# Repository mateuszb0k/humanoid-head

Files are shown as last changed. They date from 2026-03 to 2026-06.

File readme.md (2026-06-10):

# Humanoid Head

Humanoid Head is a modular robotics project focused on building an interactive humanoid robot head. The project combines computer vision, speech processing, natural language understanding, local language models, text-to-speech synthesis, servo-driven facial animation, and 3D-printed mechanical design.

The system is designed to recognize people, detect visible emotions, understand spoken questions, generate natural voice responses, and express emotions through physical facial movement.

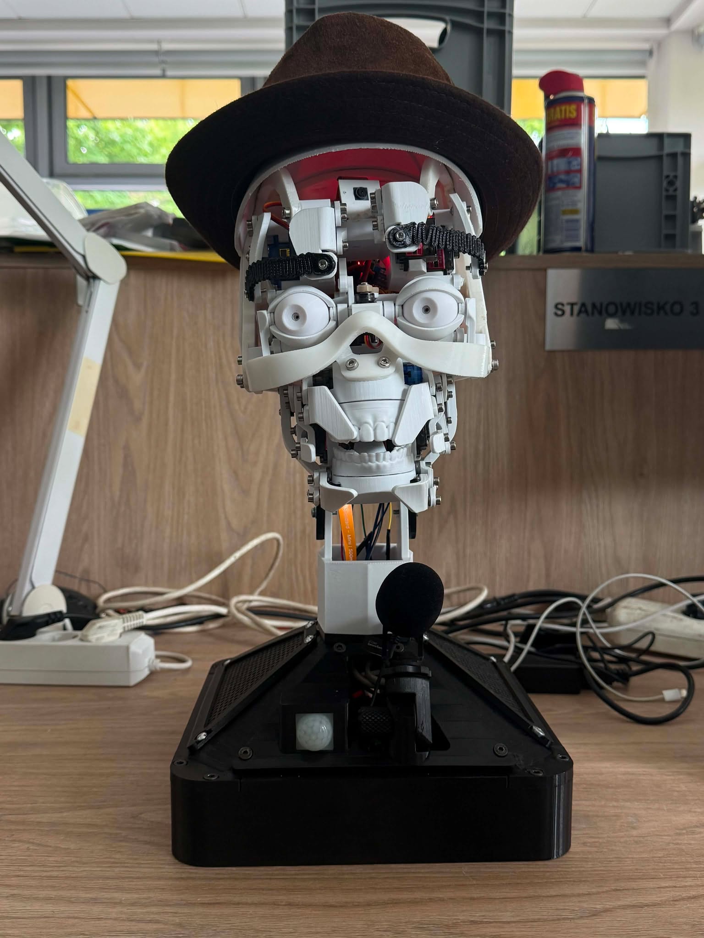
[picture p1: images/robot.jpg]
Uncanny head


## Project Overview

The robot head is built as a distributed system using two main computing devices:

- Raspberry Pi 5, responsible for vision processing, camera input, face recognition, emotion recognition, and facial actuation.
- NVIDIA Jetson Orin Nano, responsible for speech recognition, natural language processing, local language model inference, and speech synthesis.

The project is divided into three main modules:

- `vision-module`
- `speech-module`
- `hardware-module`

Each module was developed separately and later integrated into the final project.

## System Architecture

```text
User
 │
 │  voice, face, emotion
 ▼
Camera and Microphone
 │
 ├── Raspberry Pi 5
 │   ├── Face detection
 │   ├── Face recognition
 │   ├── Emotion recognition
 │   ├── Servo control
 │   └── Facial expression control
 │
 └── NVIDIA Jetson Orin Nano
     ├── Speech-to-text
     ├── Intent detection
     ├── Entity extraction
     ├── Local LLM response generation
     ├── Text-to-speech
     └── Conversation logic
```

The Raspberry Pi and Jetson communicate over the local network. The Raspberry Pi provides the speech pipeline with visual context, such as whether a person is visible, who the person is, and what emotion was detected. The Jetson generates spoken responses and sends mouth movement information back to the Raspberry Pi so that the robot jaw can move in sync with speech.

## How the Project Works

The project works as a real-time interaction loop between the user, the vision system, the speech system, and the physical robot head.

### 1. User Detection

The camera captures a live video stream. The vision module processes frames from the camera and searches for a visible face.

When a face is detected, the system determines:

- whether a person is currently in front of the robot,
- whether the person is already known,
- what emotion is visible on the face.

This information is sent to the speech module so that the robot can respond in a more context-aware way.

### 2. Face Recognition

The vision module can identify known users using stored face data. If the user is recognized, their identity is passed to the speech module.

This allows the robot to personalize its responses, for example by addressing the user by name or remembering context during an active interaction.

If the user is unknown, the system can treat the interaction as a new user session.

### 3. Emotion Recognition

The vision module classifies the user’s facial expression into emotional states such as:

- happy,
- sad,
- angry,
- fear,
- disgust,
- surprise,
- neutral.

The detected emotion is passed to the speech module and can also influence the robot’s physical facial expression.

The physical head supports servo-driven expression changes, allowing the robot to imitate or react to emotional states.

### 4. Speech Recognition

The speech module listens for the user’s spoken question or command.

Speech is converted to text using a speech-to-text pipeline based on Whisper or Faster Whisper. The transcribed text is then passed into the natural language processing pipeline.

The system is designed for spoken interaction, so the conversation flow assumes that the user is standing in front of the robot and speaking naturally.

### 5. Intent Detection

After transcription, the system determines what kind of request the user made.

The speech module can recognize different categories of intent, including:

- general conversation,
- weather questions,
- questions about rooms,
- questions about teachers,
- questions about auditoriums or special locations,
- project-specific or assistant-style questions.

Intent detection allows the system to choose whether it should answer using a local database, a rule-based lookup, or a local language model.

### 6. Entity Extraction

For location-related questions, the system extracts important entities from the user’s sentence.

Examples of extracted entities include:

- room numbers,
- building identifiers,
- teacher names,
- auditorium names,
- special places such as libraries, cloakrooms, or cafeterias.

The project uses GLiNER and supporting utility logic to detect and normalize these entities before searching the local data files.

### 7. Local Knowledge Lookup

For structured questions, the system searches local data files instead of relying only on a language model.

The speech module includes logic for:

- finding room directions,
- finding teacher room assignments,
- searching for special rooms,
- handling auditorium-related questions,
- retrieving weather information.

This gives the robot more reliable answers for known project-specific information.

### 8. Local LLM Response Generation

For general conversation, the system uses a local language model through Ollama and LangChain.

The language model receives context such as:

- the user’s question,
- recent conversation history,
- recognized user identity,
- detected emotion.

This allows the robot to generate more natural and context-aware spoken responses.

The prompt is designed specifically for a physical voice assistant. It avoids text-chat behavior and encourages natural spoken answers suitable for text-to-speech output.

### 9. Text-to-Speech

After generating a response, the speech module converts the text into audio using Piper TTS.

The generated audio is played through the speaker connected to the Jetson.

At the same time, the speech module estimates the audio intensity and sends mouth movement values to the Raspberry Pi. This allows the jaw servo to move in sync with the spoken response.

### 10. Facial Movement and Servo Control

The Raspberry Pi controls the robot’s servos through a servo controller.

The hardware system includes multiple servos responsible for facial movement, including areas such as:

- mouth,
- jaw,
- eyes,
- eyebrows,
- facial expression elements.

The system maps emotional states to predefined servo positions. For example, happy, sad, surprise, and neutral expressions are represented by different servo angle configurations.

Servo limits are defined to protect the mechanical structure and prevent unsafe movement.

## Module Descriptions

## Vision Module

The `vision-module` contains the computer vision and Raspberry Pi runtime code.

Main responsibilities:

- camera input,
- face detection,
- face recognition,
- emotion recognition,
- Raspberry Pi camera diagnostics,
- communication with the speech module,
- servo control integration,
- facial movement logic.

Important areas:

```text
vision-module/src/rpi/
vision-module/src/detection/
vision-module/model_training/
vision-module/preprocessing/
vision-module/documentation/
vision-module/images/
```

The main Raspberry Pi runtime is located in:

```text
vision-module/src/rpi/main_vision_network.py
```

This file combines the vision pipeline with robot control logic. It handles face visibility, identity, emotion, expression mapping, and communication with the rest of the system.

## Speech Module

The `speech-module` contains the Jetson-side speech and NLP pipeline.

Main responsibilities:

- speech-to-text,
- intent detection,
- entity extraction,
- local LLM interaction,
- text-to-speech,
- conversation memory,
- user identity handling,
- weather responses,
- room and teacher lookup,
- auditorium and special room lookup,
- communication with the Raspberry Pi.

Important files and directories:

```text
speech-module/nlp_pipeline.py
speech-module/nlp_pipeline_jetson_test.py
speech-module/utils/
speech-module/PiperTTS/
speech-module/db_specialrooms.json
speech-module/imiona_polskie.txt
```

The Jetson test pipeline is located in:

```text
speech-module/nlp_pipeline_jetson_test.py
```

This file orchestrates the main speech interaction loop. It receives data from the vision system, listens to the user, generates a response, speaks the answer, and sends mouth movement data back to the Raspberry Pi.

## Hardware Module

The `hardware-module` contains the mechanical and electronics-related project files.

Main responsibilities:

- 3D model storage,
- printed head structure documentation,
- servo placement documentation,
- circuit documentation,
- servo testing scripts,
- jaw synchronization experiments,
- face animation prototypes,
- hardware reports.

Important areas:

```text
hardware-module/3Dmodel/
hardware-module/Code/
hardware-module/DescServos/
hardware-module/Raports/
hardware-module/Circuit Diagram.pdf
```

The hardware module documents how the physical robot head is built and how the servos are assigned to facial movements.

## Data Flow

The project uses the following high-level data flow:

```text
Camera frame
   ↓
Face detection
   ↓
Face recognition and emotion recognition
   ↓
Identity and emotion sent to speech module
   ↓
User speaks
   ↓
Speech-to-text
   ↓
Intent detection and entity extraction
   ↓
Database lookup or local LLM response
   ↓
Text-to-speech
   ↓
Audio playback
   ↓
Mouth movement signal sent to Raspberry Pi
   ↓
Servo-controlled facial movement
```

## Communication Between Devices

The Raspberry Pi and Jetson communicate through HTTP endpoints over the local network.

The Raspberry Pi sends visual context to the Jetson, including:

- face visibility,
- recognized identity,
- detected emotion.

The Jetson sends mouth movement information to the Raspberry Pi, including:

- current speech volume level,
- jaw movement intensity,
- stop/reset mouth movement signal.

This split allows the Raspberry Pi to focus on real-time physical control while the Jetson handles heavier AI workloads.

## Conversation Logic

The conversation system is designed around real spoken interaction.

The assistant is prompted to behave as a physical robotic head rather than a text chatbot. It avoids responses that refer to typing, screens, chats, or written interaction.

The response generation logic considers:

- the current user,
- the detected emotion,
- the recent conversation history,
- the user’s latest question,
- whether the request should be answered from structured data or by the LLM.

The system also maintains a short conversation buffer so that responses can remain coherent during a session.

## Knowledge and Utility Features

The speech module includes several utility systems for specific types of questions.

### Room Search

The robot can answer questions about rooms by extracting room identifiers and searching local room data.

### Teacher Search

The robot can search for teacher information and provide room-related responses when the teacher exists in the local database.

### Auditorium and Special Room Search

The robot can respond to questions about auditoriums and selected special locations such as libraries, cloakrooms, or cafeterias.

### Weather

The robot can provide weather-related responses through the weather utility module.

## Facial Expressions

The robot can physically represent selected emotional states using servo positions.

Supported or planned expressions include:

- neutral,
- happy,
- sad,
- surprise,
- angry,
- fear,
- disgust.

Each expression is represented by a set of servo angle targets. These targets move different parts of the robot face to create a visible expression.

The emotion system is connected to both:

- detected user emotion,
- generated conversational state.

## Hardware Design

The physical head is based on a 3D-printed structure with multiple servos installed inside the face.

The hardware documentation includes:

- printable mechanical components,
- base structure,
- servo mapping,
- circuit diagram,
- assembly-related photos,
- test scripts,
- reports.

The servo system is designed to control facial motion while respecting mechanical limits.

## Technology Stack

### Hardware

- Raspberry Pi 5 8 GB
- NVIDIA Jetson Orin Nano Super 8 GB
- Raspberry Pi camera
- microphone
- speaker
- servo controller
- MG90s servos
- MG996r servos
- NVMe SSD
- DC-DC converters
- 3D-printed parts
- mechanical fasteners

### Software

- Python
- TensorFlow
- PyTorch
- OpenCV
- MediaPipe
- BlazingFace
- Whisper
- Faster Whisper
- Piper TTS
- GLiNER
- LangChain
- Ollama
- Flask
- PyAudio
- speech_recognition
- NumPy
- scikit-learn

## Development Branches

The project was developed across multiple branches.

### `master`

The main integration branch. It contains the merged version of the project with all major modules combined.

### `vision-module`

Contains the vision subsystem, including camera processing, recognition models, Raspberry Pi scripts, and visual-to-physical behavior integration.

### `speech-module`

Contains the speech and NLP subsystem, including STT, intent detection, GLiNER extraction, LLM response generation, TTS, and Jetson-side runtime logic.

### `hardware-module`

Contains the mechanical, electrical, and servo-related work, including 3D models, circuit diagrams, servo documentation, and hardware test code.

## Project Milestones

The project was planned around several technical milestones:

1. Building and validating the physical robot head structure.
2. Preparing power, servo, and mechanical control systems.
3. Creating a vision pipeline for recognition and emotion detection.
4. Creating a speech pipeline with STT, LLM, and TTS.
5. Running AI workloads across Raspberry Pi and Jetson hardware.
6. Integrating vision, speech, and facial actuation.
7. Testing real-time interaction with users.
8. Synchronizing jaw movement with generated speech.
9. Validating complete robot behavior in a controlled environment.

## Repository Language Composition

The repository is primarily written in Python, with additional Shell scripts and Jupyter Notebook content used for supporting tasks such as setup, testing, experimentation, or model-related work.

## Intended Use

This project is intended for research, prototyping, and educational development of an interactive humanoid robotic head.

It demonstrates how multiple AI and robotics components can be integrated into one physical system:

- perception,
- speech interaction,
- language understanding,
- local AI inference,
- mechanical expression,
- embedded device coordination.

## Notes

This project depends on correct hardware assembly, calibrated servos, configured camera and audio devices, local network connectivity between devices, and available machine learning model files.

Because the robot controls physical servos, all mechanical limits and power requirements should be checked carefully during development and testing.

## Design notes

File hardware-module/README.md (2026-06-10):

# Repository Structure: Hardware Module

This document provides a detailed overview of the directory structure and the contents of this repository.

## Directory Descriptions

### 3Dmodel
Contains the complete mechanical design and 3D assets for the robot's head assembly.
- **Photos**: A collection of images documenting the physical fabrication process, including both successful components and failed print attempts for reference.
- **Base**: Includes 3D models of electronic components (e.g., NVIDIA Jetson Nano) and the structural design of the robot's base.
- **head stl**: Contains individual .stl files for every component of the robot's head, optimized for 3D printing.
- **printing_progress.md**: A tracking file used to document the status and timeline of the 3D printing process for various parts.

### Code
Stores source code and scripts used during the development phase.
- Includes test scripts and firmware developed for Arduino and Raspberry Pi platforms to validate hardware functionality.

### DescServos
Dedicated to the robot's actuation system.
- Provides visual representations of servo placement within the assembly.
- Contains indexing and detailed descriptions mapping each servo to its specific anatomical movement or functional responsibility.

### Raports
A repository for documentation related to project management.
- Includes meeting minutes and formal progress reports generated by the hardware development team.

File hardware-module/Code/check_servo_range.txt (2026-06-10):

#include <Arduino.h>
#include <Wire.h>
#include <Adafruit_PWMServoDriver.h>

Adafruit_PWMServoDriver driver0 = Adafruit_PWMServoDriver(0x40); 
Adafruit_PWMServoDriver driver1 = Adafruit_PWMServoDriver(0x41);

#define PWM_MIN 150 
#define PWM_MAX 600 

struct ServoConfig {
  uint8_t driverID;
  uint8_t pin;          
  int minAngle;         
  int maxAngle;         
};

ServoConfig servos[21] = {
  {0, 0, 0, 180}, {0, 1, 0, 180}, {0, 2, 0, 180}, {0, 3, 0, 180}, {0, 4, 0, 180},
  {0, 5, 0, 180}, {0, 6, 0, 180}, {0, 7, 0, 180}, {0, 8, 0, 180}, {0, 9, 0, 180},
  {0, 10, 0, 180},
  {1, 0, 0, 180}, {1, 1, 0, 180}, {1, 2, 0, 180}, {1, 3, 0, 180}, {1, 4, 0, 180},
  {1, 5, 0, 180}, {1, 6, 0, 180}, {1, 7, 0, 180}, {1, 8, 0, 180}, {1, 9, 0, 180} 
};

int getPWM(int angle) {
  return map(angle, 0, 180, PWM_MIN, PWM_MAX);
}

void setup() {
  Serial.begin(9600);
  
  driver0.begin();
  driver0.setPWMFreq(50);

  driver1.begin();
  driver1.setPWMFreq(50);
}

void loop() {
  if (Serial.available() > 0) {
    int id = Serial.parseInt();
    int targetAngle = Serial.parseInt();

    while (Serial.available() > 0) Serial.read();

    if (id >= 0 && id < 21) {
      targetAngle = constrain(targetAngle, servos[id].minAngle, servos[id].maxAngle);
      int pulse = getPWM(targetAngle);
      
      if (servos[id].driverID == 0) {
        driver0.setPWM(servos[id].pin, 0, pulse);
      } else {
        driver1.setPWM(servos[id].pin, 0, pulse);
      }
      
      Serial.print("ID: "); Serial.print(id);
      Serial.print(" -> "); Serial.println(targetAngle);
    }
  }
}

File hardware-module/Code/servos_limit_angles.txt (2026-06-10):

servo 0 - tongue doesn't move
servo 1 - jaw max open 80, max closed 125
servo 2 - right corner upper servo, max down 50, max up 65
servo 3 - right upper lip, max down 20, max up 80
servo 4 - right corner lower servo, max down 50, max up 70
servo 5 - right lower lip, max down 25, max up 92
servo 6 - left lower lip, 110 max down, 45 max up
servo 7 - left corner lower servo, initially 60 down, 40 up
servo 8 - left upper lip, max down 85, max up 35
servo 9 - left corner upper servo, 10 max up, initially 40 max down
servo 10 - jaw works mirrored to servo 1
servo 11 - 80 close, 0 open // right eye lower eyelid
servo 12 - 115 degrees max open, 30 min (closed) upper eyelid
servo 13 - eyes up-down, 60 center, 120 max up, 40 max down
servo 14 - eyes right-left, 100 center, 50 max right, 150 max left
servo 15 - 90 close, 20 open // left eye upper eyelid
servo 16 - 90 open, 25 close lower eyelid
servo 17 - right eyebrow outside, 150 max up, 70 max down
servo 18 - right eyebrow center, 160 max down, 70 max up
servo 19 - left eyebrow center, 170 max up, 80 max down
servo 20 - left eyebrow outside, 100 max down, 20 max up

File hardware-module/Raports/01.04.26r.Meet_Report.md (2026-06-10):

# MEETING REPORT: Hardware Team – Robot Head Project
# Date: July 01, 2026
# Attendees: Szymon Mielniczak, Mateusz Kuczerowski, Adam Błażejewski, Patryk Jakiel
# Subject: Servo Configuration, Electrical Refinement & Movement Logic

---

## 1. MEETING OBJECTIVES
The primary goal was to define the software-to-hardware mapping, establish safety protocols for the servomechanisms, and plan the development of emotional expressions.

## 2. SOFTWARE & SERVO CONFIGURATION
* **Servo Addressing:** We initiated the process of mapping physical servos to their digital addresses in the control system.
* **Safety Limits:** The team discussed the necessity of establishing individual hardware limits (min/max PWM angles) for each servo to prevent mechanical binding and over-extension.
* **Movement Code:** Initial development of the servo control algorithms has begun, focusing on smooth transitions and coordinated movements.
* **Expression Logic:** Preliminary discussions took place regarding the implementation of "emotions" – mapping multiple servo movements to specific emotional states.

## 3. ELECTRICAL & MECHANICAL REFINEMENTS
* **Wiring Standards:** A plan was established to finalize the electrical schematic following the completion of servo addressing. 
* **Reliability:** We decided to rework the wire terminations using a crimping tool (crimper) to ensure professional and secure electrical connections.
* **Fastener Security:** To address the recurring issue of loosening screws in the lips and eyebrows, we evaluated two solutions:
    * Application of thread-locking fluid (Loctite/Threadlocker).
    * Integration of nylon-insert lock nuts (Nyloc) where space allows.

## 4. NEXT STEPS
* **Stand Design:** Work has officially started on the design of the robot head stand/base.
* **Execution:** During the next meeting, we will finalize the physical addressing and hard-code the safety limits for all servos.
* **Refining Connections:** Conduct a full recrimping of all connector ends to eliminate potential intermittent signal issues.

---
Prepared by: [Szymon Mielniczak]
Status: Finalized

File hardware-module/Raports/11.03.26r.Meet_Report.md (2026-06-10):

# MEETING REPORT: Hardware Team – Robot Head Project
# Date: March 11, 2026
# Attendees: Szymon Mielniczak, Mateusz Kuczerowski, Adam Błażejewski, Patryk Jakiel
# Subject: CAD Model Analysis & Hardware Specification

---

## 1. MEETING OBJECTIVES
The primary goal was to analyze the main CAD assembly in Fusion 360, finalize the decomposition of components for manufacturing, and establish the requirements for fasteners and custom parts.

## 2. FUSION 360 ANALYSIS & ASSEMBLY STRATEGY
* **Model Decomposition:** The master assembly has been successfully separated into individual components (Internal Frame, Actuation Mechanisms, and External Shell).
* **Assembly Plan:** The team has analyzed the construction in detail and established a clear workflow for the assembly process in the coming weeks. We have a full understanding of the sequence required to integrate the internal skeleton with the outer casing.
* **Design Review:** A structural analysis was conducted to ensure that all 3D-printed parts are optimized for assembly and mechanical durability.

## 3. HARDWARE & FASTENERS SPECIFICATION
The following components have been selected for the build:

* **Screws:** Socket Head Cap Screws (Allen/Hex drive) in sizes **M2.5, M3, and M4**. 
    * We will use various lengths depending on the joint, with a **maximum length of 10mm**.
* **Washers:** Standard flat and spring washers.
* **Nuts:** Standard hex nuts.
* **Threaded Inserts:** **IMPORTANT: We will use bidirectional (two-way) threaded inserts** to ensure maximum pull-out resistance and stability within the 3D-printed parts.
* **Custom Spacers:** The team will design and 3D print custom bushings/spacers to ensure precise alignment of internal mechanisms.

## 4. NEXT STEPS
* **Custom Part Design:** Finalize CAD models for the 3D-printed spacers in Fusion 360.
* **Shopping:** Purchase the rest of the needed equipment, including servos, screws, and other mechanical components.
---
Prepared by: [Szymon Mielniczak]

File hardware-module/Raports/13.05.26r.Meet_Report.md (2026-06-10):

# MEETING REPORT: Hardware Team – Robot Head Project
# Date: May 13, 2026
# Attendees: Szymon Mielniczak, Mateusz Kuczerowski, Adam Błażejewski, Patryk Jakiel
# Subject: Hardware Fixes, I2C Resolution & Assembly Updates

---

## 1. MECHANICAL & HARDWARE UPDATES
* **Servo Replacement:** Faulty servos were successfully replaced.
* **Wiring Resolved:** The power supply cables for the servo controllers were replaced, ensuring proper reach and connectivity.
* **Assembly Integrity:** Threadlocker (klej do gwintów) was applied to all necessary joints to secure the mechanical structure against vibrations.

## 2. SOFTWARE & COMMUNICATION
* **I2C Communication:** The issue preventing communication between the Raspberry Pi 5 and the servo controllers via I2C has been fully resolved. The system now correctly addresses the PWM drivers.
* **Camera & Face Tracking:** The camera was successfully configured and synchronized with eye movements. Face tracking via eyes is now fully operational.

---
Prepared by: [Patryk Jakiel]
Status: Milestone 3 Active

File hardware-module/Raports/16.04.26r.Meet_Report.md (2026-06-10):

# MEETING REPORT: Hardware Team – Robot Head Project
# Date: April 16, 2026
# Attendees: Szymon Mielniczak, Mateusz Kuczerowski, Adam Błażejewski, Patryk Jakiel
# Subject: Mechanical Stabilization, Emotional Logic & Raspberry Pi Migration

---

## 1. MEETING OBJECTIVES
The focus was on improving fastener reliability in moving parts, finalized the software implementation of facial expressions, and initiated the transition to a Raspberry Pi-based control system.

## 2. MECHANICAL ADJUSTMENTS
* **Eyebrows:** Successfully replaced standard nuts with **nylon-insert lock nuts (Nyloc)** to prevent loosening during movement.
* **Lips:** A direct nut replacement was not possible as the existing nuts were heat-set into the 3D-printed parts during assembly.
    * **Proposed Fix:** The team will apply thread-locking fluid to these specific points to secure the fasteners without redesigning the parts.
* **Base/Stand Design:** Continued work on the head stand, specifically focusing on the internal layout and placement of electronics.

## 3. SOFTWARE & SYSTEM INTEGRATION
* **Emotional Expressions:** Completed the development of code functions for all required emotional states. Each expression is now mapped to specific servo configurations.
* **Platform Migration:** Work has begun on converting the existing control logic from Arduino to **Raspberry Pi**. This shift aims to provide more processing power for future high-level tasks.
* **Component Layout:** We started designing the arrangement of the Raspberry Pi, drivers, and power modules within the upcoming base unit.

## 4. NEXT STEPS
* **Threadlocker Application:** Apply the thread-locking adhesive to the lip mechanisms.
* **Code Testing on Pi:** Verify that the servo control functions via Raspberry Pi (GPIO/I2C) maintain the same precision as the previous Arduino setup.
* **Finalizing the Base:** Complete the CAD model of the stand with the confirmed component layout.

---
Prepared by: [Szymon Mielniczak]
Status: Finalized

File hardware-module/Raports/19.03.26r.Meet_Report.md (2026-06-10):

# MEETING REPORT: Hardware Team – Robot Head Project
# Date: March 19, 2026
# Attendees: Szymon Mielniczak, Mateusz Kuczerowski, Adam Błażejewski, Patryk Jakiel
# Subject: Assembly Start, Servo Testing & Driver Integration

---

## 1. MEETING OBJECTIVES
The primary goals were to begin the physical assembly of the robot head, verify the functionality of all servo motors using test scripts, and finalize the setup of the PWM drivers.

## 2. ASSEMBLY PROGRESS
* **Lower Jaw & Lips:** Successfully assembled the lower jaw and bottom lip mechanisms.
* **Eyes:** Assembly of the eye mechanisms has commenced.
* **Technical Challenges:** We identified structural issues with small linkage elements in the eyes and lips. Several 3D-printed parts proved to be too brittle and prone to cracking during assembly.

## 3. ELECTRONICS & FIRMWARE TESTING
* **Servo Verification:** * All **19 MG90S** servos were tested. One unit was found to be defective and was replaced with a spare from private resources.
    * Both **MG996R** servos were confirmed to be fully functional.
* **Driver Integration:** * Both **PCA9685 PWM drivers** were tested and are operational. 
    * The team gained hands-on experience with the drivers' API and successfully established control over the servo channels using custom test code.

## 4. NEXT STEPS
* **Design Iteration:** Redesign the brittle linkage components for the eyes and lips to improve mechanical durability.
* **Manufacturing:** Generate and prepare new print files (G-code/STL) for the reinforced parts.
* **Eyes Completion:** Finalize the assembly of the eye mechanisms once the new parts are printed.
* **Integration:** Begin planning the mounting of the PCA9685 drivers and the power distribution for the MG996R servos.

---
Prepared by: [Szymon Mielniczak]

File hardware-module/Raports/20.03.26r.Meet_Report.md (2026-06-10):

# MEETING REPORT: Hardware Team – Robot Head Project
# Date: March 20, 2026
# Attendees: Szymon Mielniczak, Mateusz Kuczerowski, Adam Błażejewski, Patryk Jakiel
# Subject: Mechanical Assembly Progress & Servo Control Testing

---

## 1. MEETING OBJECTIVES
The primary goals were to replace the previously broken components, complete the assembly of the jaw and lip structures, and conduct initial movement tests for the eye mechanisms.

## 2. ASSEMBLY PROGRESS & TECHNICAL ISSUES
* **Jaw & Lips:** The full structure of the lower jaw and lips has been successfully completed.
* **Eyes:** The eye mechanisms were assembled. However, some structural components failed again during the process.
* **Structural Failures:** We encountered further breakage in the lip linkages and the **nose cover**. 
* **Fastener Stability:** A potential long-term issue was identified: screws may loosen over time due to mechanical vibrations. 
    * **Proposed Solution:** Use thread-locking fluid (threadlocker) in future assembly stages.

## 3. ELECTRONICS & CONTROL TESTING
* **System Setup:** We used a **Laboratory Power Supply**, an **Arduino Uno**, and custom-written test code to drive the servos.
* **Eye Movement:** Successfully controlled and verified the range of motion for the eye servos. The integration between the software and the mechanical linkages was confirmed, despite the fragile parts.

## 4. NEXT STEPS
* **Manufacturing:** Prepare and export new print files (STL/G-code) for the broken components, specifically the eye linkages and the **nose cover**.
* **Reinforcement:** Review the CAD models for the failing parts to identify if further thickening or a change in print orientation is required before the next assembly attempt.
* **Maintenance Planning:** Procure thread-locking adhesive for the final assembly.

---
Prepared by: [Szymon Mielniczak]
Status: Finalized

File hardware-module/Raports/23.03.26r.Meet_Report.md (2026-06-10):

# MEETING REPORT: Hardware Team – Robot Head Project
# Date: March 23, 2026
# Attendees: Szymon Mielniczak, Mateusz Kuczerowski, Adam Błażejewski, Patryk Jakiel
# Subject: Full System Integration & Power Management

---

## 1. MEETING OBJECTIVES
The primary goals were to complete the mechanical assembly of the head (excluding the occiput), perform synchronized servo calibration, and conduct a full-scale movement test using an external power source.

## 2. ASSEMBLY PROGRESS & CHALLENGES
* **Eyebrows & Main Assembly:** The eyebrow structure is finished, and all modules have been integrated into a single unit, except for the **occiput** (back of the head), which requires a reprint due to a previous manufacturing error.
* **Component Replacement:** Most required parts were successfully 3D printed and installed.
* **Structural Failures:** We encountered new breakages in different linkage elements within the eye mechanisms. This remains a critical area for structural optimization.

## 3. ELECTRONICS & POWER CALIBRATION
* **Power Management:** We integrated a voltage regulator (amplifier/step-down) into the circuit and calibrated it to a steady **5V output** to ensure safe operation for the electronics.
* **Servo Synchronization:** Successfully implemented mirrored and synchronized movement for the jaw servos.
* **Full-Scale Testing:** Conducted a comprehensive test of all installed servomechanisms. The system was powered by a laboratory power supply and controlled via **Arduino Uno** using a dedicated full-system test script.

## 4. NEXT STEPS
* **Occiput Reprint:** Correct the CAD/slicing errors for the occiput and start the long-format print.
* **Mechanical Refinement:** Address the recurring failures in the eye linkages; investigate if the synchronized movements are putting unexpected stress on these specific parts.
* **Final Assembly Preparation:** Once the occiput is ready, proceed with the final enclosure of the head.

---
Prepared by: [Szymon Mielniczak]
Status: Finalized

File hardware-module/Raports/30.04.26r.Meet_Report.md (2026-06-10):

# MEETING REPORT: Hardware Team – Robot Head Project
# Date: April 30, 2026
# Attendees: Szymon Mielniczak, Mateusz Kuczerowski, Adam Błażejewski, Patryk Jakiel
# Subject: Mechanical Integration, System Migration & Milestone 2 Planning

---

## 1. MEETING OBJECTIVES
The primary goals were to integrate the major structural modules (Head, Neck, and Stand), continue the software migration to Raspberry Pi, and establish a clear action plan for the project's second milestone.

## 2. MECHANICAL & HARDWARE INTEGRATION
* **Neck Redesign:** The upper neck section was redesigned and updated to improve structural stability and range of motion.
* **Full Assembly:** The head, neck, and stand have been physically joined into a single unit.
* **Wiring Issue:** A technical bottleneck was identified—the power supply cables are too short to reach from the base to the servo drivers located in the head.
    * **Action:** Patryk is assigned to extend the wiring harness.
* **Jaw Stress Test:** We are preparing a test to verify if a single servo has enough torque to reliably operate the jaw mechanism in its final configuration.

## 3. SOFTWARE MIGRATION
* **Arduino to Raspberry Pi:** The conversion of the core control logic to the Raspberry Pi platform is ongoing. The team is focusing on ensuring I2C communication stability with the PWM drivers.

## 4. MILESTONE 2 ACTION PLAN
The team established the following 11-point roadmap for the upcoming phase:
1. **Face Tracking:** Implement real-time facial recognition and tracking.
2. **Lip Sync:** Synchronize jaw movement with speech patterns.
3. **Pi Code Verification:** Final validation of the control scripts on the Raspberry Pi.
4. **Microphone Integration:** Install and configure the audio input module.
5. **Camera Integration:** Mount and calibrate the visual sensor.
6. **PIR Sensor:** Add a Passive Infrared sensor for motion detection.
7. **Speaker Integration:** Install and test audio output.
8. **Wiring Extension:** Patryk to finalize the elongated cable management.
9. **System Synthesis:** Integrate hardware modules with the broader project ecosystem.
10. **Jaw Torque Test:** Practical verification of jaw servo performance.
11. **Mechanical Refinement:** Perform final corrections on 3D-printed mechanical parts.

---
Prepared by: [Szymon Mielniczak]
Status: Finalized / Milestone 2 Active

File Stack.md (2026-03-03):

# Stack technologiczny – Uncanny Head

## Hardware

- Serwomechanizmy MG90s (19 szt.)
- Serwomechanizmy MG996r (2 szt.)
- Raspberry Pi 5 8 GB
- Filament biały
- Mikrofon
- Głośnik
- Kamera
- Czujnik ruchu
- Sterownik do serw
- Karta SD
- Zasilacz do RPI 5
- Taśma do kamery
- Jetson Orin Nano Super 8GB oraz dedykowany zasilacz
- Dysk SSD NVMe
- Przetwornice napięcia (DC-DC)
- Elementy łączeniowe oraz elementy mechaniczne (śrubki, nakrętki)

## Software

- TensorFlow
- OpenCV
- Python
- C/C++
- BlazingFace
- MediaPipe
- Ollama
- LLM (gemma3, ministral3)
- STT (openai whisper)
- TTS (pyttsx3, piper)
- PyTorch
- GLiNER
- Pyaudio
- speech_recognition

## Komunikacja

- LangChain
- Git / GitHub

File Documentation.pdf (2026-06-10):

# Uncanny Head Documentation

## Contents

1 Introduction and Objective of the Report | 1
2 Hardware System | 4
2.6.2 | Vibration Problem: Self-Locking Nuts and Threadlocker . . . . | 6
3 Vision System | 9

4 Speech System | 45

## 1 Introduction and Objective of the Report

The primary objective of the “Uncanny Head” project is to design, construct, and implement an anthropomorphic robotic head capable of two-way, natural communication with humans and the expression of selected emotional states. The assistant was specifically developed with the students of the Gdask University of Technology in mind, aiming to provide precise navigation directions within university buildings, deliver upto-date information about weather conditions, and engage in casual conversations using artificial intelligence.
This documentation provides a comprehensive description of the engineering and software development work divided into three cooperating modules:
- Hardware System: Documents the mechanical structure optimized for FDM/SLA 3D printing, the implementation of the physical actuation system consisting of 21 servomechanisms (19x MG90s and 2x MG996r), and the power architecture designed to strictly separate logic and drive lines to ensure stable operation of the Raspberry Pi 5 and NVIDIA Jetson Orin Nano single-board computers.
- Vision System: Describes the multi-stage dataset preprocessing and informational noise reduction pipeline (encompassing pHash deduplication, demographic filtering, and artifact removal using EasyOCR and CLIP), synthetic dataset generation using the 12-billion-parameter Flux.2 model, and the training of deep convolutional neural networks (CNNs) for classification across seven emotional states.
- Speech System: Outlines the core implementation of the natural language processing (NLP) pipeline operating in a real-time continuous loop, which incorporates voice transcription via Whisper STT, spaCy-powered intent routing, structured JSON databases for deterministic navigation retrieval, and speech synthesis via PiperTTS.

### 1.1 Final Result

The successful integration of these individual modules resulted in a fully functional, real-time robotic prototype capable of dynamic environmental interaction. In the emotion classification domain, the fine-tuned ConvNeXt Tiny architecture achieved the highest performance, peaking at a validation accuracy of 74.56% and surpassing custom-designed CNN topologies such as the top-performing “second_model” (71.04% accuracy).
The finalized vision pipeline utilizing YuNet and SFace was successfully deployed on the target Raspberry Pi 5 platform, where the inclusion of a dedicated active cooling solution resolved severe thermal throttling under full workload, dropping the SoC temperature by 30◦C and ensuring system stability over prolonged interaction periods. Furthermore, the speech subsystem minimized perceived response latency by utilizing multithreading and an asynchronous sentence-level streaming architecture, allowing the robot to begin vocalizing responses generated by the Gemma 3 model almost instantly via the PiperTTS engine.


Figure 1: Uncanny head

## 2 Hardware System

All files related to the hardware team’s work have been placed in a structured repository. Below is a detailed description of the individual directories.

### 2.1 Directory 3Dmodel

This directory contains the complete mechanical design documentation and 3D assets necessary to build the head.

- Photos: A collection of photos documenting the physical production process. It includes both photos of correctly printed and assembled elements, as well as a log of failed print attempts (so-called "failed prints"), which serve as reference and educational material for the future.
- Base: Includes 3D models of the robot’s base elements and dedicated mounts for main electronic components (e.g., NVIDIA Jetson Orin Nano).
- head stl: The most important folder for the printing process, containing exported files in .stl format for every single component of the robot’s head, optimized for FDM/SLA printing.
- printing_progress.md: A tracking file used by the team to mark the printing status of individual batches (e.g., in queue, printing, ready, to be improved).

### 2.2 Directory Code

Although the main high-level logic lies on the Software module side, the Hardware team has prepared a repository for scripts necessary to verify the hardware.

- This contains test scripts written in Python and C++ intended for Arduino and Raspberry Pi platforms.
- The subdirectory hardware/code/ contains the key file servos_limit_angles.txt, containing the maximum and minimum safe deflection angles for the servo horns.

### 2.3 Directory DescServos

Folder dedicated to the physical actuation system.

- Contains visualizations (diagrams/renders) showing the precise location of each of the 21 servomechanisms inside the head.
- Includes indexing files that map each servo identifier to its specific anatomical function (e.g., Servo no. 4 - left eyebrow, Servo no. 12 - eyeball movement in the X axis).

### 2.4 Directory Raports

Project management and communication section.

- Stores concise meeting minutes.
- Contains formal progress reports generated by the hardware team for synchronization with the developers.

### 2.5 Bill of Materials (BOM)

The table below presents a complete list of hardware, electronic parts, and fasteners used in the project.

Category | Component | Quantity
Actuators | MG90s Servomechanisms (metal gears) | 19 pcs
| MG996r Servomechanisms (High-Torque) | 2 pcs
| Servo controller (e.g., PCA9685) | 2 pcs
Logic and AI | Raspberry Pi 5 8GB | 1 pc
| NVIDIA Jetson Orin Nano Super 8GB | 1 pc
| SD Card (for RPi) | 1 pc
| NVMe SSD (for Jetson) | 1 pc
Sensors | Camera with ribbon cable (MIPI CSI) | 1 pc
| Camera ribbon cable (extended) | 1 pc
| Directional microphone / audio matrix | 1 pc
| Speaker | 1 pc
| Motion sensor (PIR / TOF) | 1 pc
Power Supply Dedicated power supply for RPi 5 | 1 pc
| Dedicated power supply for Jetson Orin Nano | 1 pc
| Voltage converters (DC-DC Step-Down) | Multiple
Mechanics | White Filament (PLA/PETG) | N/A
| Allen screws (M2, M3, M4) | Set
| Self-locking nuts with insert | Set
| Threadlocker | 1 pc

Table 1: BoM (Bill of Materials) table for the Uncanny Head module.

### 2.6 Assembly and Mechanical Guidelines

The physical assembly process of the printed head elements required special precision. Below are the best practices that significantly improved the rigidity and reliability of the structure.

### 2.6.1 Use of Allen Screws

Standard Phillips screws were abandoned in favor of socket head cap screws for Allen keys (sizes M2, M3, and M4). Their main advantages are:

- Significantly higher tightening torque without the risk of ’cam-out’ of the socket.
- Easier access in tight spaces inside the robot’s skull ball-end Allen keys allowed for tightening screws at an angle.

### 2.6.2 Vibration Problem: Self-Locking Nuts and Threadlocker

The robot’s head is set in motion by 21 servomechanisms. Their simultaneous operation generates micro-vibrations, which during the prototyping phase led to the rapid unscrewing of the frame. Implemented solutions:

1. Self-locking nuts: Nuts equipped with a polyamide/nylon insert ("like with glue") were used. The thread cuts into the material, creating a tight connection that prevents spontaneous unscrewing.
2. Threadlocker: In places where the thread was screwed directly into brass heatset inserts or where loads were critical (especially around the jaw and neck operated by strong MG996r servos), an anaerobic threadlocker was used. Tip: Use a medium-strength threadlocker (e.g., blue) to allow for potential disassembly for maintenance purposes.

### 2.7 Electronics, Power Supply, and Wiring

### 2.7.1 Power Architecture

The biggest hardware challenge in the project is the stable power supply for a system with as many as 21 motors (19x MG90s, 2x MG996r) and two advanced SBC computers. Servomechanisms at the moment of simultaneous start-up can draw total currents of several amperes. For this reason, the power circuits for logic and drives were strictly separated:

- Logic: Raspberry Pi 5 and Jetson Orin Nano have their own dedicated power supplies connected to separate sockets (or powered by an adequately powerful central power supply with dedicated lines).
- Drives: Voltage converters (DC-DC) were used, which step down the high input voltage of the main power supply to the stable 5V required by the servos.

### 2.7.2 Control and Drive System Wiring Diagram

The complete electrical wiring diagram can be found in the corresponding file in the project’s root directory (path: hardware/Circuit Diagram.pdf).

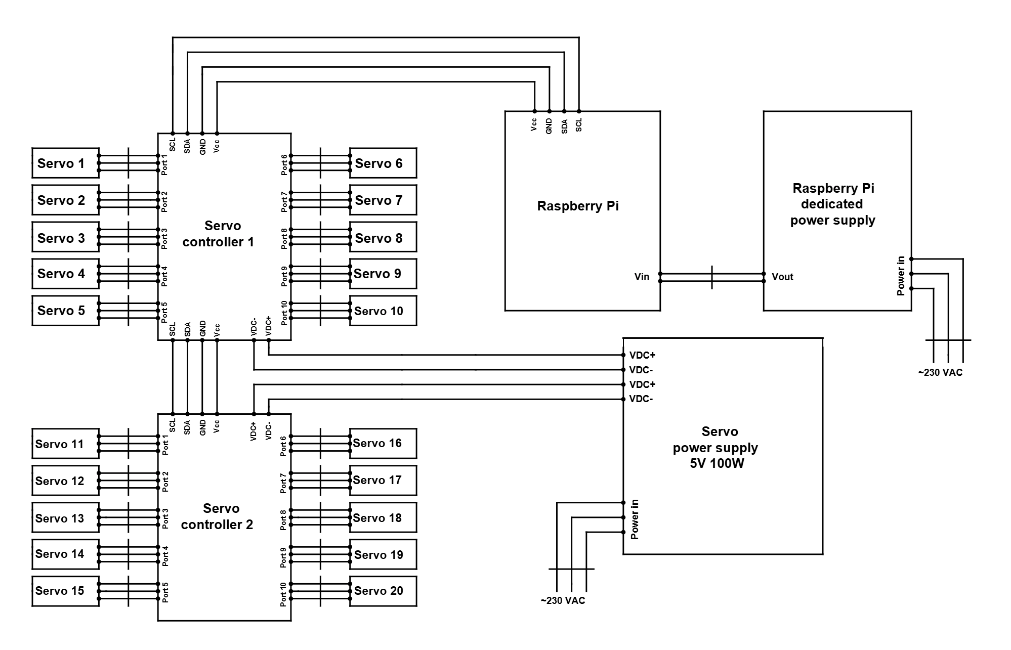
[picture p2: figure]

Figure 2: Electrical wiring diagram

### 2.8 Actuation System and Movement Limits

### 2.8.1 Division of Servomechanism Roles

The project utilizes two types of actuators:

- MG90s (19 pcs): Responsible for facial micro-movements. They handle, among others, eyelids, eyeballs (X and Y axis), lip movements, eyebrows, and cheeks.
- MG996r (2 pcs): Motors with very high torque, used to operate the heavy jaw structure.

Detailed servo numbering can be found in the hardware/descServos directory.

### 2.8.2 Hardware Protection - Angle Limits

The hardware team was entrusted with the crucial task of determining the mechanical operating limits of each servo. Sending a PWM value outside these limits would lead to a collision of printed elements and the instant burning of the motors.
The calibrated values are saved in the hardware/code/servos_limit_angles.txt file.
Assembly Warning: Before attaching the servo horns (levers on the servo spline), you must connect the servos to power, set them to the home position using the test script from the Code folder, and only then mechanically connect them to the linkages in the head.

## 3 Vision System

### 3.1 A word of introduction

The primary goal of the project is to construct a robotic head with anthropomorphic features, capable of two-way communication with the user and the expression of three selected emotional states. The entire system has been divided into cooperating modules. The scope of work for the described team covers the design and implementation of the visual perception module (the robot’s vision system). The main task of this module is to detect the user’s face in a video stream and extract its characteristic points (facial landmarks). The data obtained in this way will be used to build a profile database, enabling the system to identify returning individuals and initiate personalized interaction (e.g., greeting the user by name). Another key element of the vision module is the implementation of a classifier that recognizes the user’s affective states. The algorithm is intended to recognize seven emotion classes: anger, sadness, fear, surprise, disgust, happiness, and a neutral state. In the final phase of model design and optimization, a classification accuracy of approximately 75 percent is assumed. The output data from the vision module (identified identity and recognized emotion) will be passed to the speech synthesis subsystem. This will enable dynamic adjustment of both the content and acoustic parameters of the robot’s speech to the interlocutor’s current emotional state.

### 3.2 Technological Stack

Initial project assumptions included the use of the BlazeFace [1] model for face localization and the MediaPipe [2] framework for facial landmark extraction. These solutions are characterized by very high precision, however preliminary tests on the target hardware platform revealed excessive load on the computational resources, which prevented smooth real-time operation. For this reason, the final software implementation is based on more optimal and lightweight models:

- Face Detection and Alignment: The OpenCV YuNet model is used for fast and efficient face localization in image frames. This model provides the high performance required in real-time operating systems.
- User Identification (Face Recognition): For face recognition and feature extraction, the system utilizes the SFace algorithm, which analyzes cropped face images to reliably verify user identities. The identity verification process generates a feature vector (embedding), and recognition is performed by computing the cosine similarity between the generated vector and reference vectors stored in the system’s database.

### 3.3 Dataset preprocessing

### 3.3.1 Search for datasets

The process of acquiring data sets encountered limitations resulting from licensing restrictions, making it impossible to use them for design purposes.Resource exploration was carried out within key repositories and analytics platforms, such as GitHub, Kaggle and Hugging Face.The analyzed datasets often aggregated popular datasets such as FER-2013, RAF-DB, and AffectNet, supplemented with resources obtained from Google Images and unknown sources. The process of verifying and correctly classifying them required a multi-stage analysis, combining manual methods with algorithmic detection of duplicates. The data set from the Hugging Face platform, generated synthetically using the Gemini 2.0 model, proved to be a particular challenge. This collection was characterized by low annotation quality, and analysis of related JSON files revealed inconsistencies in structure and the inability to correctly categorize photos. Ultimately, the data sets compiled in Figure 3 were selected for the project.

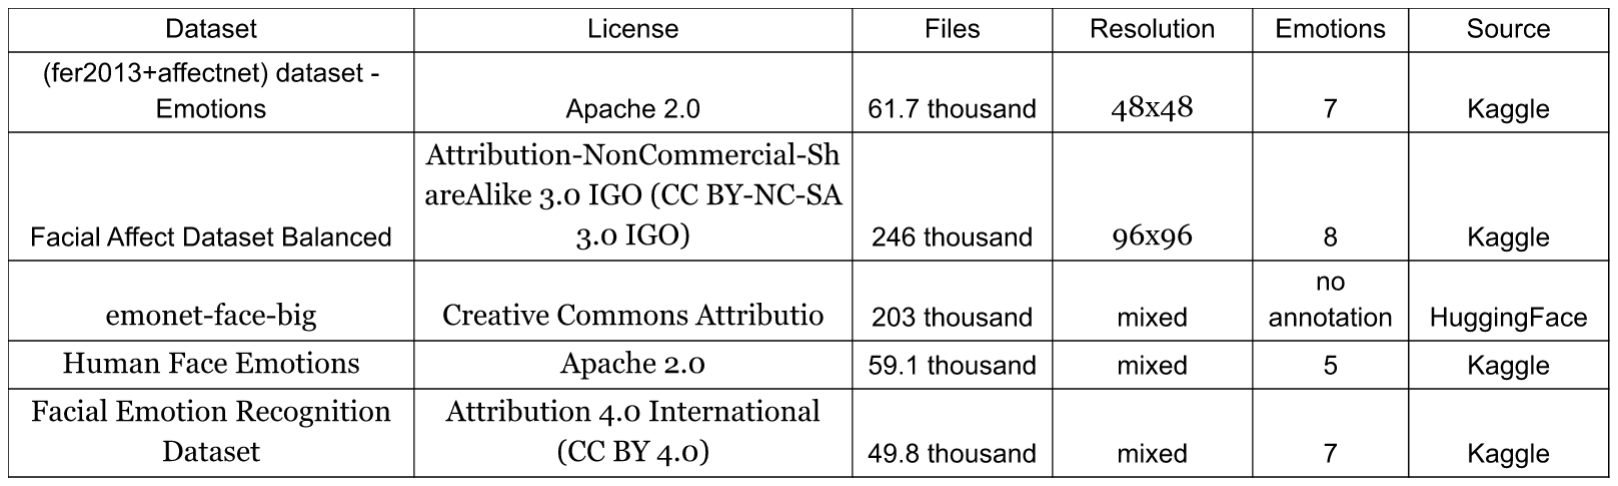
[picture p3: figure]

Figure 3: List of used datasets

### 3.3.2 Deduplication and augmentation filtering

The first and most drastic step in reducing informational noise was deduplication. A custom script utilizing the perceptual hashing (pHash) algorithm was implemented for this purpose. Unlike standard methods that compare files byte by byte, pHash analyzes the visual structure of the photographs. This allowed for the effective detection and removal of duplicates even in cases where the images differed in resolution, format, or had previously undergone minor artificial augmentation.
To optimize computation time, the hash generation process was parallelized using multithreading. The algorithm continuously cached the unique image signatures. Any new photograph whose generated hash was already in the set was immediately classified as a duplicate and rejected. This step was essential to avoid data redundancy and uncontrolled sample growth. The process was highly effective, rejecting 83,380 duplicated photographs. A detailed breakdown of the deduplication results for individual emotion classes is presented in Table 2.
Category Identified (Initial) | Kept | Removed (Duplicates)
Neutral | 24054 | 21888 | 2166
Happy | 48434 | 26309 | 22125
Sad | 32766 | 17540 | 15226
Angry | 28749 | 15326 | 13423
Fear | 28388 | 15368 | 13020
Disgust | 13437 | 9799 | 3638
Surprise | 26732 | 12950 | 13782
Total | 202560 | 119180 | 83380

Table 2: Summary of the deduplication process by emotion category

### 3.3.3 Face detection and demographic filtering

Due to the presence of shots in the raw dataset that did not contain human faces (e.g., inanimate objects, road signs), the dataset was passed through a face detection algorithm. Examples of samples rejected at this stage are shown in Figure 4.

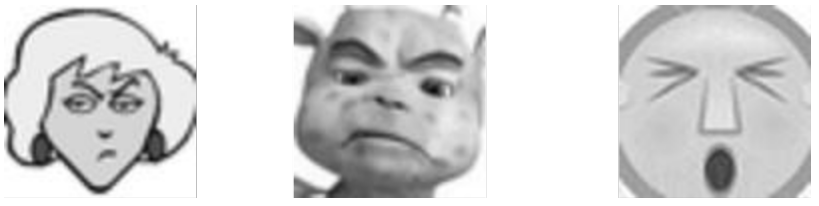
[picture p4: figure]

Figure 4: List of Bad Photos

Subsequently, the dataset of 119,180 photographs was filtered based on demographic criteria. In accordance with the project’s assumptions, images depicting children’s faces were removed. This filtration phase reduced the dataset by 7,143 samples, leaving a base of 112,037 images for further processing.

### 3.3.4 Artifact removal and manual visual verification

In the penultimate phase, a dedicated algorithm was implemented to remove text overlays and watermarks from the images. The EasyOCR library with GPU hardware acceleration was utilized for this task. The tool scanned each image for alphanumeric characters. If a text string consisting of more than two letters was detected, the system automatically classified the sample as contaminated and moved it to a rejection folder. This eliminated informational noise that could disrupt the neural network’s extraction of key features.
The automated process was supplemented by the most time-consuming stage: manual inspection of the data. The combined efforts of the OCR algorithm and manual review allowed for the exclusion of animated graphics, drawings, and shots characterized by partial occlusion of the face, which prevented accurate analysis of facial expressions. This resulted in a total of 7,840 defective samples being removed. Following these steps, the dataset was reduced to 104,197 images.

### 3.3.5 Annotation correction

The verification revealed numerous errors in the original class labels, resulting from the automated aggregation of data from various sources. Incorrectly classified images were re-annotated. Samples with ambiguous expressions that could not be unambiguously assigned to a specific emotion were permanently removed from the dataset. Examples of original misclassification are illustrated in Figure 5 (default labels, from left: Fear, Sadness, Neutral).

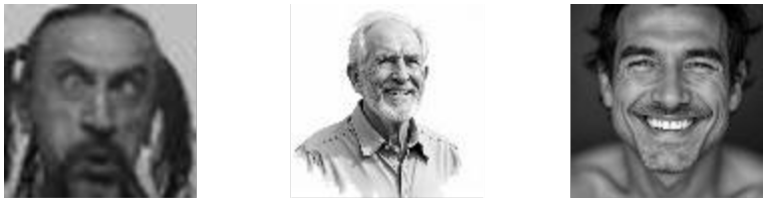
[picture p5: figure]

Figure 5: List of bad annotated photos

After completing all the aforementioned cleaning, filtering, and correction steps, the final dataset ready for model training stabilized at the level of 104,197 selected and normalized images.

### 3.3.6 Exp-W Dataset Integration

To further enrich the training corpus and improve the model’s generalization capabilities, the Exp-W dataset (Cleaned version) [9] was incorporated into the project. The initial set contained 19,290 images. To maintain strict consistency with our quality standards, this supplementary dataset was subjected to the identical preprocessing pipeline:

- Deduplication (pHash & BK-Tree): Utilizing the perceptual hashing algorithm combined with a BK-Tree data structure for efficient similarity searching. This approach allowed for sub-linear time complexity during duplicate detection. 13 duplicate images were identified and removed.
- Artifact Removal (EasyOCR): The EasyOCR library was utilized to scan for text overlays. A safety threshold of 2 characters was established to avoid false positives from compression artifacts. This filter discarded 25 contaminated images.
- Demographic Filtering (ViT-Age): To automate the removal of images depicting children, we implemented a pre-trained Vision Transformer model (nateraw/vit-age-classifier). The pipeline specifically targeted the "0-2" age category (infants/toddlers). This phase reduced the dataset by 2,014 samples.
- Non-photorealistic Image Removal (CLIP): To eliminate caricatures, 3D renders, and cartoons, we employed the CLIP (Contrastive Language-Image Pre-training) model developed by OpenAI (clip-vitbasepatch32). Using zero-shot classification, the system compared each image against two textual prompts: "a photo of a real human face" vs. "a drawing, cartoon, anime, illustration or sketch". Images with a "drawing" probability exceeding a 0.8 threshold (294 samples) were moved to the rejection folder.

Following this comprehensive, multi-model filtration process, 16,944 highly reliable images were successfully extracted and merged into the final database.

### 3.4 Images generated with Flux.2

To expand our dataset with additional images, we used generative artificial intelligence models. Our choice fell on the advanced Flux.2 [dev] [10] model, featuring 12 billion parameters. An attempt to run it in the Kaggle Notebook environment proved suboptimal generating a single image took approximately 5 minutes. For this reason, we conducted the initial model tests through the Hugging Face platform. The resulting images were highly consistent with the scientific definitions of individual facial expressions, as illustrated in Figure 6. We prepared a base of 10,000 text prompts for image generation, focusing exclusively on generating human faces expressing the seven basic emotions. We also ensured that the dataset was appropriately balanced in terms of ethnic diversity. Due to the nature of the project and the intended placement of our robot’s head, we restricted the generated images to children’s faces aged 4 and above. A sample input data structure is as follows: "prompt": "headshot of sad 10 year old European boy, drooping eyelids with loss of eye focus, lips slightly pulled down at corners, grieving expression, overcast outdoor light, highly detailed, photorealistic", "emotion": "sad" Sample images generated using the Flux.2 [dev] model are shown in Figure 7.

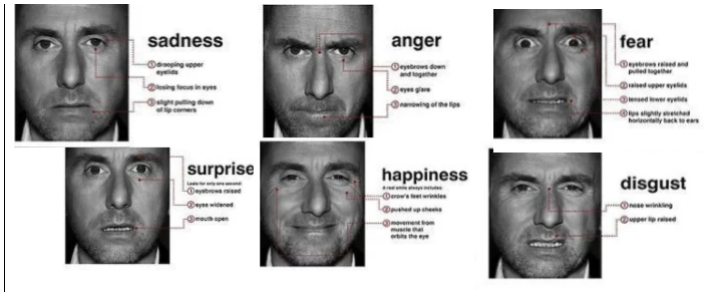
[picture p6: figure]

Figure 6: Definition of facial emotions. Source: Pinterest (https://pl.pinterest.com/pin/836825174527929558/)

Figure 7: Examples of generated emotions with Flux.2 [dev].

### 3.4.1 Generation of a Synthetic Dataset

The process of creating a synthetic dataset was divided into three stages, differing in the configuration parameters of the model (Flux.2 [dev]) and the architecture of the introduced prompts. The main assumption in all three stages was to ensure high diversity and representativeness of the dataset. For this purpose, demographic variables such as gender, age range, and ethnic origin were taken into account.

### 3.4.1.1 Stage I: Generation Based on Scientific Definitions (10,000 images)

In the first phase, the focus was on the rigorous reproduction of scientific definitions of facial expressions for individual emotions.

- Generation parameters: Non-optimal (in terms of quality) parameter values were applied. A low number of iteration steps (15) and a low guidance scale value of 3.

- Results: Due to the adopted parameters, the generation of a single image was highly computationally efficient (average time: approximately 5 seconds). The obtained images (cf. Figure 8) constituted an almost perfect, textbook reflection of the emotion definitions. This resulted in an unrealistic representation of emotions, which in reality is characterized by much greater variance.
- Prompt structure: Prompts were constructed in a strict manner.
Example: "headshot of sad 10 year old European boy, drooping eyelids with loss of eye focus, lips slightly pulled down at corners, grieving expression, overcast outdoor light, highly detailed, photorealistic"

Figure 8: Examples pictures generated in Stage I

### 3.4.1.2 Stage II: Optimization for Realism (20,000 images) In the second

phase, strict adherence to scientific definitions was abandoned. More focus was placed on natural and varied descriptions.

- Generation parameters: The efficient parameters from the first stage were maintained (15 iteration steps, guidance scale of 3; average generation time approx. 5 seconds).
- Results: The introduction of prompt modifications and allowing a face angle deviation of 1520 degrees relative to the camera axis significantly increased the realism of the obtained samples (cf. Figure 9).
- Prompt structure: Prompts described emotions in a more realistic manner, allowing for natural expression.
Example: "medium close-up portrait of a adult (30-45 years old) south asian female, showing neutral emotion with blank gaze, context: listening, harsh overhead light, plain gray background, face clearly visible, realistic facial expression, candid photograph, natural expression"

Figure 9: Examples pictures generated in Stage II

### 3.4.1.3 Stage III: High-Quality Generation (17,600 images) The third phase

was an extension of the assumptions from Stage II, with particular emphasis on maximizing visual quality and the introduction of advanced variability in lighting conditions.

- Generation parameters: The computational load was significantly increased by setting the maximum number of iteration steps to 50 and raising the guidance scale to a level of 6 (on a 10-point scale).
- Results: The effect of changing the parameters was obtaining images of the highest detail, characterized by high realism (cf. Figure 10). However, the increase in precision was associated with a significant drop in efficiency the average generation time increased to approx. 33 seconds per image.
- Prompt structure: Prompts were highly elaborate, incorporating dynamic head positioning and lighting descriptions.
Example: "slight 3/4 angle portrait of a mid 30s indigenous american person, braided hair, with a scar on cheek, displaying fearful frozen deer-in-headlights stare, situation: receiving emergency news, ring light, blurred bokeh city lights background, sun-kissed skin, face fully visible and in sharp focus, authentic human facial expression, high-resolution 8k portrait, ultra-sharp details"

Figure 10: Examples pictures generated in Stage III

### 3.4.2 Flux Models Detailed Training Analysis

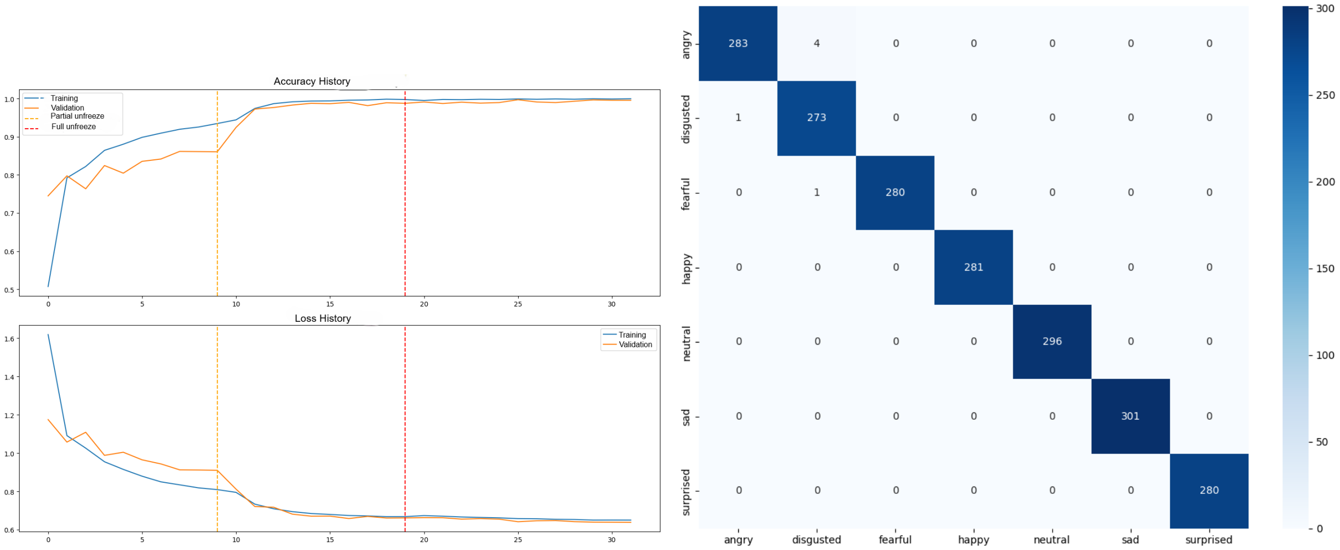
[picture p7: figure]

Figure 11: Metrics for Dataset 1 Evidence of extreme overfitting to specific prompts.

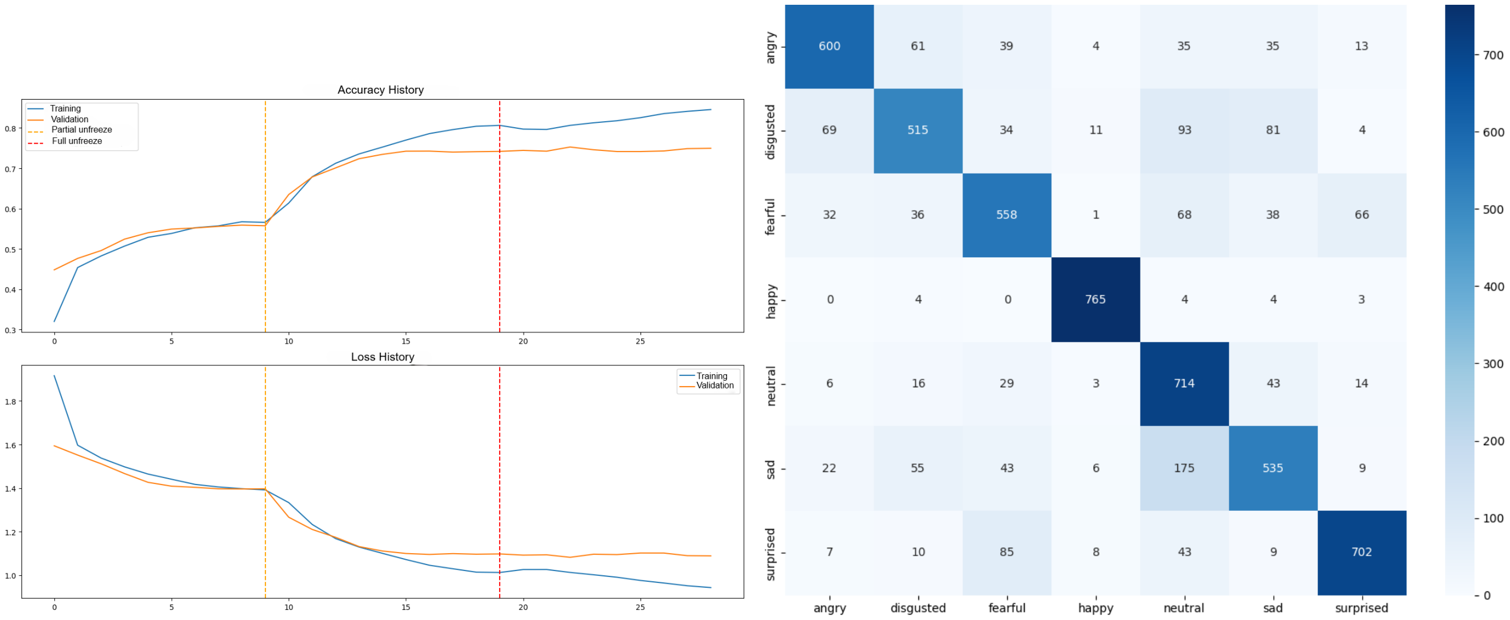
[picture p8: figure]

Figure 12: Metrics for Dataset 2 Balanced training with realistic generalization.

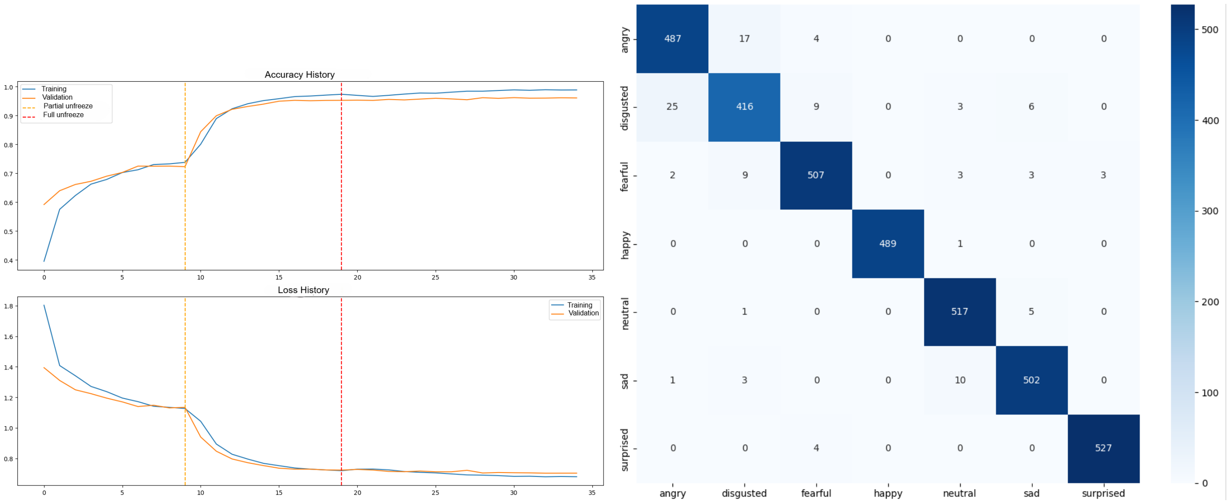
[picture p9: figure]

Figure 13: Metrics for Dataset 3 High validation scores masking poor practical utility.

The evaluation of synthetic data impact was performed using three distinct datasets generated by the FLUX.2 dev model. Each dataset consists of a different number of images generated using unique prompt strategies. Dataset 1 contains 10000 images. Dataset 2 contains 20000 images. Dataset 3 contains 17600 images. The exact prompt formulas and generation details for each set will be described in the following sections. The metrics achieved for each unique dataset are presented in the table below.

Dataset Variant | Accuracy | Precision | Recall | F1 Macro
Flux Dataset 1 | 99.70% | 0.9969 | 0.9969 | 0.9969
Flux Dataset 2 | 76.90% | 0.7764 | 0.7701 | 0.7694
Flux Dataset 3 | 96.93% | 0.9687 | 0.9684 | 0.9685

Table 3: Performance metrics for models trained on three distinct FLUX.1 datasets.

The extreme performance gap between the datasets highlights a critical issue in using synthetic data for emotion recognition. While Dataset 1 and Dataset 3 show nearly perfect accuracy, these results are deceptive and do not translate to practical performance. During live camera testing, models trained on these sets failed to identify expressions on real human faces. This is a clear case of the network overfitting to specific digital artifacts and the consistent idealized nature of the prompts used in those versions. The models effectively memorized the synthetic patterns instead of learning universal human facial features.
In contrast, Dataset 2 was generated using more complex and noisy prompts, including various lighting conditions and subtle expression changes. Although the accuracy is lower at 76.90%, this model proved to be the only one with genuine generalization capabilities. It successfully recognizes emotions in live interactions, confirming that a lower validation score on synthetic data can often indicate a more robust model for practical deployment.

### 3.4.3 Alternative Attempt with Hunyuan Image 3

After successfully generating images with the Flux model we decided to test other available generative architectures. We attempted to use the quantized Hunyuan Image 3 model in the NF4 format. The experiments were conducted on the departmental server which is equipped with two NVIDIA graphics cards each possessing 48 GB of VRAM. Despite having 96 GB of total video memory the generation process encountered critical architectural limitations. The primary issue was the inability of the PyTorch environment to properly distribute the model weights across both GPUs. Using automatic memory balancing resulted in CUDA out of bounds errors during the attention mechanism calculations. Attempting to manually assign the neural network layers to specific cards caused communication failures between the tokenizer and the main model. The system failed to generate even a single image returning only execution errors. Due to these numerous and persistent hardware communication problems we completely abandoned the use of this model.

### 3.5 Final training dataset

After combining the rigorously cleaned baseline dataset (104,197 images) with the processed Exp-W samples (16,944 images), the final unified dataset ready for model training reached a total volume of 121,133 normalized images.

### 3.6 Convolutional neural networks

Convolutional neural networks (CNNs) are the most prominent type of AI algorithm for image processing out there today. Put simply, a CNN takes a visual input (a digital image) and applies a series of filter operations to that input. Through this process, a certain type of information or output is extracted from the input image. This could, for example, be the type of object that is displayed in the input (a.k.a. image classification), but it could also be a partitioning of the input into different regions (a.k.a. image segmentation) or something else entirely. CNNs are very versatile in that respect and can be used to solve all kinds of image processing problems. For those interested in analogies with biology, think of the way that the visual cortex processes information (cf. works of Hubel & Wiesel) CNNs are inspired by and closely related to this architecture.¹

### 3.6.1 Literature Review and Theoretical Foundation

The development of an original neural network architecture was preceded by a thorough review of the relevant literature and scientific publications in the field of human emotion recognition using Convolutional Neural Networks (CNNs). Knowledge regarding

1Mateusz Miosz, Convolutional Neural Networks Demystified: How Immunofluorescence Images Are Processed in Modern Labs. Available at: [Link to the article] (https://www.euroimmun.pl/splotowe-sieci-neuronowe-bez-tajemnic-jak-przetwarza-sie-obrazy-immunofluorscencyjne-w-nowoczesnych-laboratoriach/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)

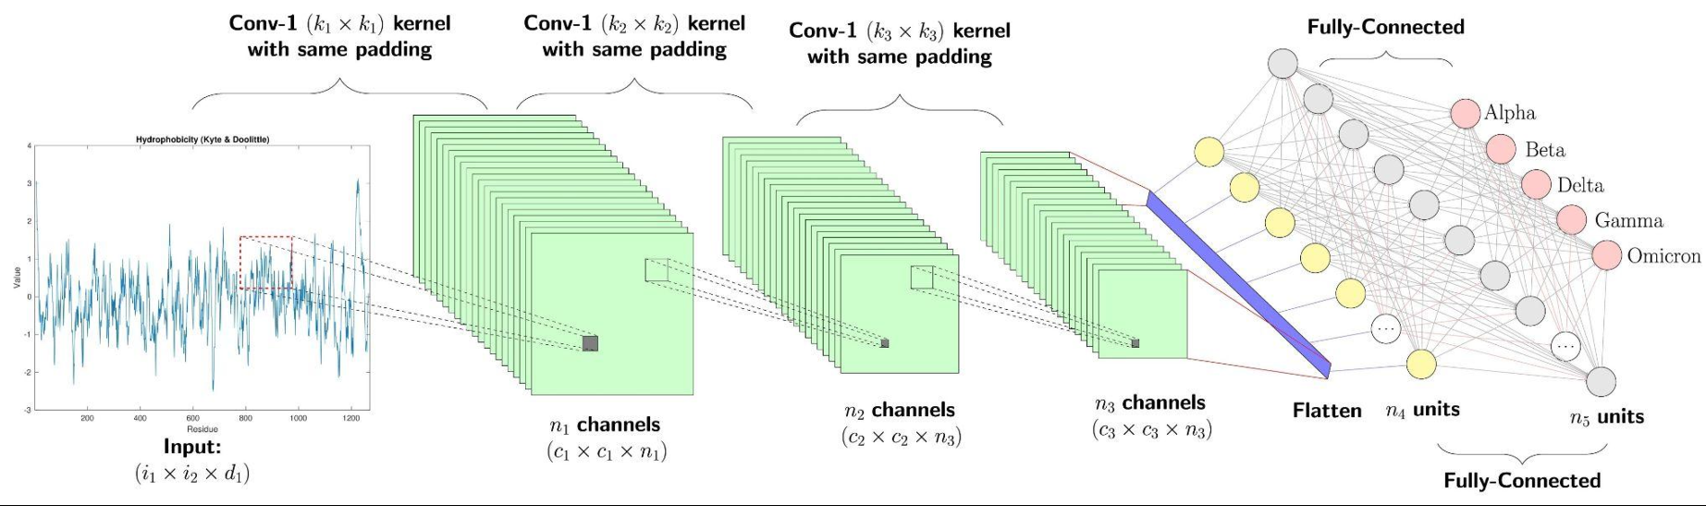
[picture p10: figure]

Figure 14: CNN network example

the operational mechanisms of convolutional networks and the functions of individual model layers was systematized based on the official technical documentation of the TensorFlow [3] library and specialist educational materials (including the GeeksforGeeks portal²
). The following technology stack was employed in the process of designing and implementing the system:
- TensorFlow The selection of this framework was driven by its high performance and streamlined deployment process for trained models on embedded platforms. This aspect was of critical importance due to the intended implementation of the system on a Raspberry Pi microcomputer.
- TensorBoard This tool was implemented for the purpose of monitoring and evaluating model metrics. It enables real-time logging of parameters during the training process and their visualization within a dedicated graphical interface, while offering advanced filtering and data view customization capabilities.
- TensorFlow Keras (tf.keras) This module was used to optimize dataset management. It facilitated the partitioning of the available corpus into training, validation, and test sets, in proportions of 70 percent 20 percent 10 percent respectively. Furthermore, due to significant class imbalance within the dataset (a considerably smaller number of samples for selected emotion categories), the library’s mechanisms were employed to analytically compute and assign weights to individual classes, thereby preventing the model from exhibiting a bias toward dominant classes.
- Scikit-learn (sklearn) This library was utilized primarily for the generation of a confusion matrix. It constitutes a fundamental analytical tool within the project, enabling detailed evaluation of classifier performance and assessment of prediction accuracy across individual emotion categories.

2
shibsankar saw, Emotion Detection Using Convolutional Neural Networks (CNNs). Available at: [Link to the article] (https://www.geeksforgeeks.org/deep-learning/emotion-detection-using-convolutional-neural-networks-cnns/)

### 3.6.2 Problems encountered

### 3.6.2.1 Environmental Challenges and Hardware Resource Optimization

During the implementation phase of the neural network model, several critical issues of an environmental and hardware nature were identified. The main obstacle was the lack of native GPU acceleration support on Windows for the TensorFlow library (version 2.11 and later). This problem was resolved by migrating the runtime environment to the WSL2 subsystem (Windows Subsystem for Linux). A further challenge was the aggressive allocation of all available GPU VRAM by TensorFlow processes, which led to system instability. This issue was mitigated at the algorithm code level by enabling dynamic memory management (memory growth). As a result, only the amount of VRAM strictly necessary for efficient computation at any given moment is allocated to the network training process.

### 3.6.2.2 Overfitting and the Model Checkpointing Mechanism During train-

ing runs on various datasets, it was observed that models tend to overfit very rapidly. The critical point at which the model’s generalization capability began to deteriorate sharply typically occurred between the 8th and 11th epoch. To prevent the loss of the best network weights, a Model Checkpointing mechanism was implemented. The algorithm was configured to permanently save the model state only during those epochs in which the validation loss reaches a value lower than in previous iterations.

### 3.6.2.3 Analysis of the Root Causes of Early Overfitting The rapid degrada-

tion of validation results and the aggressive overfitting observed in the trained models stems from the convergence of several factors, related primarily to the quality and characteristics of the input data:

- Memorization - Rather than extracting universal features, a model with high parameter capacity begins to "memorize" specific images from the training set. This results in high accuracy on training data and a drastic drop in performance on new, previously unseen images.
- Noisy Labels - The datasets used frequently contain low-quality images ("garbage" data) or carry incorrectly assigned labels (e.g., a neutral face labeled as sad). The network’s attempt to fit such anomalies forces it to develop false, overly complex decision rules, which directly accelerates the overfitting process.
- Insufficient Data Diversity - A lack of adequate variance in the training set causes the model to quickly exhaust the pool of available features. In such cases, the application of strong regularization and Data Augmentation techniques becomes essential.

### 3.6.3 First simple model

The designed architecture constitutes a classical deep convolutional neural network (CNN), optimized for the extraction of spatial features from facial images and the classification of emotional states. The model was built in a layered fashion, with a clear division into a feature extraction module and a final element serving as the classifier.

### 3.6.3.1 Code review

def first_model () :
inputs = Input ( Input_shape )

conv1 = layers . Conv2D (32 , (3 , 3) , strides =(1 ,
1) , kernel_regularizer = l2 (0.001) ) ( inputs ) conv1 = layers . Dropout (0.1) ( conv1 )
conv1 = layers . Activation (’relu ’) ( conv1 ) pool1 = layers . MaxPooling2D ((2 , 2) ) ( conv1 )

conv2 = layers . Conv2D (64 , (3 , 3) , strides =(1 ,
1) , kernel_regularizer = l2 (0.001) ) ( pool1 ) conv2 = layers . Dropout (0.1) ( conv2 )
conv2 = layers . Activation (’relu ’) ( conv2 )
pool2 = layers . MaxPooling2D ((2 , 2) ) ( conv2 )

conv3 = layers . Conv2D (128 , (3 , 3) , strides =(1 ,
1) , kernel_regularizer = l2 (0.001) ) ( pool2 ) conv3 = layers . Dropout (0.1) ( conv3 )
conv3 = layers . Activation (’relu ’) ( conv3 )
pool3 = layers . MaxPooling2D ((2 , 2) ) ( conv3 )

conv4 = layers . Conv2D (256 , (3 , 3) , strides =(1 ,
1) , kernel_regularizer = l2 (0.001) ) ( pool3 ) conv4 = layers . Dropout (0.1) ( conv4 )
conv4 = layers . Activation (’relu ’) ( conv4 )
pool4 = layers . MaxPooling2D ((2 , 2) ) ( conv4 )

# Classifier

flatten = layers . Flatten () ( pool4 )
dense = layers . Dense (128 , activation =’relu ’) ( flatten )
drop_1 = layers . Dropout (0.2) ( dense )
outputs = layers . Dense ( num_emotions , activation =’softmax ’) ( drop_1 )

model = Model ( inputs = inputs , outputs = outputs , name =" first_model ")
model . summary ()
return model
- layers.Conv2D(32, (3, 3), strides=(1, 1), kernel_regularizer=l2(0.001)) This is a two-dimensional convolutional layer responsible for extracting features from facial images. It slides 32 different filters of size 3x3 (kernel) across the entire image one pixel at a time (strides=(1,1)), searching for edges, curves, and specific textures. The kernel_regularizer=l2 parameter adds a penalty to the loss function for excessively large weight values, which is a technique used to prevent model overfitting.
- layers.Dropout(0.1)
A regularization layer that randomly "switches off" (zeroes out) a specified fraction of neurons (in this case, 10%) during each training step. This forces the network to develop more generalized patterns and prevents overfitting to specific images in the training set.
- layers.Activation(’relu’)
Defines the ReLU (Rectified Linear Unit) activation function. Its role is to introduce non-linearity into the model by zeroing out all negative values while passing positive values through unchanged. This enables the network to learn complex, non-linear relationships.
- layers.MaxPooling2D((2, 2))
A pooling layer that reduces the spatial resolution of the feature map by half. It selects the highest value from each 2x2 pixel region. This drastically reduces the number of parameters to be computed and makes the model less sensitive to minor shifts of the face within the frame.
- layers.Flatten()
A flattening layer. It takes the three-dimensional feature maps generated by the preceding convolutional layers and reshapes them into a one-dimensional vector. This is a necessary step in order to pass the extracted features to a classical dense network (the classifier).
- layers.Dense(128, activation=’relu’)
A fully connected dense layer (every neuron is connected to every neuron in the preceding layer). It acts as the primary classifier, making decisions based on the flattened feature vector that lead to emotion recognition. It contains 128 neurons and its own ReLU activation function.
- activation=’softmax’
An activation function used in the final (output) layer of the network for multiclass problems. It transforms the network’s raw numerical outputs into a probability distribution as a result, the output values always sum to 1.0 (100%).
- model = Model(inputs=inputs, outputs=outputs, name="first_model") A function from the Keras Functional API that physically creates the model object. It connects the previously defined data entry point (inputs) with the final layer (outputs) into a single graph structure, which can then be compiled, trained (by calling the .fit() method), and used for inference.

### 3.6.3.2 Training metrics The neural network training process was carried out us-

ing a dataset comprising 104,197 grayscale images with a standardized resolution of 96Œ96 pixels. At this stage of experimentation, data augmentation techniques were deliberately omitted in order to establish the model’s baseline generalization capability. As a result, upon completion of the training process, a validation accuracy of approximately 63% was achieved. The computational experiments were conducted in a local environment (a mobile workstation), utilizing the Windows Subsystem for Linux (WSL2) architecture to ensure framework compatibility with hardware acceleration. The hardware platform used for training had the following specification:

- CPU - Intel Core i9 13th Generation (base clock 2.20 GHz)
- RAM - 16 GB DDR5 (5600 MHz, CL46 latency)
- GPU - NVIDIA GeForce RTX 4060 with 8 GB dedicated VRAM

Based on the conducted training, we generated the confusion matrix shown in Figure 15.

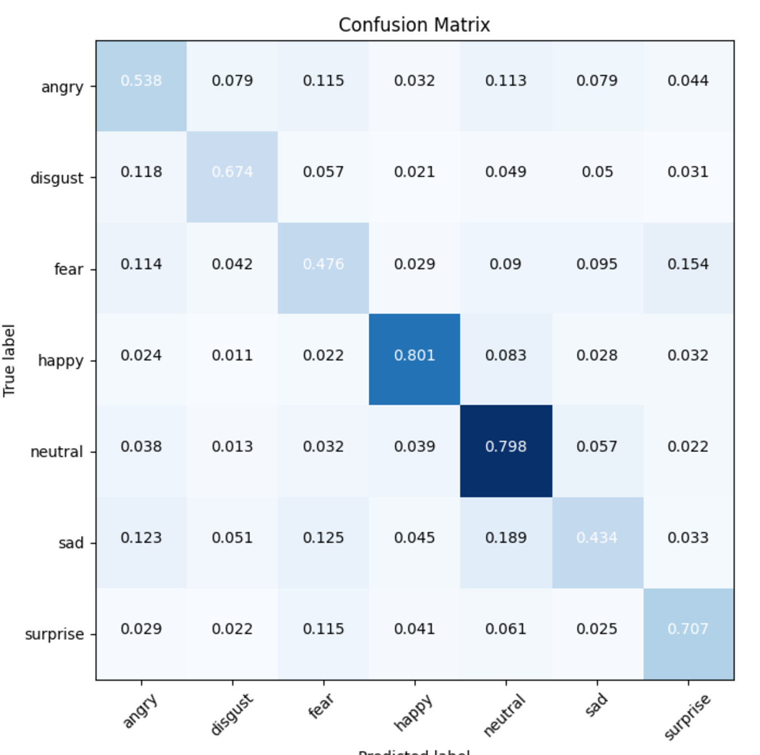
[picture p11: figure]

Figure 15: Confusion matrix

- Accuracy

Accuracy =

T P + T N
T P + T N + F P + F N

=

0.538 + 0.674 + 0.476 + 0.801 + 0.798 + 0.434 + 0.707 7
≈ 0.6326 (63.26%)

- Precision

Precisionhappy =

T P
T P + F P

=

0.801
0.032 + 0.021 + 0.029 + 0.801 + 0.039 + 0.045 + 0.041

=

0.801
1.008

≈ 0.7946 (79.46%)

Analysis of the loss function curves for the training and validation sets (Figure 16) reveals clear symptoms of network overfitting. The rapid degradation of validation results, observable around the 10th epoch, indicates a loss of the model’s generalization capability. Furthermore, as early as the 4th epoch, a significant flattening of the validation loss curve can be observed, while the training loss continues to decrease. This points to a high likelihood of memorization, in which the model, rather than extracting universal facial expression patterns, begins to overfit to the specific characteristics of individual images in the training set. To mitigate this issue and improve the network’s performance, the following optimization steps have been planned for subsequent stages of the work:

- Data Cleaning - A detailed review of the datasets will be conducted with respect to the correctness of annotations. Images of extremely low quality, those not depicting faces, or those carrying incorrect labels (noisy data) will be removed from the training process.
- Data Augmentation - The impact of random geometric and photometric image transformations applied in real time (e.g., rotations, brightness adjustments) on suppressing overfitting and improving the model’s final evaluation metrics will be investigated.

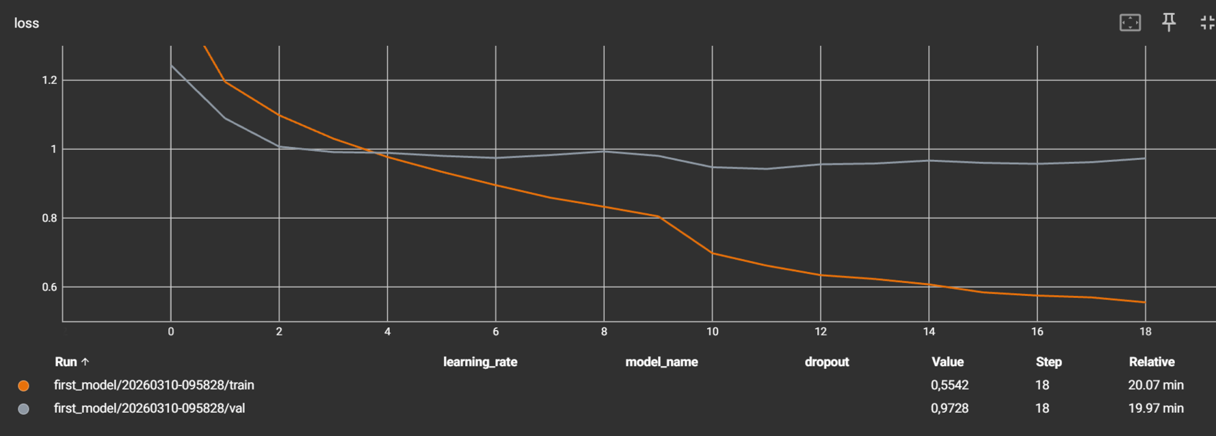
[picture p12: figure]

Figure 16: Graph of validation and training loss

### 3.6.4 Extended base model

Following the baseline observations from the first model, we developed more complex custom architectures: second_model and third_model. These models introduced deeper feature extraction blocks and more aggressive dropout rates to counter the previously observed overfitting.
The second_model emerged as the most successful architecture in our entire study. It achieved an impressive validation accuracy of 71.04%. As shown in its confusion matrix (Figure 17), it performs exceptionally well in recognizing the "happy" emotion (over 2000 correct predictions), though it still faces challenges distinguishing between "sad" and "neutral" states. The third_model also provided solid results (67.81% accuracy), but exhibited slightly more instability during the validation phases.

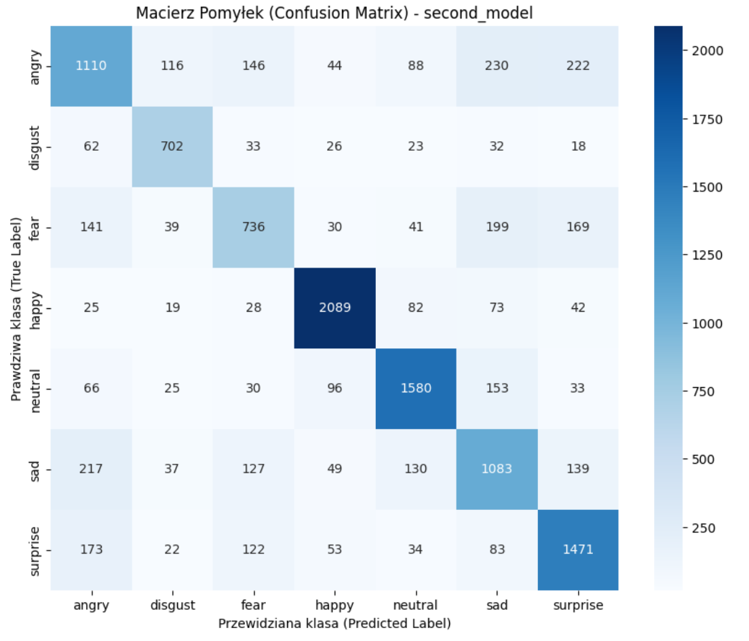
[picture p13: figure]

Figure 17: Confusion Matrix - second_model

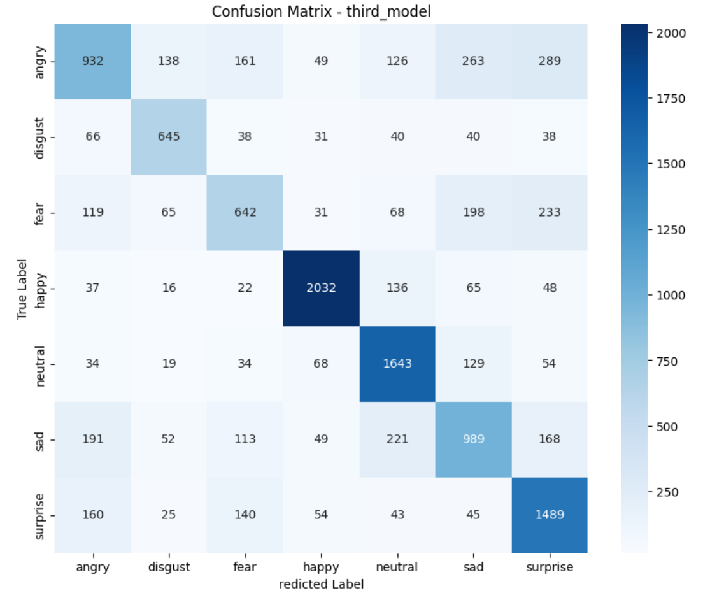
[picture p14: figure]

Figure | 18: | Confusion | Matrix | -
third_model

The training dynamics of the third_model can be observed in Figure 19, where the stabilization of the validation loss curve indicates a significant reduction in the memorization problem that plagued the initial basic model.

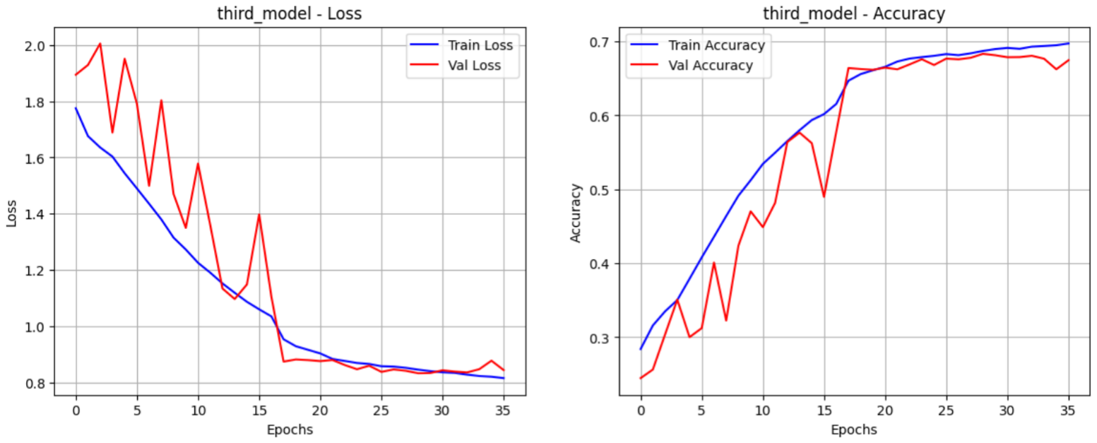
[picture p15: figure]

Figure 19: Graph of validation and training loss/accuracy for third_model

### 3.7 Comparison with reference DCNN models

We decided to compare the results of our best model against ready-made, pre-trained deep convolutional neural network (DCNN) models designed for image classification. For the comparison, we selected the following architectures: InceptionV3[11], Xception[14], ResNet50[12], ResNet101[12], VGG16[13], and VGG19[13].

- The VGG family (VGG16 and VGG19): These networks were designed in 2014 by the Visual Geometry Group at the University of Oxford, in preparation for the prestigious ILSVRC competition. The variants used in the study differ from each other solely in structural depth, consisting of 16 and 19 layers respectively.
- The ResNet family (ResNet50 and ResNet101): Residual networks whose names directly indicate the total number of implemented layers (50 and 101). Their fundamental architectural innovation is the introduction of skip (shortcut) connections. This mechanism effectively prevents the vanishing gradient problem, enables feature transfer from the early stages of the network, and significantly improves the stability and efficiency of the training process.
- The InceptionV3 and Xception architectures: These are advanced models developed by Google engineers, representing a technological evolution of the classic Inception network from 2014. InceptionV3, introduced a year later, is characterized by a very extensive structure comprising 159 layers. Meanwhile, the Xception architecture, presented in 2016, bases its key feature extraction module on 36 layers.

### 3.7.1 Fine-Tuning

For the pre-trained models, we also applied the fine-tuning method. This process involves adapting a ready-made machine learning model to a specific task or new data that differs from the dataset used during the network’s original training. Instead of training the model entirely from scratch, the ’knowledge’ it has already acquired regarding the detection of universal visual features such as edges, gradients, or basic geometric shapes is leveraged. The fine-tuning strategy we implemented was based on the following assumptions:

- Partial unfreezing of deep layers - Rather than updating weights across the entire network, we unlocked only the last 20% of the base model’s layers for training, leaving the initial 80% permanently frozen. This is because the early layers of a convolutional network are responsible for extracting universal image features, which we do not want to modify. The final layers, on the other hand, learn high-level features specific to a given problem which is precisely why we fine-tuned them to recognize the nuances of facial expressions.
- Learning rate reduction - Prior to commencing the actual fine-tuning, the model was recompiled with a learning rate ten times smaller than the default. Using the initial default value of this hyperparameter could result in overly aggressive weight updates and irreversibly destroy useful representations learned on the ImageNet dataset. A reduced learning rate allows for safe and subtle weight adjustments.
- Preserving training continuity - By setting the initial_epoch=history.epoch[-1] parameter, we ensured that the model resumes training from exactly the epoch at which the initial (warm-up) phase ended. This guarantees logical and numerical continuity throughout the entire learning process.

### 3.7.2 Problems with datasets

A significant issue during evaluation turned out to be the format of the input data. The DCNN models listed in section 3.7 are by design adapted to process three-channel color images (RGB) at a resolution of 224x224 pixels. Our existing training dataset, however, consisted of grayscale images at a resolution of 96x96 pixels. This difference significantly affected the initial results. After launching the preliminary training on the InceptionV3 model, accuracy stalled at around 40% after just a few epochs, as illustrated in the chart below. This chart presents both the pre-training phase and the metrics obtained during the fine-tuning stage. As can be observed, fine-tuning ultimately made it possible to surpass the 60% accuracy threshold. However, bearing in mind the architectural requirements of the pre-built networks, we made the decision to convert the entire dataset from grayscale to the RGB color space, combined with an artificial colorization process (details are described in section 3.7.3).

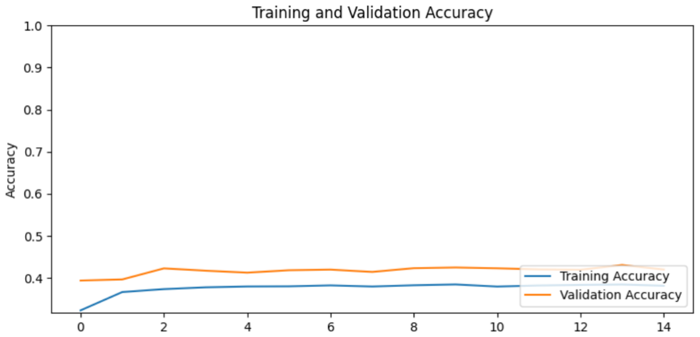
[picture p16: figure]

Figure 20: Graph of validation and training loss

### 3.7.3 Data colorization

Due to the lack of color counterparts for the grayscale images in our original dataset, we implemented a colorization algorithm based on deep learning. We used a solution published on the GeeksforGeeks [16] portal ("Black and white image colorization with OpenCV and Deep Learning"), which is directly based on the groundbreaking 2016 research by Richard Zhang, Phillip Isola, and Alexei A. Efros from the University of California, Berkeley [15]. The foundation of this approach is a change in the way colors are represented instead of the standard RGB model, the algorithm operates in the CIE Lab color space.

- Conversion to Lab Color Space - In the first stage, the image is converted from RGB to Lab color space. The essential difference is that the Lab model completely separates brightness information from color information, whereas in the RGB model these are closely intertwined. The individual channels of the Lab color space are defined as follows:

– L: Image brightness, taking values in the range [0, 100]. In practice, this channel corresponds to a perfect grayscale photograph.

– a: Color axis ranging from green to red.

– b: Color axis ranging from blue to yellow.

Thanks to this separation of information, the task of the neural network is greatly simplified it only needs to estimate the values for the a and b channels, based on the input L channel.

- Structure and Operation of the Convolutional Neural Network (DCNN) - The model used is a deep convolutional network implemented in the Caffe architecture. The inference process proceeds through the following steps:

– The network takes the extracted L channel as input, which is first rescaled to a resolution of 224 × 224 pixels.

– The image is then processed through a series of convolutional layers. Unlike classical classification networks, this architecture contains no fully connected (Dense) or flattening (Flatten) layers, which allows the spatial structure of the processed image to be preserved.

– Rather than treating the prediction of the a and b values as a classical regression problem (predicting continuous numerical values), the algorithm’s authors reframed this as a classification problem. The network computes the probability of each pixel belonging to one of 313 predefined color variants, which are stored in the configuration file pts_in_hull.npy.

- Fusion and Image Reconstruction - The final stage of the process is post-processing, encompassing data fusion and reconstruction of the final image. After the network generates predictions for the a and b channels, these are rescaled back to the original resolution of the input image. A fusion is then performed the original, full-resolution L channel (derived from the source grayscale image) is combined with the AI-generated chrominance channels. By preserving the original L channel, the resulting photograph retains perfect sharpness and all the details of the original. The final step is the mathematical conversion of the reconstructed image from the CIE Lab color space back to the standard RGB color space.

Figure 21 illustrates the results of the colorization algorithm. The achieved effects are satisfactory and will enable comprehensive testing of the pre-trained models discussed in section 3.7.

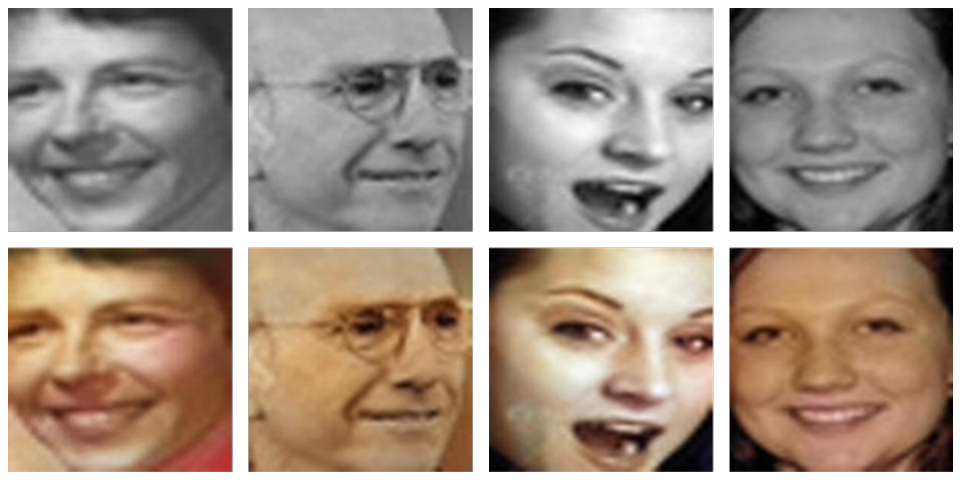
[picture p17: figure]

Figure 21: Photos before and after colorization

### 3.7.4 Comparative Analysis and Final Benchmarking

After standardizing the dataset and successfully colorizing the input images, we conducted a comprehensive evaluation of both our custom models and the pre-trained DCNN architectures. The implementation of Fine-Tuning on the pre-trained networks yielded highly visible improvements.
As illustrated in Figure 22 and 23, the vertical green line marks the 14th epoch, where the deeper layers of the pre-trained models were unfreezed. Immediately following this point, we observed a sharp decline in validation loss and a significant surge in accuracy. This visually confirms that the transferred representations from ImageNet successfully adapted to the facial expression domain.

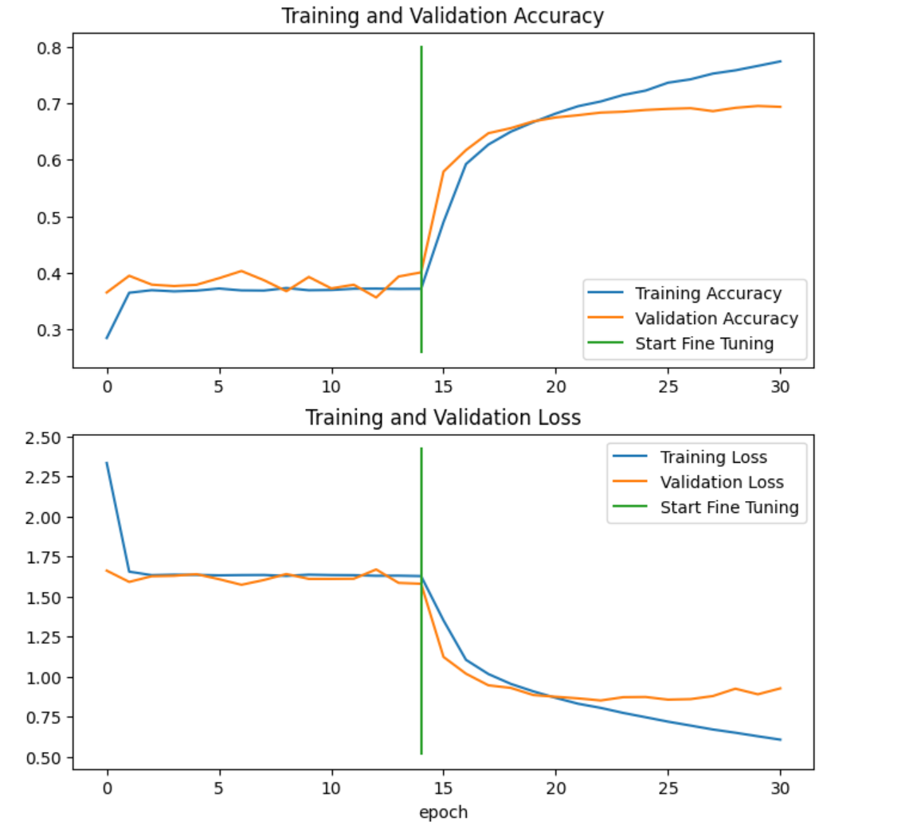
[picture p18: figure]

Figure 22: | Fine-Tuning progress for
VGG19 | Figure 23: | Fine-Tuning progress for
| ResNet50

### 3.7.5 ConvNeXt Tiny Architecture Evaluation

To further push the boundaries of our facial expression recognition system, we evaluated the ConvNeXt Tiny architecture. Unlike the fine-tuning strategy employed for the VGG and ResNet models, where only the top 20% of layers were unfrozen, the ConvNeXt Tiny training utilized a more aggressive, two-phase approach.
The model was built with a frozen ImageNet-pretrained base, followed by a custom classification head consisting of a Global Average Pooling 2D layer, Batch Normalization, Dropout (set to 0.4 for strong regularization), and two Dense layers (256 neurons with ReLU and 7 neurons with Softmax).
- Phase 1 (Warm-up): The custom head was trained exclusively for 5 epochs with a standard learning rate (1 × 10⁻³
) to initialize the classification weights.
- Phase 2 (Fine-Tuning): The entire ConvNeXt base model was unfrozen. A substantially reduced learning rate of 1 × 10⁻⁵ was applied to carefully adjust the deep convolutional weights without destroying the valuable representations learned on the ImageNet dataset.

During our experimental runs, we encountered significant environmental instability. The first trial was scheduled for 20 epochs. After approximately 12 hours of training, the kernel crashed at epoch 15 due to memory exhaustion. Despite the abrupt termination, the model recorded an impressive peak validation accuracy of 74.56% and an estimated macro-precision of approximately 73.55%.

To ensure stability and secure a fully completed training cycle, a second run was executed with a reduced target of 10 epochs. This run successfully finished, achieving a validation accuracy of 73.60% and a macro-precision of 72.64%.
Both ConvNeXt Tiny trials successfully surpassed our previous top-performing custom second_model, which had previously achieved the highest classification accuracy at 71.04%.
The comparative analysis of all tested architectures, now including the ConvNeXt Tiny iterations, is compiled in Table 4.
Model | Accuracy | Macro-Precision
ConvNeXt Tiny (15 epochs - crashed) ConvNeXt Tiny (10 epochs - completed) second_model VGG19 VGG16 ResNet50 third_model ResNet101 InceptionV3 first_model | 74.56% 73.60% 71.04% 70.07% 68.24% 68.00% 67.81% 67.71% 62.15% 56.17% | ∼73.55% 72.64% 70.19% 69.47% 66.57% 67.40% 66.42% 66.87% 60.84% 54.03%

Table 4: Final comparison of model performance metrics

he confusion matrix for the completed ConvNeXt Tiny training session (10 epochs) is presented in Figure 24.

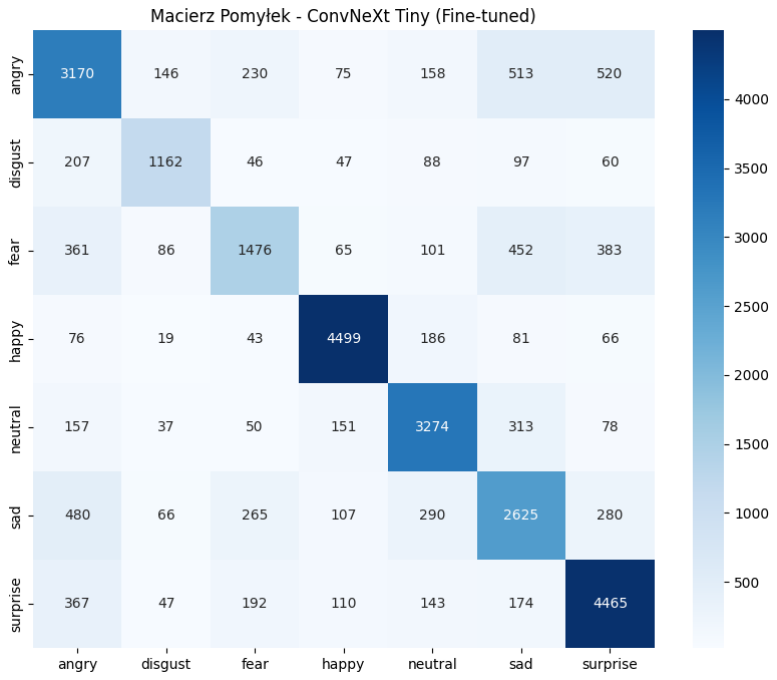
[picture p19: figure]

Figure 24: Confusion Matrix - ConvNeXt Tiny (Fine-tuned, 10 epochs)

The matrix reveals that the model significantly improved recognition across difficult categories, particularly in distinguishing between "sad" and "neutral" states, which was a known bottleneck in previous architectures like the second_model. This success is attributed to the combination of the modern ConvNeXt architecture and the two-stage fine-tuning process, where the entire base was eventually unfrozen to adapt to facial features.
The high macro-precision of 72.64% confirms that the model is not just biased toward the most frequent classes but maintains a high level of reliability across all seven emotional states. This makes it the most suitable candidate for deployment on the target hardware platform (Raspberry Pi), despite its higher computational requirements compared to the initial basic models.

### 3.8 Real-Time Face Detection and Recognition System

To ensure the robotic head can interact dynamically with its environment, a real-time vision processing subsystem was implemented. During the development phase, two distinct architectural approaches were tested to evaluate performance, accuracy, and resource utilization: a CPU-based system utilizing HOG (Histogram of Oriented Gradients) and a GPU-accelerated system leveraging the InsightFace framework.

### 3.8.1 CPU-Based Approach (HOG)

The initial prototype was designed to run entirely on the CPU using the face_recognition library, which relies on dlib’s state-of-the-art C++ toolkit.

- Detection Algorithm: Histogram of Oriented Gradients (HOG) combined with a linear classifier.
- Implementation Details: To maintain a functional framerate, the input video stream was downscaled by a factor of 4 (scale factor = 0.25).
- Pros & Cons: While highly accessible and requiring no specialized hardware or CUDA configuration, the CPU-bound approach struggles with high-resolution frames and multiple faces, leading to significant thermal throttling and lower FPS.

### 3.8.2 GPU-Accelerated Approach (InsightFace)

To overcome the computational bottlenecks, the system was migrated to a GPU-accelerated architecture using the InsightFace library with the ONNX Runtime (CUDA Execution Provider).

- Detection Algorithm: Deep neural networks optimized for spatial detection and feature extraction.
- Implementation Details: This script processes a designated "active zone" in the center of the frame to minimize unnecessary computation. It integrates directly with the trained Keras emotion classification model, analyzing frames at regular intervals (EMOTION_SKIP_FRAMES = 3) to balance accuracy and performance. Face data and emotional states are serialized to a JSON file for the conversation subsystem.
- Pros & Cons: This approach offloads heavy matrix multiplications to the GPU, allowing for processing of higher resolution frames (up to 720p) with minimal CPU overhead.

### 3.8.3 Hardware Performance Comparison

Benchmarking was conducted to quantify the performance delta between the two implementations across various hardware configurations. The tests compare legacy CPU-bound methods (HOG) with modern GPU acceleration (InsightFace).

- Setup A (Main Workstation):

– CPU: Intel Core i5-10400F (2.90 GHz)

– GPU: NVIDIA GeForce GTX 1060 (6GB GDDR5)

- Setup B (Mobile Workstation):

– CPU: 12th Gen Intel Core i5-12450H (2.00 GHz)

– GPU: NVIDIA GeForce RTX 3050Ti (4GB GDDR6)

- Setup C (High-End Mobile Workstation):

– CPU: Intel Core i9-13900HX (2.20 GHz)

– GPU: NVIDIA GeForce RTX 4060 (8GB GDDR6)

- Setup D (Target Platform - Raspberry Pi 5):

– CPU: Broadcom BCM2712 (ARM v8) @ 2.4GHz

– RAM: 8GB LPDDR4X

### 3.8.3.1 CPU-Based Performance (HOG) The following table summarizes the

performance of the HOG-based detection algorithm. FPS values increase significantly when no face is present due to the bypass of embedding and emotion classification models.

Hardware Setup | Face Detected | No Face Detected
Setup A (GTX 1060 / i5-10400F) Setup B (RTX 3050Ti / i5-12450H) Setup C (RTX 4060 / i9-13900HX) Setup D (Raspberry Pi 5) | 2-3 FPS 3-4 FPS 4 FPS N/A | 40-50 FPS 50-60 FPS 90 FPS N/A

Table 5: Performance results for CPU-based HOG detection.

### 3.8.3.2 GPU-Accelerated Performance (InsightFace) The GPU-based approach

offloads heavy matrix multiplications, enabling higher efficiency.

Hardware Setup | Face Detected | No Face Detected
Setup A (GTX 1060 / i5-10400F) Setup B (RTX 3050Ti / i5-12450H) Setup C (RTX 4060 / i9-13900HX) Setup D (Raspberry Pi 5) | 22-26 FPS 20-25 FPS 30-35 FPS N/A | 35-45 FPS 35-45 FPS 65-70 FPS N/A

Table 6: Performance results for GPU-accelerated InsightFace detection.

### 3.8.3.3 Raspberry Pi 5 Performance Profiling (Target Platform) To thor-

oughly evaluate the system’s behavior on the target hardware (Setup D), a series of stress tests were conducted using the btop resource monitor. The profiling focused on CPU utilization, memory footprint, and thermal performance during two distinct states: idling (no face in the frame) and active processing (face detected, invoking face recognition and emotion classification models).

### 3.8.3.4 HOG-Based Implementation The CPU-bound approach utilizing His-

togram of Oriented Gradients (HOG) demonstrated highly variable resource consumption depending on the system state.

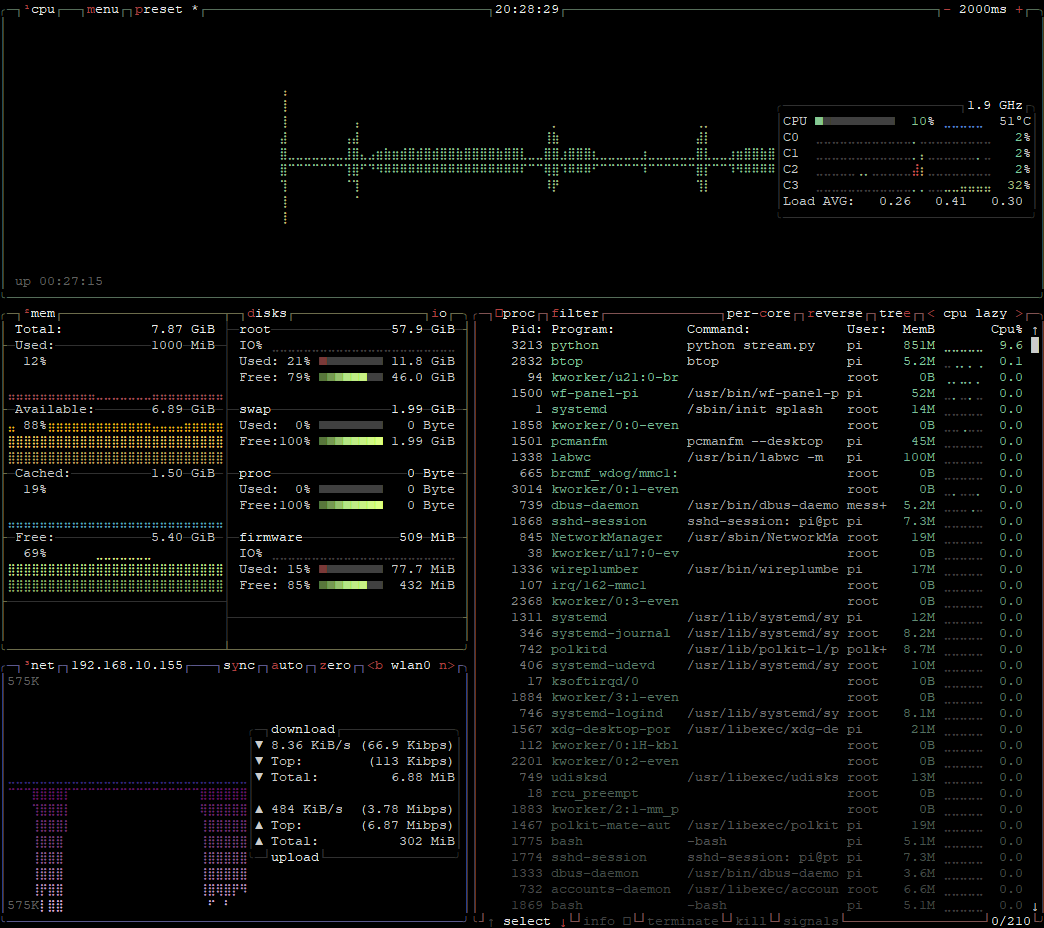
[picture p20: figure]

Figure 25: HOG - Idle state (No face) Figure 26: HOG - Active state (Face de- tected)

As observed in Figures 25 and 26, when no face is present, the system remains exceptionally cool (51◦C) with minimal CPU utilization (approximately 10%). However, upon face detection, total CPU load increases to roughly 40%, and the temperature stabilizes at 65◦C. This moderate total load suggests that the dlib backend is constrained by single-thread performance bottlenecks and cannot fully saturate all four cores of the Raspberry Pi 5. Memory usage remains stable at approximately 1.1 GB.

3.8.3.5 YuNet-Based Implementation The OpenCV-accelerated YuNet model, while offering superior detection accuracy and framerate scalability, exhibits a significantly more aggressive hardware footprint on the ARM architecture.

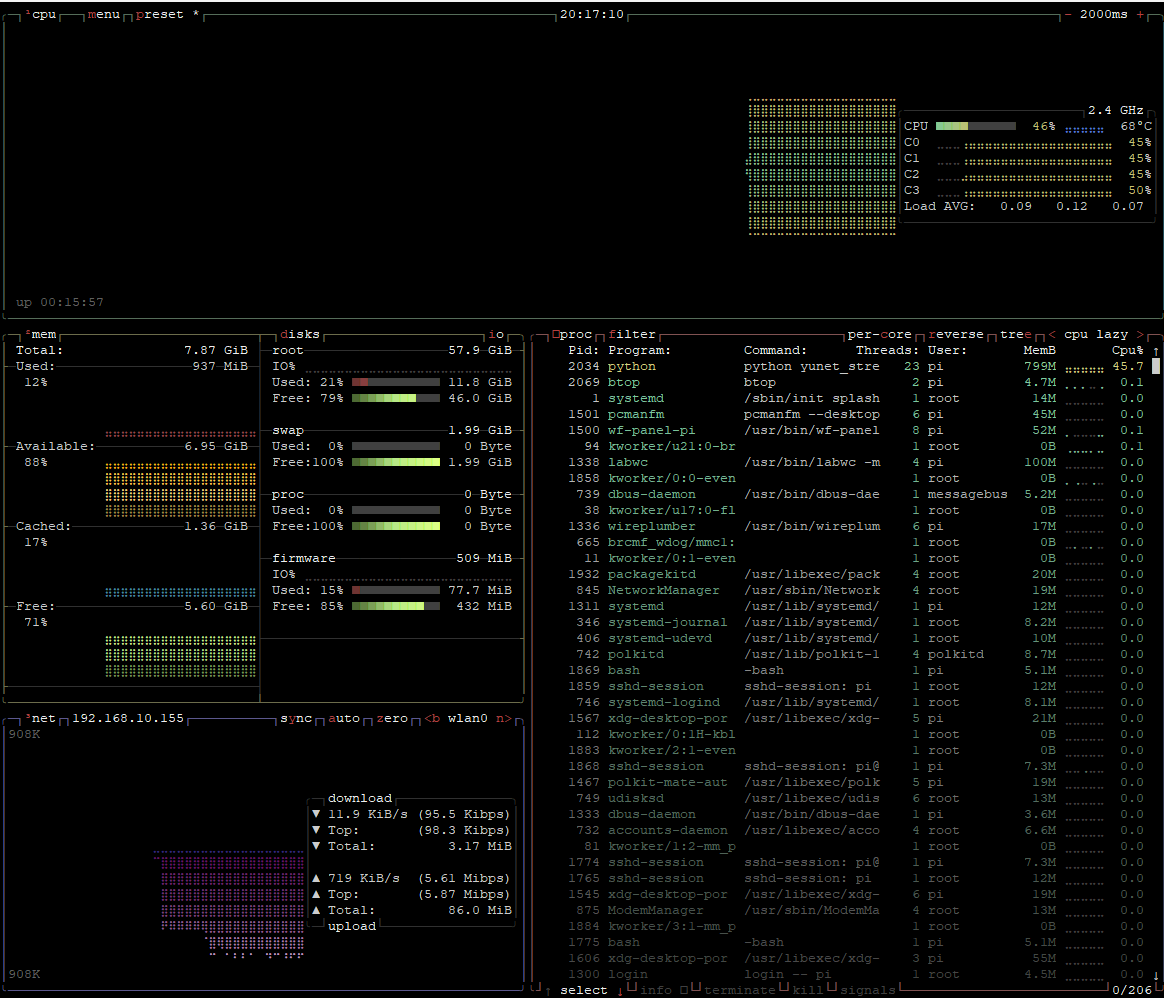
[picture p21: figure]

Figure 27: YuNet - Idle state (No face) Figure 28: YuNet - Active state (Face de- tected)

Figures 27 and 28 illustrate a high baseline operational cost. Even without a face in the frame, continuous neural network inference consumes roughly 46% of total CPU capacity, elevating the temperature to 68◦C. During active face tracking and emotion recognition, the highly parallelized nature of the OpenCV DNN module heavily tasks the processor, driving total CPU utilization to nearly 79%.
Consequently, the SoC temperature reaches 85◦C. This is a critical threshold for the Broadcom BCM2712 chip, at which aggressive thermal throttling occurs, severely degrading performance. These results unequivocally demonstrate that deploying the robust YuNet pipeline on the Raspberry Pi 5 strictly mandates a dedicated active cooling solution (e.g., the official Raspberry Pi Active Cooler) to maintain system stability and real-time processing capabilities over prolonged interaction periods.

### 3.8.3.6 Performance with Active Cooler (Radiator) To verify the hypothesis

regarding the necessity of active cooling, the stress tests were repeated with an official Raspberry Pi Active Cooler attached to the SoC. The results confirmed that the cooling solution effectively eliminates the thermal throttling problem for both implementations.

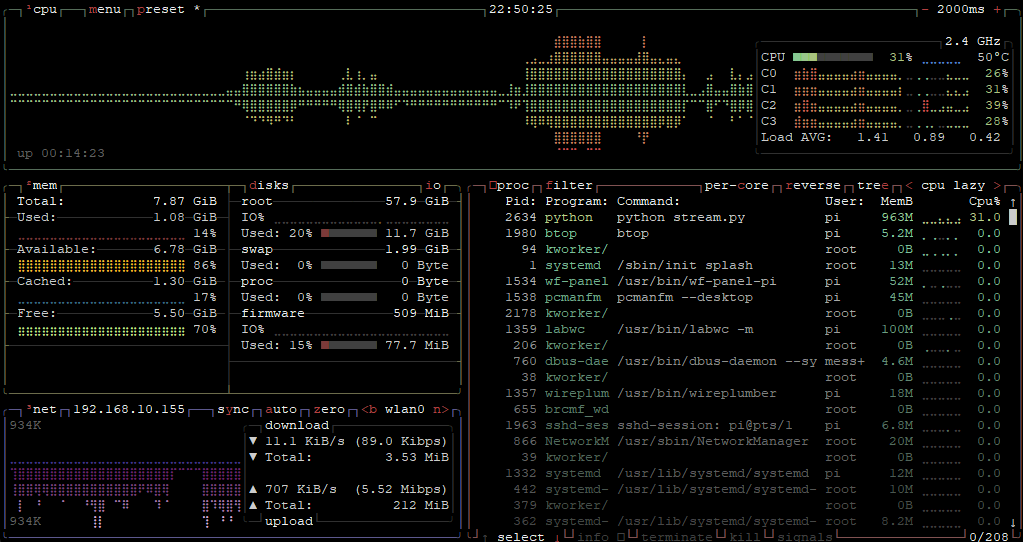
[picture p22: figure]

Figure 29: HOG - Active state (Face detected) with Active Cooler

### 3.8.3.7 HOG-Based Implementation with Active Cooler As shown in Fig-

ure 29, with the active cooler attached, the HOG-based pipeline running in full facedetection mode (process python stream.py visible at the top of the process list) operates with a total CPU load of approximately 31% and a SoC temperature of only 50◦C. This represents a substantial thermal improvement compared to the uncooled scenario (65◦C under the same workload), confirming that the cooler effectively dissipates the heat generated by the dlib-based pipeline. Memory consumption remains stable at approximately 1.08 GB.

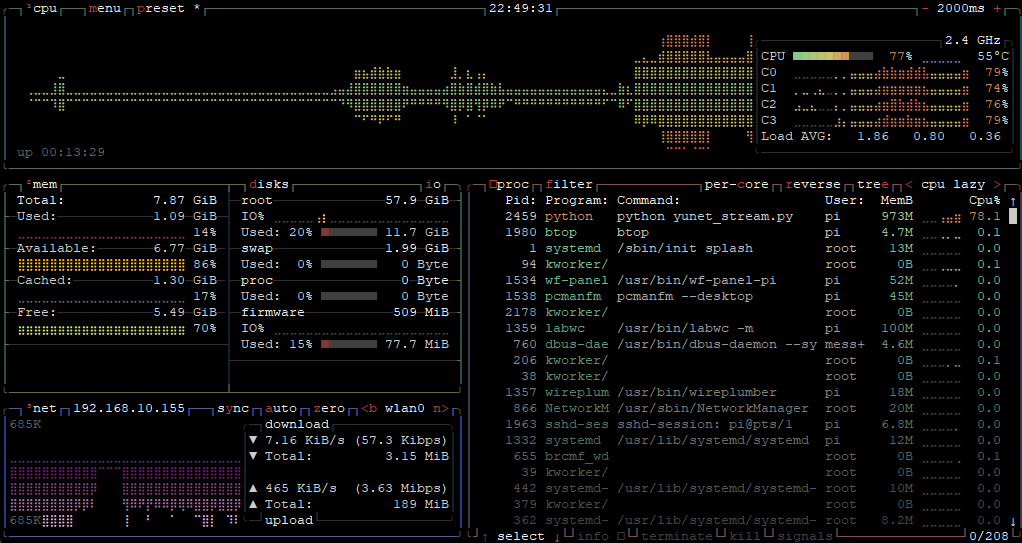
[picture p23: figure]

Figure 30: YuNet - Active state (Face detected) with Active Cooler

### 3.8.3.8 YuNet-Based Implementation with Active Cooler Figure 30 illus-

trates the thermal impact of the active cooler on the more demanding YuNet pipeline. With python yunet_stream.py consuming approximately 78% of a single core and the overall CPU utilization reaching 77%, the SoC temperature is held at 55◦C a dramatic reduction from the critical 85◦C recorded without cooling. This result demonstrates that the active cooler is fully capable of sustaining the YuNet workload within safe thermal boundaries indefinitely, without triggering throttling. Memory usage remains stable at approximately 1.09 GB.

### 3.8.3.9 Summary The introduction of the active cooler reduces peak SoC tem-

peratures by 15◦C for the HOG pipeline and by 30◦C for the YuNet pipeline. These findings confirm that the Raspberry Pi Active Cooler is a mandatory hardware component for any deployment of the vision module in a sustained, real-time interaction scenario particularly when using the OpenCV DNN-accelerated YuNet backend.

### 3.8.4 Finalized Vision Pipeline: YuNet and SFace Integration

To achieve the optimal balance between high framerates on the Raspberry Pi 5 and reliable recognition, the final production pipeline was built around OpenCV’s YuNet for face detection and SFace for facial recognition. This approach bypasses the heavy overhead of previous methods while maintaining robust accuracy.
Detection and Recognition Flow
The system continuously captures frames using Picamera2. YuNet efficiently isolates the largest face in the frame, which is then cropped and aligned. The SFace model extracts a 128-dimensional feature vector (embedding) from this crop. Recognition is performed by calculating the cosine similarity against known vectors stored in the local database, with a strict matching threshold set to 0.28.
Pipeline Stabilization and Logic
To ensure smooth operation and steady tracking, the pipeline integrates a rolling buffer (majority voting) for identity confirmation and triggers the heavy emotion classification model strictly on an event-driven basis (only when a new identity is confirmed or a session starts).

### 3.9 Inter-Module Communication

The vision system operates as an independent network component communicating with the natural language processing module using a client-server architecture based on the Flask framework. The Raspberry Pi runs a local web server that serves a dual role. On one hand, it continuously broadcasts a video stream and sends telemetry packets containing frame coordinates, user ID, and the recognized emotional state directly to the external master module. Data transmission is handled via network requests, ensuring full compatibility across different programming environments.
On the other hand, the server listens for incoming requests. When the master system recognizes a new name during voice interaction or issues a command to change facial expressions, it sends a corresponding return packet. The server on the microcomputer receives this information via endpoints for new users and for lip control, immediately passing it to the internal program layers responsible for database updates and robot behavior modification.

### 3.10 Technical Challenges and Optimization

Building a real-time vision system on embedded hardware introduced several constraints that required specific architectural solutions.
The Raspberry Pi 5 provides significant computational power, but high-intensity neural network inference leads to rapid heat accumulation. During initial tests, the SoC temperature reached a critical threshold of 85 degrees Celsius, causing thermal throttling. The implementation of an active cooling solution was necessary to maintain a stable clock speed and prevent system degradation during prolonged operation. Initially, running the complex emotion classification model on every single frame proved to be a major bottleneck, resulting in poor performance of only 4-5 FPS. To address this, we transitioned to an event-driven architecture where the emotion network is triggered only upon a confirmed identity change or at the start of a new session. This optimization allowed the system to maintain a much smoother and more responsive performance of 14-15 FPS. To further improve reliability, we implemented a majority voting filter using a rolling buffer of seven frames to eliminate identity flickering caused by lighting shifts.
A major challenge was the gap between synthetic training data and real-world performance. While Flux.1 generated visually perfect images, models trained exclusively on these samples failed to generalize to actual camera feeds. We resolved this by modifying the generation prompts to include realistic noise and varied lighting, which provided the necessary variance for practical deployment.

### 3.11 Data Privacy and Security

The vision module was designed with strict privacy protection principles in mind. The system architecture completely excludes storing raw image files or video recordings on the device’s drive. Every detected face is immediately transformed into a digital feature vector, which is a 128-dimensional set of numbers describing facial geometry, from which it is impossible to reconstruct the original human image. This data is stored in a local SQLite database.
To optimize disk space and maintain data security, an automated profile lifecycle was introduced. Upon each startup, the system checks timestamps and irrevocably deletes entries older than seven days. Additionally, the database has a strict capacity limit set to 200 profiles. If this value is exceeded, the defense mechanism automatically purges the oldest records, making room for new users and preventing memory overflow.

### 3.12 Hardware Control and Concurrency

The program running on the microcomputer integrates image analysis with direct control over the mechanical movements of the head. A key element of the software is a dictionary containing predefined movement sequences associated with specific emotional states. Each emotion recognized by the neural network is automatically translated into an appropriate set of positions for the individual servo motors responsible for the artificial face’s expressions. Additionally, the system implements smooth eye tracking, where the coordinates of the detected face center are mathematically scaled to corresponding angular values, allowing the robot to maintain eye contact with the human.
To ensure full operational fluidity and avoid freezing the camera image during movements, the software utilizes a multithreaded architecture using the threading library. Frame processing, eye movement control, mouth animation during speech, and listening for terminal commands run in separate, independent background threads. Communication between the visual analysis layer and the movement algorithm takes place via a safe event queue, meaning that detecting a new emotion or a change in speech status immediately and without delay triggers the corresponding mechanical response.

### 3.13 Conception and tests new model

This part of the project focused on designing and evaluating a new approach for a Facial Emotion Recognition (FER) system. Rather than relying on a standard single network analyzing the entire frame, the new approach assumes the deployment of a multi-stage processing pipeline based on cascaded CNN networks.

### 3.13.1 Solution Architecture

The solution architecture consists of two main modules:

- Feature Extraction Module: The first stage is a CNN model serving as a precise Region of Interest (ROI) detector. Its task is to extract the key facial components of the user, specifically: eyebrows, eyes, and mouth.
- Final Classification Module: The segmented components are then passed to the target neural network. Its task is to analyze the spatial relationships and shape of only those isolated facial features in order to make a final prediction across one of 7 classes (6 basic emotions + neutral state).

### 3.13.2 Benefits of This Approach

- Increased accuracy: Initial research indicates that the cascaded approach enables higher detection precision. The main classifier focuses exclusively on "clean" facial expression signals, rather than wasting computational resources on analyzing irrelevant details in the image.

- Greater robustness to noise: The system becomes significantly less susceptible to variable environmental conditions (such as lighting, background, or the user’s hairstyle), since the decision-making process relies strictly on isolated facial components.

### 3.13.3 Training Data Strategy (Dataset)

To provide the model with optimal conditions for generalization and to avoid overfitting, a comprehensive dataset has been designed:

- Volume: The dataset will consist of 49,000 images in total, ensuring perfect class balance (exactly 7,000 samples per each of the 7 emotions analyzed).
- Demographic diversity: The dataset has been planned with careful attention to the absence of bias, and will therefore be diverse in terms of ethnicity and age.
- Synthetic augmentation (Generative Augmentation): Due to the difficulty in acquiring such a large number of balanced, real-world, high-quality images, at least half of the dataset will be generated synthetically using the advanced diffusion model flux2.dev. This will allow for controlled creation of edge cases and precise management of the demographics of the generated faces.

### 3.14 Conclusion

The development of the vision module for the robotic head successfully met its primary objectives. Through rigorous data preprocessing, including pHash deduplication, OCR artifact removal, demographic filtering, and data augmentation via Generative AI (Flux.1), we constructed a highly robust training corpus of over 120,000 images.
The comparative study between custom-designed Convolutional Neural Networks and industry-standard transfer learning models (VGG, ResNet, Inception, ConvNeXt) yielded highly satisfactory results. While our custom second_model achieved a highly commendable accuracy of 71.04%, closely approaching our initial 75% target, the integration of the ConvNeXt Tiny architecture pushed our results even further, peaking at 74.56%.
The application of Fine-Tuning and innovative data colorization techniques proved highly effective. While heavy architectures like ResNet101 and InceptionV3 did not justify their computational overhead in this specific use case, modern architectures like ConvNeXt Tiny demonstrate immense potential. The best-performing models will serve as a reliable engine to feed affective data to the robot’s speech synthesis subsystem, paving the way for empathetic, human-robot interaction.

## 4 Speech System

### 4.1 Project Overview and Purpose

The main goal of the speech module, developed as part of the "humanoid-head" project, is to enable the robot to conduct natural and meaningful conversations with humans. Our team’s task is to ensure that the machine not only reacts to rigid commands but can also respond fluently and logically to questions, mimicking a real conversation. The assistant was designed with the students of the Gdask University of Technology in mind. Its practical applications within this interaction include:

- Providing precise navigation directions, making it easier to reach specific rooms in university buildings (such as EA or NE).
- Providing up-to-date information about weather conditions.
- Engaging in casual conversations on general topics, using artificial intelligence to generate natural-sounding responses.

### 4.2 System Architecture

The system is designed as a continuous loop that runs until it is stopped manually. It uses a pipeline structure with three main steps:

- Speech-to-Text (STT): The system uses a microphone to listen to the user. It records the sound and uses the Whisper AI model (the "small" version) to change the user’s voice into text.
- Intent Detection and Processing (LLM): After getting the text, the system checks what the user wants using the IntentDetector.

– If the user asks about the weather ("POGODA") or university classes ("PG"), the system uses specific logic to find this data.
– For all other questions, it sends the text to a Large Language Model. The project uses the Ollama framework with the "gemma3:4b" model, connected through the LangChain library. The model gets a special prompt with a database of rooms and weather data to know how to answer correctly.
- Text-to-Speech (TTS): When the text answer is ready, the system uses the pyttsx3 library to read it out loud.

### 4.3 Environment and Dependencies

### 4.3.1 Required Libraries

The project relies on a variety of Python libraries for audio processing, web scraping, system integration, and data manipulation. The key dependencies are described below:

- BeautifulSoup4 (beautifulsoup4): Used for parsing HTML documents. It is utilized to scrape information and extract staff details from the university’s websites.
- LangChain (langchain-core, langchain-ollama): Manages the integration with local Large Language Models via Ollama and formats chat prompt templates.
- PyAudio (pyaudio): Provides Python bindings for PortAudio, essential for capturing live audio streams from the microphone.
- Python Weather (python-weather): An asynchronous library used to fetch current weather data and conditions.
- pyttsx3 (pyttsx3): An offline Text-to-Speech (TTS) conversion library that allows the assistant to vocalize its responses to the user.
- RapidFuzz (rapidfuzz): A fast string matching library used for fuzzy search. It helps in matching spoken teacher names against the database, accommodating slight mispronunciations or transcription errors.
- Requests (requests): An HTTP library utilized to send requests to external university web pages for data scraping purposes.
- SpeechRecognition (speechrecognition): A wrapper library that facilitates capturing microphone input, detecting speech, and automatically adjusting for ambient noise levels.

### 4.3.2 AI Models

The system implements the following artificial intelligence models and their associated frameworks to process user input, recognize entities, and generate appropriate responses:

- Whisper ("small"): A Speech-to-Text (STT) model developed by OpenAI (managed via the openai-whisper library), used to transcribe the audio captured from the user’s microphone into text.
- Gemma 3 (gemma3:4b): A Large Language Model (LLM) served via Ollama. It is responsible for generating conversational responses for general queries when no specific predefined intent is detected.
- GLiNER (urchade/gliner_multi-v2.1): A Named Entity Recognition (NER) model (implemented via the gliner library) utilized to extract specific information from the transcribed text. It identifies entities such as room codes and person names (using room code and person labels) to assist in university navigation queries.

- spaCy (pl_core_news_sm): A pre-trained Polish language model operating within the spacy NLP library. It performs word lemmatization and tokenization to quickly and accurately match user queries against predefined intent keywords.

### 4.4 Core Modules Implementation

### 4.4.1 NLP Pipeline

The Natural Language Processing (NLP) pipeline acts as the central coordinator of the humanoid head’s interaction system. Implemented primarily within the NlpModel class, it manages the continuous loop of listening, understanding, and responding to the user. The pipeline is composed of three main stages:

1. Speech-to-Text (STT): The pipeline continuously captures ambient audio via the microphone using the SpeechRecognition library, automatically adjusting for background noise. Once speech is detected, the audio is processed by the Whisper STT model to generate an accurate text transcription.
2. Intent Routing & Processing: The transcribed text is immediately forwarded to the Intent Detection module. This module classifies the user’s query into specific operational branches:
- If a Weather Intent is detected, the system bypasses the LLM and directly queries the weather integration module to retrieve the current conditions.
- If a PG (Politechnika Gdaska) Intent is detected, the text is preprocessed and analyzed by the GLiNER model to extract entities such as room codes or personnel names, which are then passed to the university database modules.
- If No Specific Intent (General) is detected, the transcribed text is fed into the locally hosted Large Language Model (Gemma 3) via LangChain to generate a natural, conversational response.
3. Text-to-Speech (TTS): Regardless of which branch processes the query, the resulting answer is sent to the TTS module (pyttsx3) to be synthesized into audible speech, completing the interaction cycle.

To better illustrate the data flow within the NlpModel, Figure 31 presents the architectural diagram of the pipeline.

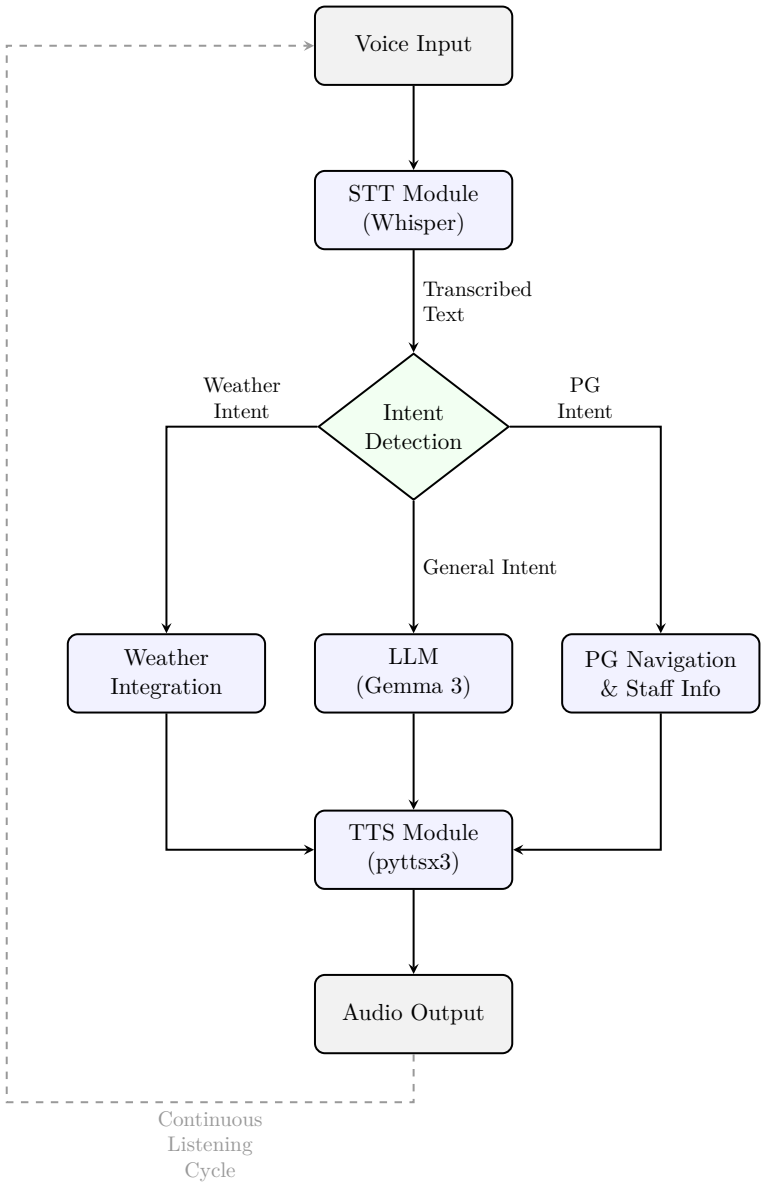
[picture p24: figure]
Voice Input; STT Module (Whisper); Intent Detection; LLM (Gemma 3); Weather Integration; PG Navigation & Staff Info; TTS Module (pyttsx3); Audio Output; Transcribed Text; General Intent; Weather Intent; PG Intent; Continuous Listening Cycle

Figure 31: NLP Pipeline Data Flow.
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

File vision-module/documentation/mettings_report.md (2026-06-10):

# Mettings Report
W celu finalnego połączenia wszystkich modułów w jeden gotowy i poprawnie działający system, spotkaliśmy się w sali koła naukowego CHIP. W spotkaniu uczestniczyła co najmniej jedna osoba z każdego zespołu projektowego (**vision, hardware, speech**).

# Metting at 13.05.2026 from 14:30 to 21:00
**Uczestnicy:** Wszyscy członkowie zespołu (obecność rotacyjna w trakcje trwania spotkania).
## Zrealizowane zadania
Podczas spotkania udało się zrealizować:
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

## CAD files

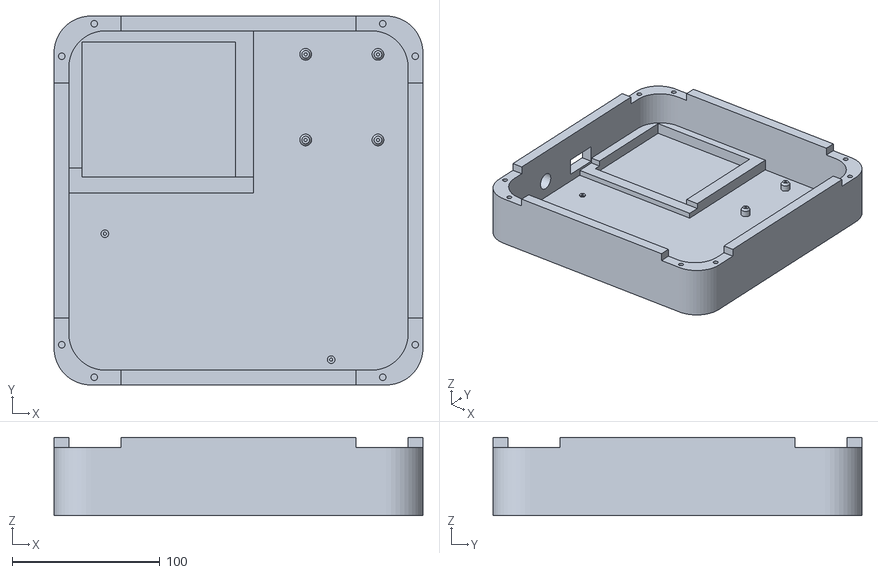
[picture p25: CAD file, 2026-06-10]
hardware-module/3Dmodel/base/base-main.stl
250.0 x 250.0 x 53.0

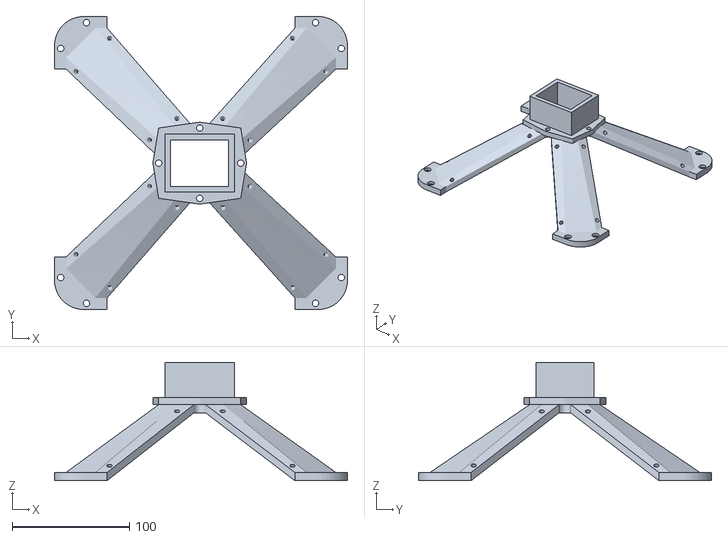
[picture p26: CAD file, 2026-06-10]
hardware-module/3Dmodel/base/base-frame.stl
250.0 x 250.0 x 100.8

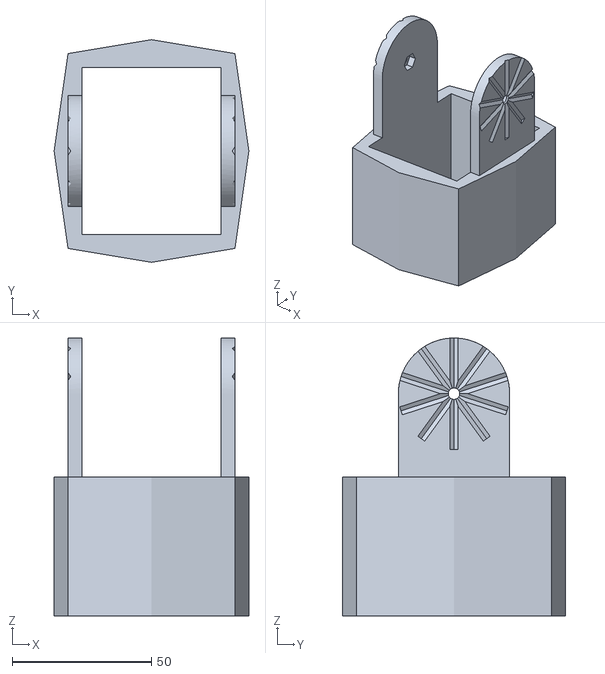
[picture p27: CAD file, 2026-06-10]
hardware-module/3Dmodel/head stl/neck-bottom_V3.stl
70.0 x 80.0 x 99.9

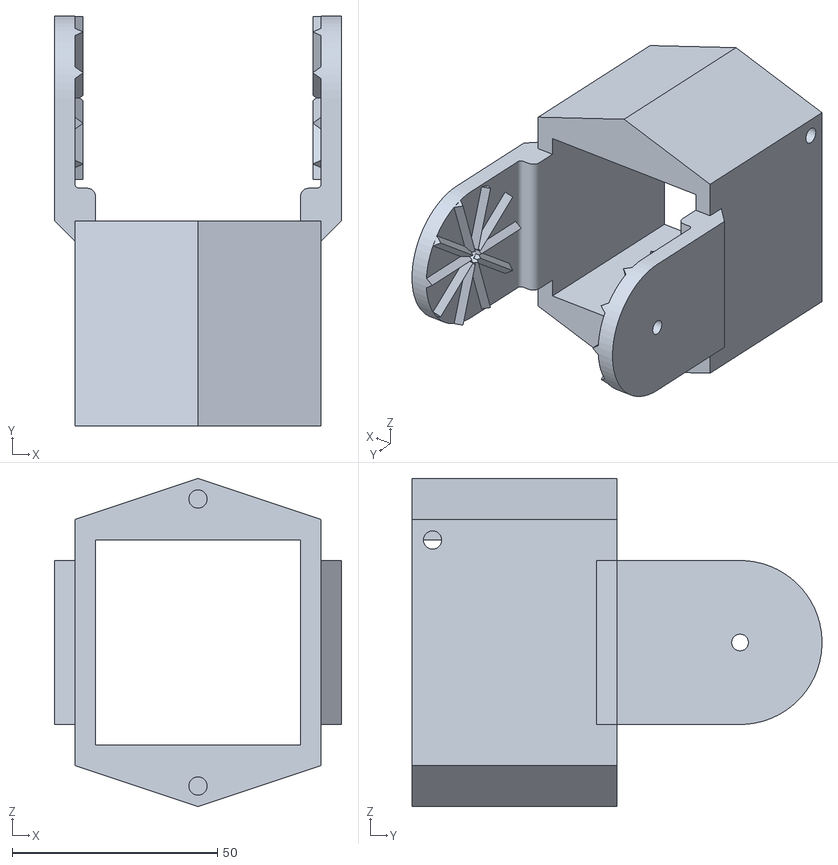
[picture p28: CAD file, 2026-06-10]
hardware-module/3Dmodel/head stl/neck-upper_V4.stl
70.0 x 100.0 x 80.0

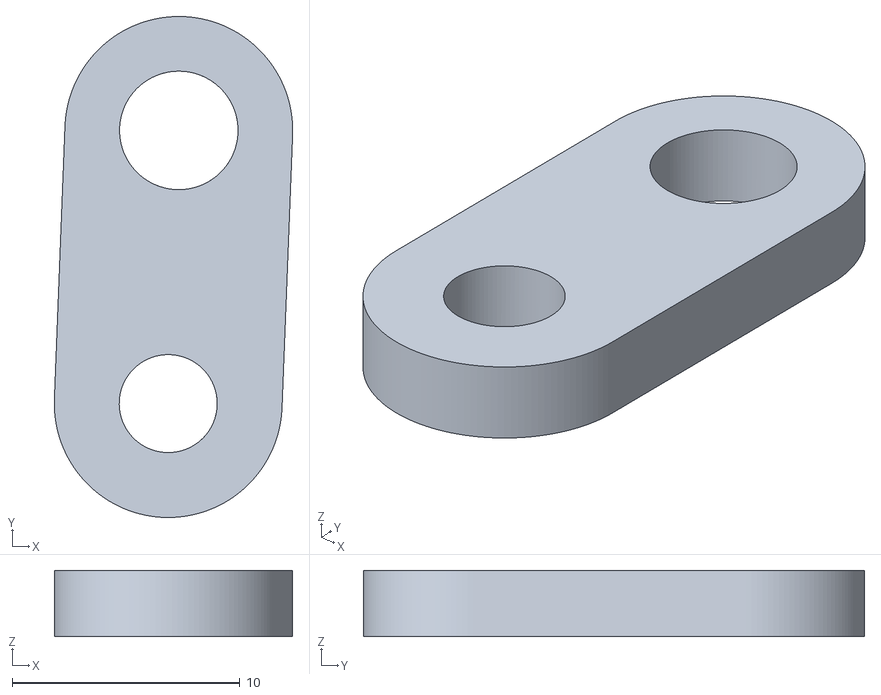
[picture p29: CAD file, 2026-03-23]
hardware-module/3Dmodel/head stl/pad4.stl
10.5 x 22.0 x 2.90

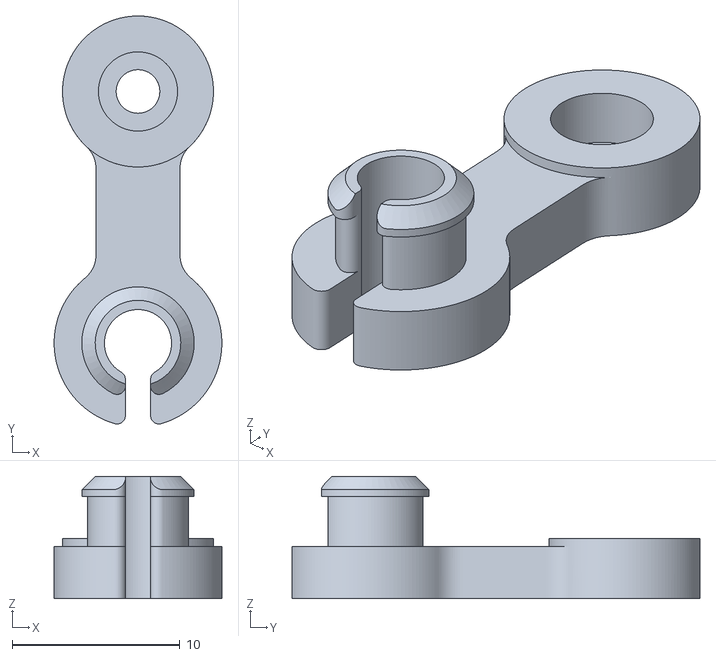
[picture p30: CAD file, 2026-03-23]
hardware-module/3Dmodel/head stl/centralServoHorn.stl
10.00 x 24.3 x 7.30

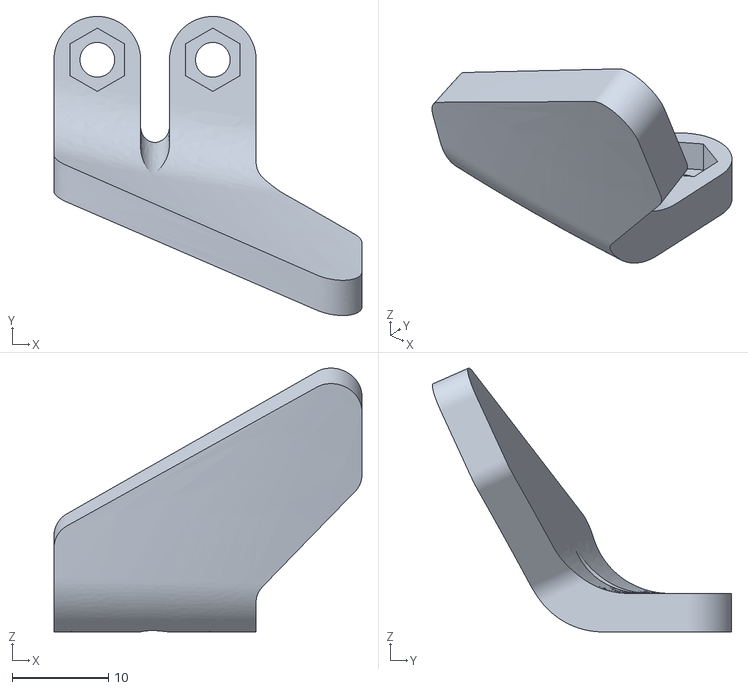
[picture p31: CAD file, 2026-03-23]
hardware-module/3Dmodel/head stl/upperRightLip.stl
32.0 x 31.1 x 27.4

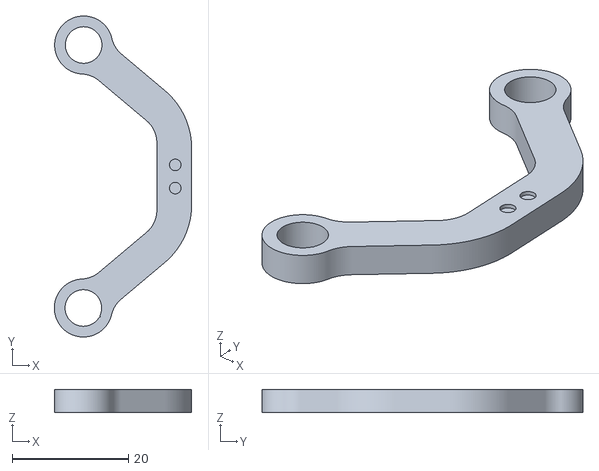
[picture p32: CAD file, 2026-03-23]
hardware-module/3Dmodel/head stl/verticalLever.stl
23.7 x 55.3 x 4.00

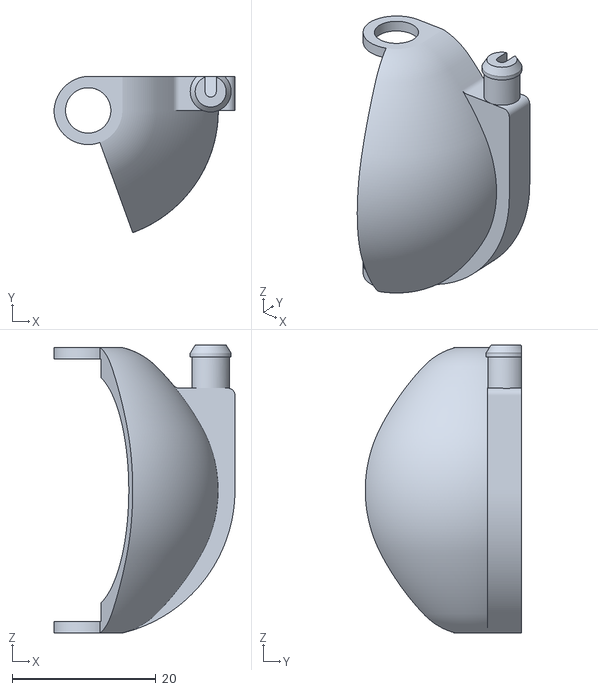
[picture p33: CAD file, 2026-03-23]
hardware-module/3Dmodel/head stl/lid4.stl
25.2 x 21.8 x 40.1

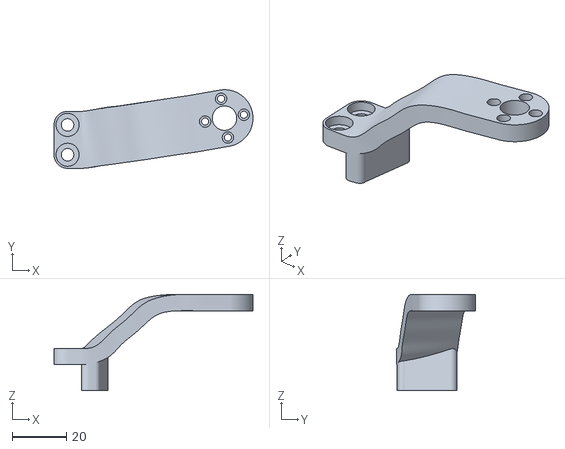
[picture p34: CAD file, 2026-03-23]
hardware-module/3Dmodel/head stl/jawLinkRight.stl
73.3 x 29.0 x 35.5

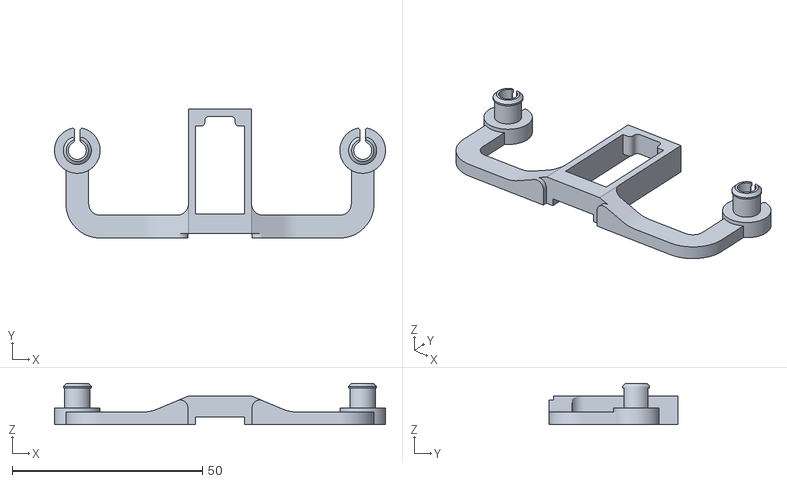
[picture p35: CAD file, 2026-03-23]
hardware-module/3Dmodel/head stl/eyeConnector.stl
87.0 x 33.9 x 10.9

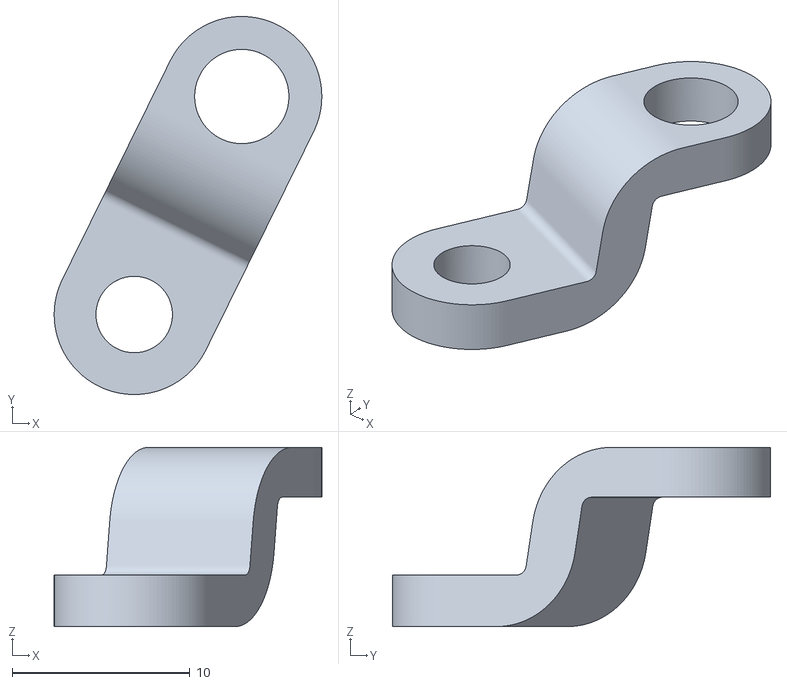
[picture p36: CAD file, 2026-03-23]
hardware-module/3Dmodel/head stl/link2a.stl
15.0 x 21.3 x 10.1

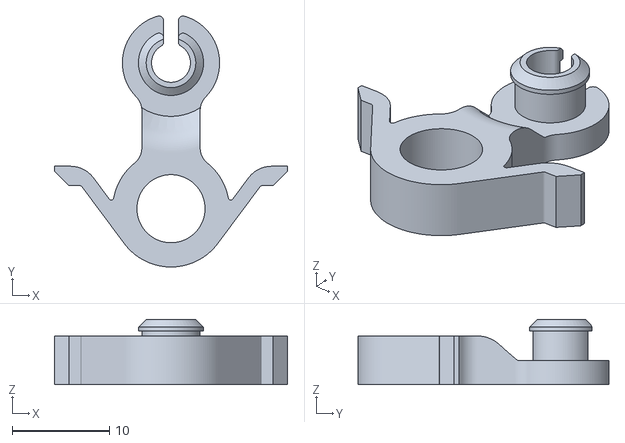
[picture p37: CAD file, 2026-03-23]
hardware-module/3Dmodel/head stl/eyeAdaptor3.stl
24.0 x 25.8 x 6.70

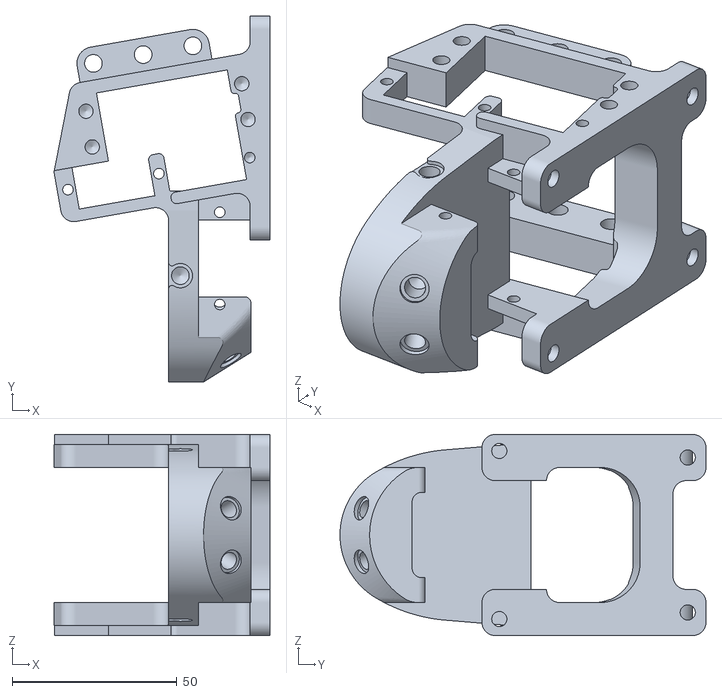
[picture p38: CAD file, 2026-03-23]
hardware-module/3Dmodel/head stl/topBase.stl
65.5 x 111.0 x 61.0

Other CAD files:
hardware-module/3Dmodel/head stl/lid3.stl
hardware-module/3Dmodel/head stl/link3a.stl
hardware-module/3Dmodel/head stl/rampMount1.stl
hardware-module/3Dmodel/head stl/forehead1right.stl
hardware-module/3Dmodel/base/components/POS-150-C power supply.f3d
hardware-module/3Dmodel/head stl/base.stl
hardware-module/3Dmodel/head stl/baseClamp1.stl
hardware-module/3Dmodel/head stl/baseClamp2.stl
hardware-module/3Dmodel/head stl/baseClamp3.stl
hardware-module/3Dmodel/head stl/baseConnector1.stl
hardware-module/3Dmodel/head stl/baseConnector2.stl
hardware-module/3Dmodel/head stl/baseConnector3.stl
hardware-module/3Dmodel/head stl/baseConnector4.stl
hardware-module/3Dmodel/head stl/bottomLidLever1.stl
hardware-module/3Dmodel/head stl/bottomLidLever2.stl
hardware-module/3Dmodel/head stl/braw1.stl
hardware-module/3Dmodel/head stl/braw2.stl
hardware-module/3Dmodel/head stl/cheekBone.stl
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

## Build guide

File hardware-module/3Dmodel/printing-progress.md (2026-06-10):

# 3D Head Model - Printing Progress Report
## Print Checklist
- [X] base.stl
- [X] baseClamp1.stl
- [X] baseClamp2.stl
- [X] baseClamp3.stl
- [X] baseConnector1.stl
- [X] baseConnector2.stl
- [X] baseConnector3.stl
- [X] baseConnector4.stl
- [X] bottomLidLever1.stl
- [X] bottomLidLever2.stl
- [X] braw1.stl
- [X] braw2.stl
- [X] centralServoHorn.stl
- [X] cheekBone.stl
- [X] cheekConnector1a.stl
- [X] cheekConnector1b.stl
- [X] eyeAdaptor1.stl
- [X] eyeAdaptor2.stl
- [X] eyeAdaptor3.stl
- [X] eyeAdaptor4.stl
- [X] eyeConnector.stl
- [X] eyeCorePivotHolder.stl
- [X] eyes.stl
- [X] fanBracket.stl
- [X] forehead1left.stl
- [X] forehead1right.stl
- [X] forehead2left.stl
- [X] forehead2right.stl
- [X] frontPlate.stl
- [X] jawBase.stl
- [X] jawConnector.stl
- [X] jawLinkLeft.stl
- [X] jawLinkRight.stl
- [X] lid1.stl
- [X] lid2.stl
- [X] lid3.stl
- [X] lid4.stl
- [X] link1a.stl
- [X] link1b.stl
- [X] link2a.stl
- [X] link2b.stl
- [X] link3a.stl
- [X] link3b.stl
- [X] link3c.stl
- [X] link3d.stl
- [X] lowerLipLeft.stl
- [X] lowerLipRight.stl
- [X] mount1Left.stl
- [X] mount1Right.stl
- [X] pad1.stl
- [X] pad2.stl
- [X] pad3.stl
- [X] pad4.stl
- [X] rampMount1.stl
- [X] rampMount2.stl
- [X] rearPlate.stl
- [X] skullFrame.stl
- [X] smallMount1.stl
- [X] smallMount2.stl
- [X] smallMount3.stl
- [X] smallMount4.stl
- [X] sMountLeft.stl
- [X] sMountRight.stl
- [X] structure.stl
- [X] tongueConnector1.stl
- [X] tongueConnector2.stl
- [X] topBase.stl
- [X] topLidHorn1.stl
- [X] topLidHorn2.stl
- [X] topLidHorn3.stl
- [X] topLidHorn4.stl
- [X] topLidLever1.stl
- [X] topLidLever2.stl
- [X] trippleLink.stl
- [X] upperLeftLip.stl
- [X] upperRightLip.stl
- [X] verticalHorn.stl
- [X] verticalLever.stl
- [X] teethDown.stl
- [X] teethUp.stl
- [X] tongue.stl

---

- [X] base-main.stl
- [X] neck-bottom_V3.stl
- [X] neck-upper_V4.stl
- [X] microphone-wall.stl
- [X] microphone-sensor-wall.stl
- [X] normall-wall.stl
- [X] normall-wall.stl
- [X] normall-wall.stl
- [ ] short-wall.stl
## To reprint in PETG: 
- [X] cam_holder_V2.stl
- [X] CentralServoHorn
- [x] 38.stl
- [x] 3.stl
- [x] cam_holder_v3.stl

## Problems
* Encountered a failure printing "skullFrame" 3D part twice. The G-code has been modified to resolve the issue.
* Encountered a failure printing "sMountRight" 3D part. The part will be reprinted in a later batch with modified supports.
* Encountered a failure printing "readPlate" 3D part due to support failure. G-Code modified with new tree supports.
* Encountered a third failure while printing the "skullFrame" 3D part. The G-code has been updated with a different support type.
* Encountered a failure printing multiple parts: "lid1", "lid1", "lid1", "lid1", "trippleLink" and "eyeCorePivotHolder". Parts will be reprinted in a later batch with different supports.
* Encountered a fourth failure while printing the "skullFrame" 3D part. Problem unknown. Re-printing part again. Decided to upload photos of failures.
* Encountered a failure printing "eyes" 3D part due to printer misscalibration. Brim settings changed to resolve the issue.
* 5th failure printing "skullFrame" 3D part. This time tried different fillament and different printer. Seam settings updated to random.
* Parts broke during assembly - topLidHorn(1-4) and rampMount1. RampMount reprinted without changes. TopLidHorns will be reprinted with new g-code with different angles.
* 6th failure printing "skullFrame" 3D part. Broken sections weres printed seperetly and attached to the model with soldering iron and hot air
* Parts broke during assembly - centralServoHorn, EyeAdaptor3 and cheekBone. Parts will be reprinted with new g-code with different angles.
* Parts broke during assembly - topLidHorn, link2a. Parts will be reprinted with new g-code with different angles.
* Encountered second failure printing "rearPlate" - part will be reprinted in different printer(bambulab).
* Encountered a move parsing failure printing "base-frame" 3D part -  printer will be recalibrated and the G-code will be modified to resolve the issue
* cam-holder needs to be thicker and printed in different orientation - screw broke it
* encountered problem printing short-wall. gcode will be modified accordingly
* camholder hole to low. updated 3D model to version 3. updated g-code

---
*Last Update: 05-06-2026

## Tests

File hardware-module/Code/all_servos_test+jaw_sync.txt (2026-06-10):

#include <Arduino.h>
#include <Wire.h>
#include <Adafruit_PWMServoDriver.h>

Adafruit_PWMServoDriver driverSO = Adafruit_PWMServoDriver(0x40); 
Adafruit_PWMServoDriver driverR  = Adafruit_PWMServoDriver(0x41); // soldered LSB jumper on pwm driver

#define SERVOMID 300   //check position for each servo
const int tilt = 15;

struct SerwoIndywidualne {
  uint8_t pin;           
  unsigned long interwal; 
  unsigned long lastMovement; 
  bool stan;             
  uint8_t idSterownika; 
};

// 19 servos - withouth jaw ones
SerwoIndywidualne myServos[] = {
  {10, 1200, 0, false, 0},
   {9, 1200, 0, false, 0},
    {8, 1500, 0, false, 0},
  {7, 2000, 0, false, 0},
   {6, 500, 0, false, 0},
    {5, 800, 0, false, 0},
  {4, 1200, 0, false, 0},
   {3, 1500, 0, false, 0},
    {2, 2000, 0, false, 0},
  {9, 1200, 0, false, 1},
   {8, 1500, 0, false, 1},
    {7, 2000, 0, false, 1},
  {6, 500, 0, false, 1},
   {5, 800, 0, false, 1},
    {4, 1200, 0, false, 1},
  {3, 1500, 0, false, 1},
   {2, 2000, 0, false, 1},
    {1, 3000, 0, false, 1},
  {0, 3000, 0, false, 1}
};

const int iloscSerw = 19;

unsigned long jawTime = 0;
unsigned long interwalSzczeki = 3000;
bool jawState = false;
const uint8_t jawServoPin1 = 0; // driver SO
const uint8_t jawServoPin2 = 1; // driver SO

void setup() {
  Serial.begin(9600);
  driverSO.begin();
  driverSO.setOscillatorFrequency(27000000);
  driverSO.setPWMFreq(50);

  driverR.begin();
  driverR.setOscillatorFrequency(27000000);
  driverR.setPWMFreq(50);

  delay(10);
}

void loop() {
  unsigned long currentTimeMillis = millis();

  if (currentTimeMillis - jawTime >= interwalSzczeki) {
    jawTime = currentTimeMillis;
    
    if (jawState == false) {
   
      driverSO.setPWM(jawServoPin1, 0, SERVOMID + tilt);
      driverSO.setPWM(jawServoPin2, 0, SERVOMID - tilt);
      jawState = true;
    } else {
     
      driverSO.setPWM(jawServoPin1, 0, SERVOMID - tilt);
      driverSO.setPWM(jawServoPin2, 0, SERVOMID + tilt);
      jawState = false;
    }
    Serial.println("Jaw movement - mirroring");
  }

  for (int i = 0; i < iloscSerw; i++) {
    if (currentTimeMillis - myServos[i].lastMovement >= myServos[i].interwal) {
      myServos[i].lastMovement = currentTimeMillis;

      int position = myServos[i].stan ? (SERVOMID - tilt) : (SERVOMID + tilt);
      myServos[i].stan = !myServos[i].stan;

      if (myServos[i].idSterownika == 0) {
        driverSO.setPWM(myServos[i].pin, 0, position);
      } else {
        driverR.setPWM(myServos[i].pin, 0, position);
      }
    }
  }
}

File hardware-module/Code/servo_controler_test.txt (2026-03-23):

#include <Arduino.h>
#include <Wire.h>
#include <Adafruit_PWMServoDriver.h>

Adafruit_PWMServoDriver pwm = Adafruit_PWMServoDriver();
#define SERVOMIN  100   //  0° 
#define SERVOMAX  480   // 180°

uint8_t servoNumber = 5;

unsigned long currentTime = 0;
unsigned long previousTime = 0;
unsigned long interval = 0;
int stage = 0;

void setAngle(uint8_t channelNumber, uint8_t angle) {
  angle = constrain(angle, 0, 180); 
  uint16_t pulse = map(angle, 0, 180, SERVOMIN, SERVOMAX);
  pwm.setPWM(channelNumber, 0, pulse);
}

void setup() {
  Serial.begin(9600);
  Serial.println("Starting PCA9685 test...");

  pwm.begin();
  pwm.setOscillatorFrequency(27000000);
  pwm.setPWMFreq(50);
  
  // This small setup delay (10ms) is recommended by the library creators
  // to allow the PCA9685 to boot up correctly.
  delay(10); 
}

void loop() {
  
  currentTime = millis();

  if (currentTime - previousTime >= interval) {
    
    previousTime = currentTime; 

    switch (stage) {
      case 0:
        Serial.println("Position: 0 degrees");
        setAngle(servoNumber, 0);
        interval = 1500; 
        stage = 1;       
        break;

      case 1:
        Serial.println("Position: 180 degrees");
        setAngle(servoNumber, 180);
        interval = 1500; 
        stage = 2;       
        break;

      case 2:
        Serial.println("Position: 90 degrees (center). Now 5 seconds pause...");
        setAngle(servoNumber, 90);
        interval = 5000; 
        stage = 0;        
        break;
    }
  }
}

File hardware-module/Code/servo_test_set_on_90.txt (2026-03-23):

#include <Arduino.h>  
#include <Servo.h>

Servo mojeSerwo;  
const int pinSerwa = 9; 

void setup() {
  Serial.begin(9600);
  Serial.println("Rozpoczynam skokowy test serwa...");
  mojeSerwo.attach(pinSerwa); 
}

void loop() {
  Serial.println("Ruch: 90");
  mojeSerwo.write(90);        
  delay(1500);

  Serial.println("Ruch: 0");
  mojeSerwo.write(0); 
  delay(1500);

  Serial.println("Ruch: 180");
  mojeSerwo.write(180);   
  delay(1500);

  Serial.println("Ruch: 90 (Środek). Teraz 5 sekund pauzy...");
  mojeSerwo.write(90);  
  delay(5000); // Oczekiwanie 5 sekund przed powtórzeniem pętli
}

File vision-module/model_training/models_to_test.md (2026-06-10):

\# Models to Test (Image Generation)

A curated list of next-generation image generation models to evaluate and compare within the project:

\## 1. Hunyuan Image 3.0

\*   \*\*Provider:\*\* Tencent

\*   \*\*Type:\*\* Open-source (Autoregressive MoE, 80B parameters)

\*   \*\*Key Features:\*\* Excellent comprehension of highly complex, long-form prompts. Strong balance between photorealism and semantic accuracy.

\*   \*\*Testing Method:\*\* Local deployment (Hugging Face / `diffusers`) or dedicated API.

\## 2. Flux 2 Max

\*   \*\*Provider:\*\* Black Forest Labs

\*   \*\*Type:\*\* Commercial API / Closed-source

\*   \*\*Key Features:\*\* Flagship quality, superior character consistency, ultra-photorealism, and exceptional text rendering capabilities.

\*   \*\*Testing Method:\*\* External APIs (e.g., Fal.ai, Replicate).

\## 3. Qwen-Image-2.0-Pro

\*   \*\*Provider:\*\* Alibaba Cloud

\*   \*\*Type:\*\* Commercial API

\*   \*\*Key Features:\*\* Unified generation and editing capabilities operating in native 2K resolution. Outstanding performance with text rendering, infographics, and poster design.

\*   \*\*Testing Method:\*\* Multi-provider APIs (e.g., Together AI).

\## 4. Reve V1.5

\*   \*\*Provider:\*\* Reve Image

\*   \*\*Type:\*\* Commercial API / Closed-source

\*   \*\*Key Features:\*\* Generates images directly in native 4K pixel space without relying on latent autoencoder compression. Exceptional lighting, intricate textures, and highly rated in current benchmarks.

\*   \*\*Testing Method:\*\* Dedicated Reve platform API.

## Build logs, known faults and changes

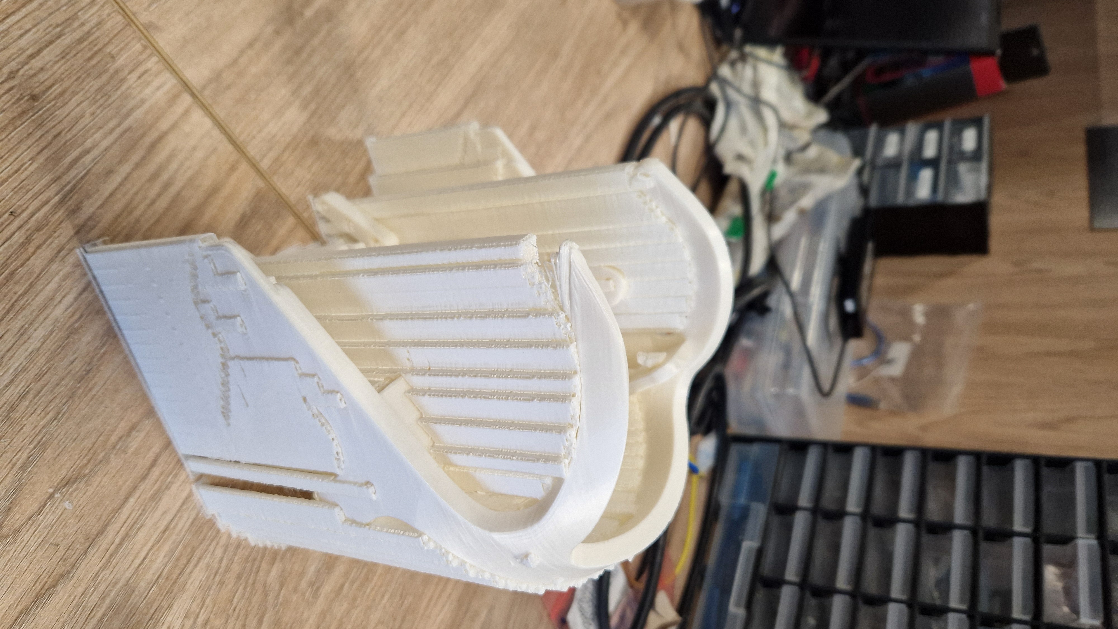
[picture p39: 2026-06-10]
hardware-module/3Dmodel/Photos/failure1_2.jpg

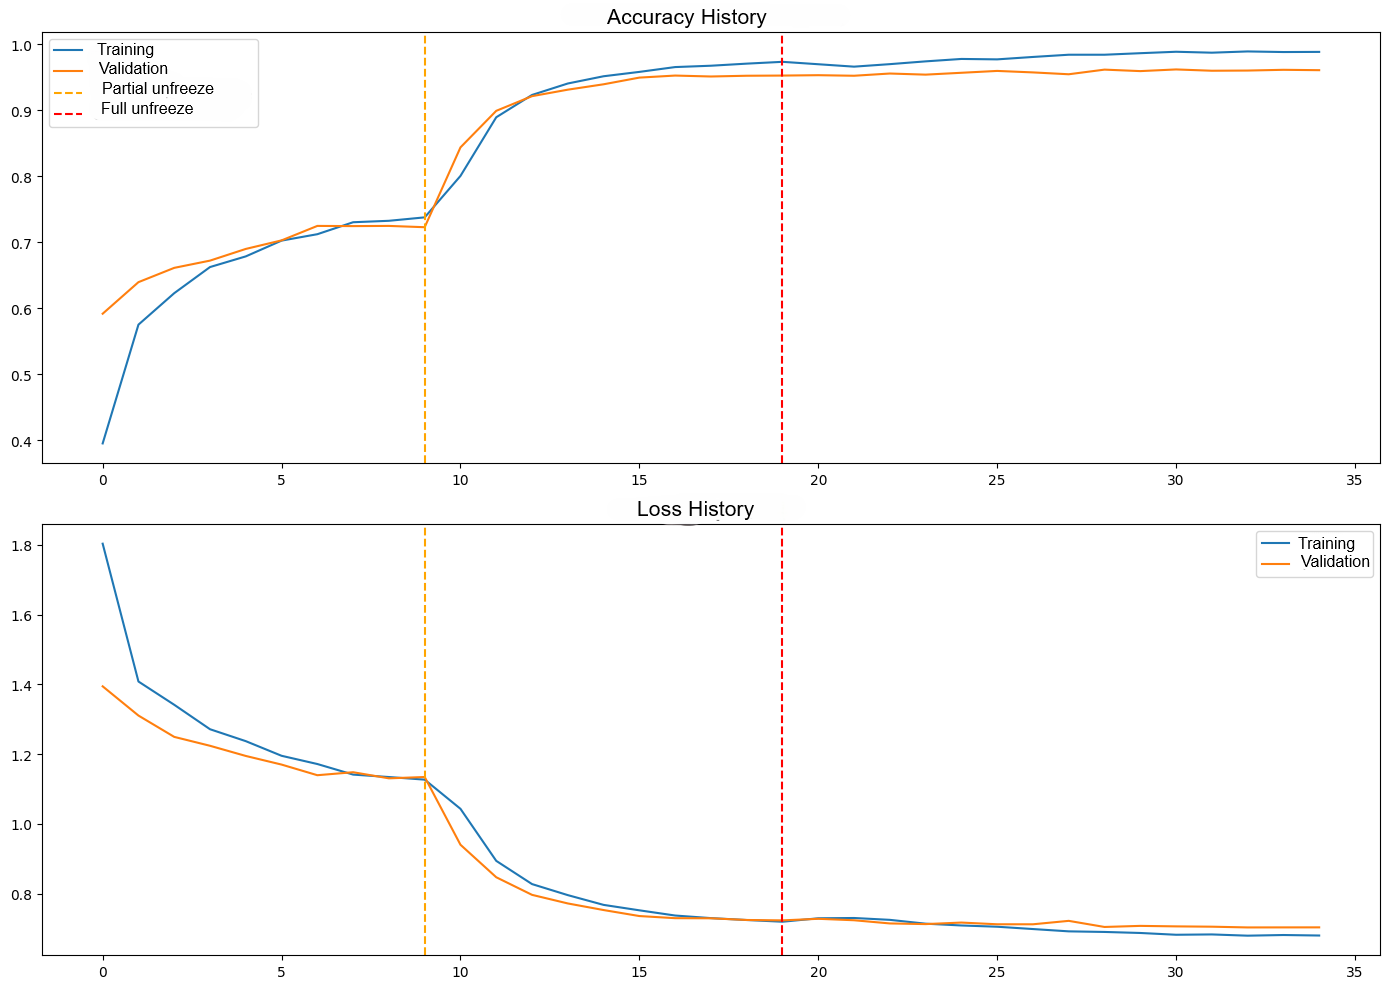
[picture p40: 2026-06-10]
vision-module/images/flux3_history.png

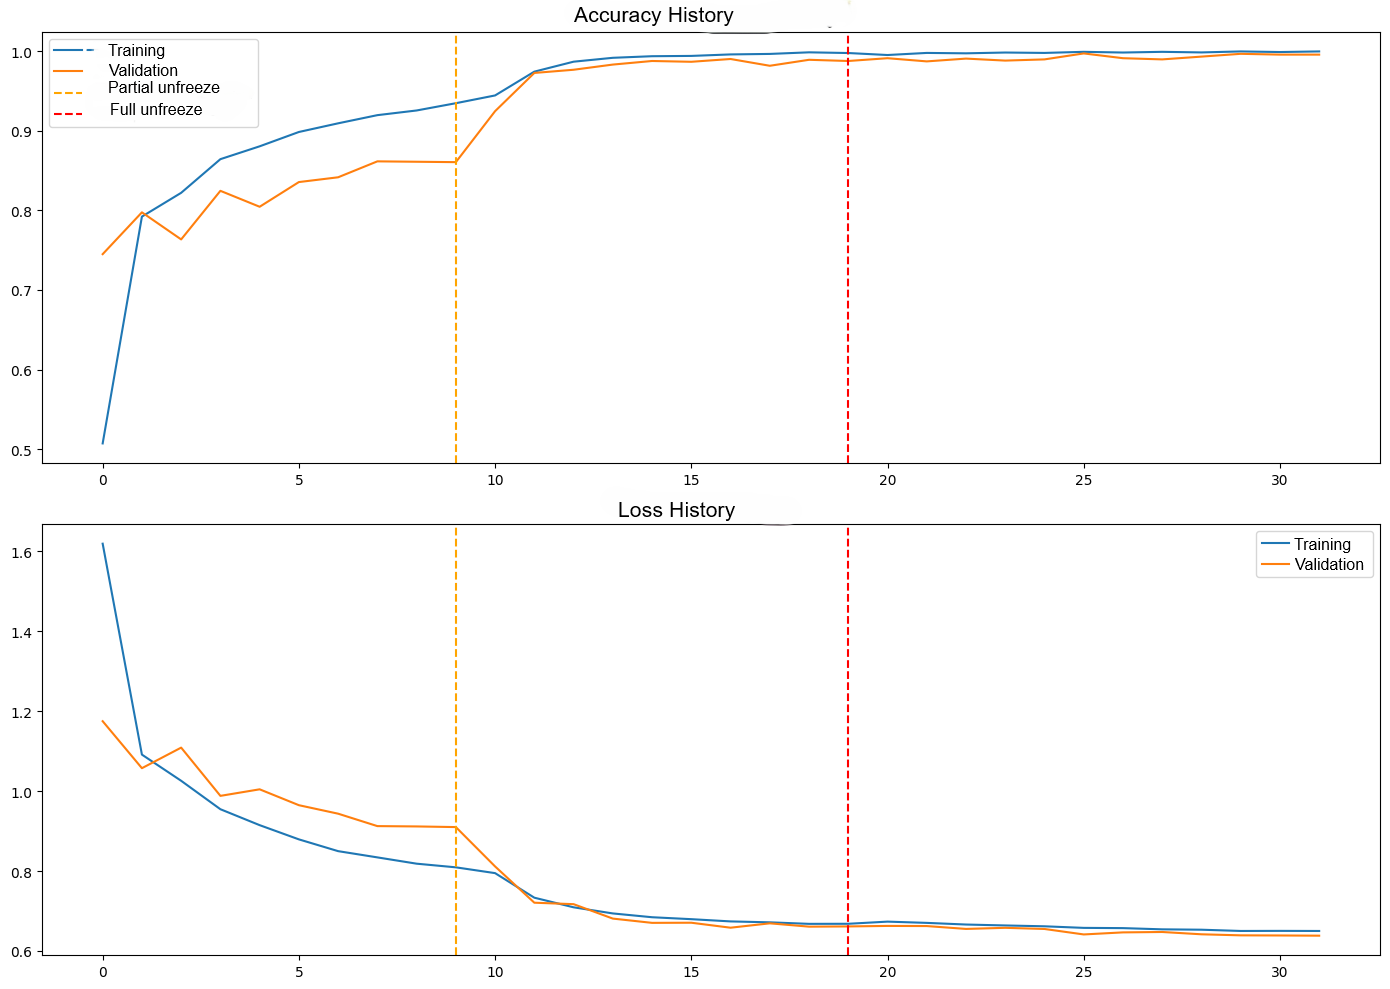
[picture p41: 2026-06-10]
vision-module/images/flux1_history.png

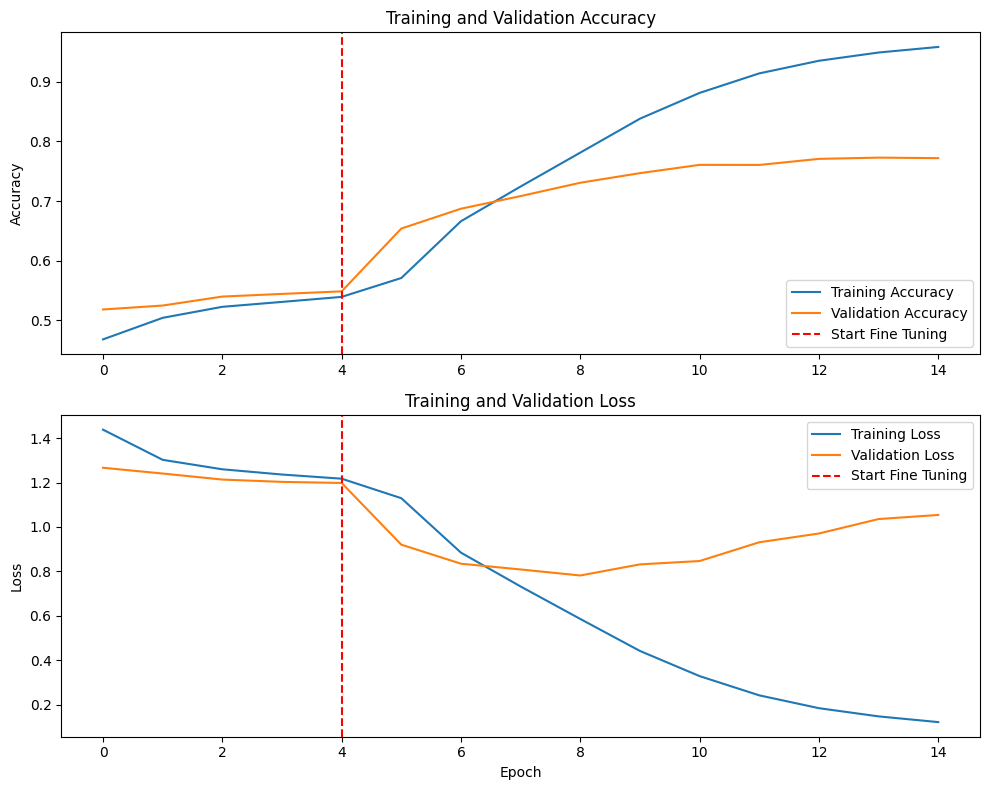
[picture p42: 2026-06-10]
vision-module/images/resnet101_run2_history.png

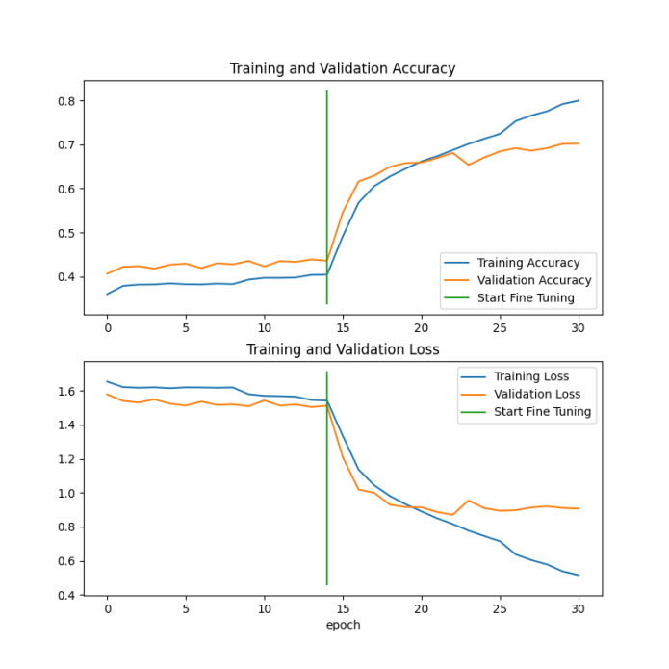
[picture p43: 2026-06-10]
vision-module/images/xception_history.png

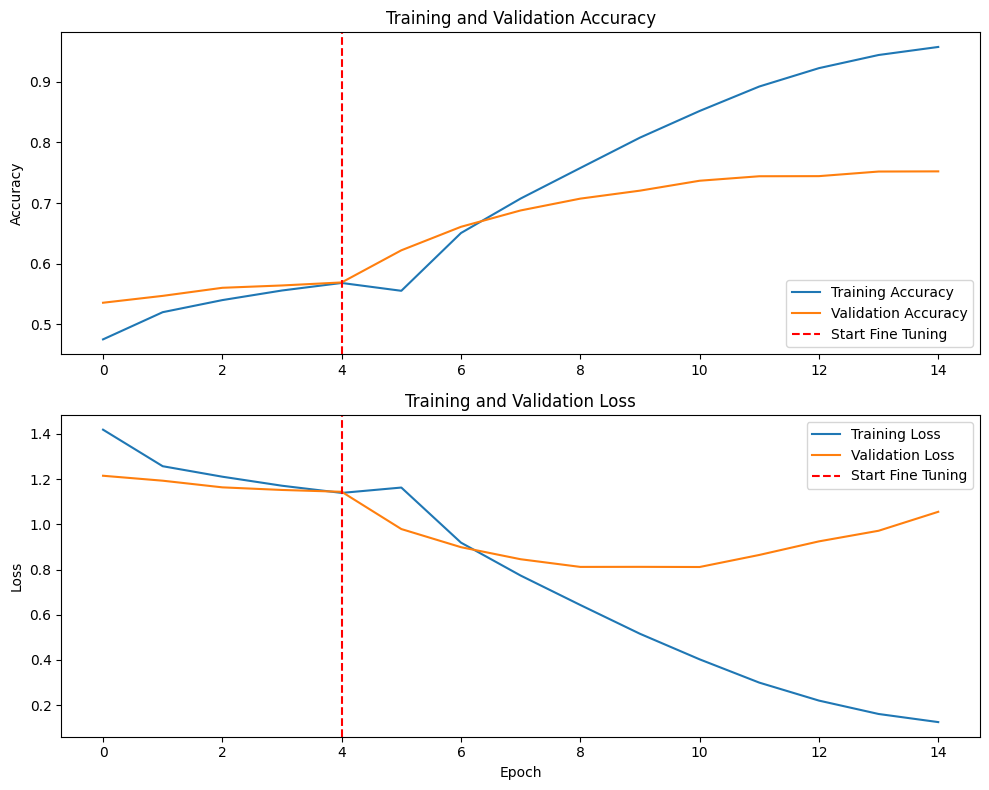
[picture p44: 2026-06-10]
vision-module/images/resnet50_run2_history.png

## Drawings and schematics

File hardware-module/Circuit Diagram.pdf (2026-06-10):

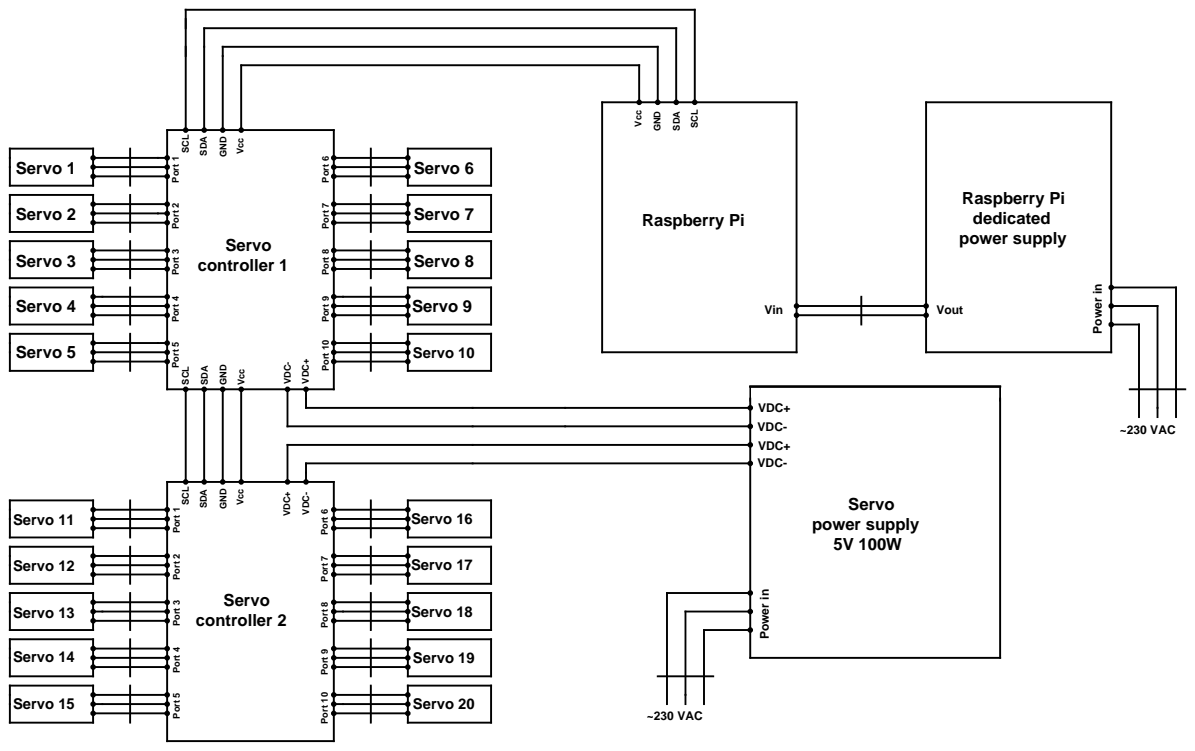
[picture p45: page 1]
Power in; Servo 1; Servo 2; Servo 3; Servo 4; Servo 5; Servo 6; Servo 7; Servo 8; Servo 9; Servo 10; Servo 11; Servo 12; Servo 13; Servo 14; Servo 15; Servo 16; Servo 17; Servo 18; Servo 19; Servo 20; Servo controller 1; Servo controller 2; Raspberry Pi; Raspberry Pi dedicated power supply; Servo power supply 5V 100W; Vcc; GND; SDA; SCL; ~230 VAC; Vout; VDC+ VDC-; VDC-; VDC+; Port 5; Port 4; Port 3; Port 2; Port 1; Port 10; Port 9; Port 8; Port 7; Port 6; Vin

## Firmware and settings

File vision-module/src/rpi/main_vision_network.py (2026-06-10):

import os

os.environ['TF_CPP_MIN_LOG_LEVEL'] = '3'  # suppress TF logs before importing keras
import cv2
import numpy as np
import sqlite3
import pickle
import random
import time
import threading
import sys
import requests
from collections import deque, Counter
from flask import Flask, Response, render_template_string, request, jsonify
from picamera2 import Picamera2
from keras.models import load_model
from adafruit_pca9685 import PCA9685
from adafruit_motor import servo
from face_tracker import move
from adafruit_extended_bus import ExtendedI2C as I2C

DB_FILE = 'faces.db'
DETECTOR_MODEL = 'face_detection_yunet_2023mar.onnx'
RECOGNIZER_MODEL = 'face_recognition_sface_2021dec.onnx'
EMOTION_MODEL = 'model.keras'
MATCH_THRESHOLD = 0.28
EMOTIONS = ['angry', 'disgust', 'fear', 'happy', 'neutral', 'sad', 'surprise']
EMOTION_SKIP_FRAMES = 2
CAM_WIDTH = 1024
CAM_HEIGHT = 864

# Dictionary of emotions for the robot to mimic
face_emo = {
    "happy": [
        [(11, 50), (12, 95), (15, 10), (16, 25)],
        [(10, 45)],
        [(19, 150), (18, 70)],
        [(20, 60), (17, 130)],
        [(3, 75), (8, 35), (5, 50), (6, 60)],
        [(2, 100), (4, 30), (7, 110), (9, 10)]],
    "sad": [
        [(11, 25), (12, 60), (15, 50), (16, 70)],
        [(10, 45)],
        [(19, 160), (18, 20)],
        [(20, 30), (17, 70)],
        [(3, 20), (8, 85), (5, 13), (6, 100)],
        [(2, 40), (4, 50), (7, 30), (9, 60)]
    ],
    "surprise": [
        [(11, 0), (12, 110), (15, 0), (16, 90)],
        [(10, 65)],
        [(19, 150), (18, 10)],
        [(20, 50), (17, 60)],
        [(3, 20), (8, 85), (5, 90), (6, 50)],
        [(2, 65), (4, 60), (7, 50), (9, 40)]
    ],
    "neutral": [

        [(11, 25), (12, 70), (15, 40), (16, 70)],
        [(10, 45)],
        [(19, 110), (18, 60)],
        [(20, 50), (17, 110)],
        [(3, 30), (8, 67), (5, 90), (6, 60)],
        [(2, 65), (4, 60), (7, 50), (9, 40)]
    ]
}

# Enforcing limits on individual servos
servos_config = {
    1: {'driver': 0, 'pin': 1, 'min': 100, 'max': 135, 'wlaczone': True},
    2: {'driver': 0, 'pin': 2, 'min': 50, 'max': 65, 'wlaczone': True},
    3: {'driver': 0, 'pin': 3, 'min': 20, 'max': 80, 'wlaczone': True},
    4: {'driver': 0, 'pin': 4, 'min': 50, 'max': 70, 'wlaczone': True},
    5: {'driver': 0, 'pin': 5, 'min': 30, 'max': 70, 'wlaczone': True},
    6: {'driver': 0, 'pin': 6, 'min': 45, 'max': 110, 'wlaczone': True},
    7: {'driver': 0, 'pin': 7, 'min': 40, 'max': 60, 'wlaczone': True},
    8: {'driver': 0, 'pin': 8, 'min': 35, 'max': 85, 'wlaczone': True},
    9: {'driver': 0, 'pin': 9, 'min': 10, 'max': 40, 'wlaczone': True},
    10: {'driver': 0, 'pin': 10, 'min': 50, 'max': 70, 'wlaczone': True},
    11: {'driver': 1, 'pin': 0, 'min': 0, 'max': 60, 'wlaczone': True},  # dolna prawa powieka
    12: {'driver': 1, 'pin': 1, 'min': 30, 'max': 100, 'wlaczone': True},  # gorna prawa powieka
    13: {'driver': 1, 'pin': 2, 'min': 40, 'max': 120, 'wlaczone': True, 'center': 60},
    14: {'driver': 1, 'pin': 3, 'min': 50, 'max': 110, 'wlaczone': True, 'center': 100},  # eyes left-right
    15: {'driver': 1, 'pin': 4, 'min': 10, 'max': 80, 'wlaczone': True},  # lewa gorna powieka
    16: {'driver': 1, 'pin': 5, 'min': 25, 'max': 70, 'wlaczone': True},  # lewa dolna powieka
    17: {'driver': 1, 'pin': 6, 'min': 40, 'max': 100, 'wlaczone': False},  # prawa brew zewnetrzna
    18: {'driver': 1, 'pin': 7, 'min': 0, 'max': 80, 'wlaczone': False},  # prawa brew wewnetrzna
    19: {'driver': 1, 'pin': 8, 'min': 80, 'max': 170, 'wlaczone': True},  # lewa brew wew
    20: {'driver': 1, 'pin': 9, 'min': 20, 'max': 80, 'wlaczone': True}  # lewa brew zew
}

try:
    i2c = I2C(4)
    driverSO = PCA9685(i2c, address=0x40)
    driverR = PCA9685(i2c, address=0x41)
    driverSO.frequency = 50
    driverR.frequency = 50

except Exception as e:
    print(f"I2C initialization error (are you testing without hardware?): {e}")
    driverR = None
    driverSO = None

servo_objects = {}
if driverSO and driverR:
    for servo_id, cfg in servos_config.items():
        drv = driverSO if cfg['driver'] == 0 else driverR
        servo_objects[servo_id] = servo.Servo(drv.channels[cfg['pin']], min_pulse=730, max_pulse=2930)

app = Flask(__name__)


def map_servo_value(value, in_min, in_max, out_min, out_max):
    """ Maps value from an input range to an output range.
        Commonly used for translating camera pixel coordinates to servo angles"""
    return (value - in_min) * (out_max - out_min) / (in_max - in_min) + out_min


_servo_lock = threading.Lock()


def set_servo_angle(servo_id, angle):
    """Function help with checking if the servos
        are enabled and if it is
        the angel will be set on target servo
        and applies mirroring
        logic for paired servos to ensure symmetric movements """
    try:
        cfg = servos_config.get(servo_id)
        if not cfg or not cfg['wlaczone']:
            return
        if servo_id not in servo_objects:
            return

        limit_min = min(cfg['min'], cfg['max'])
        limit_max = max(cfg['min'], cfg['max'])
        safe_angle = max(limit_min, min(angle, limit_max))

        with _servo_lock:
            servo_objects[servo_id].angle = safe_angle

            if servo_id in (1, 10):
                other_id = 10 if servo_id == 1 else 1
                cfg1 = servos_config[servo_id]
                cfg2 = servos_config[other_id]
                ratio = (safe_angle - cfg1['min']) / (cfg1['max'] - cfg1['min'])
                mirror_angle = max(cfg2['min'],
                                   min(round(cfg2['max'] - ratio * (cfg2['max'] - cfg2['min'])), cfg2['max']))
                if other_id in servo_objects:
                    servo_objects[other_id].angle = mirror_angle
    except Exception as e:
        print(f"[set_servo_angle] servo={servo_id} angle={angle} error={e}", flush=True)


# Function for tracking the user with eyes
""" The camWidth is mapping for servo angels and it 
helps to track the user face with robot eyes """


def track_face(x, y):
    """The robot's eye servos to track the user's face based on
    the given (x,y) pixel cordinates of the deteced face's bounding box center"""
    target_x = map_servo_value(x, 100, CAM_WIDTH, servos_config[14]['max'], servos_config[14]['min'])
    set_servo_angle(14, target_x)
    target_y = map_servo_value(y, 100, CAM_HEIGHT, servos_config[13]['max'], servos_config[13]['min'])
    set_servo_angle(13, target_y - 55)


class FaceSystem:
    """ Main class for managing face detection, recognition, emotion classification,
        and controlling the robot's responses like (eyes, mouth, and facial expressions"""

    def __init__(self):
        """
        Initializes the FaceSystem, including CNN models for face
        detection and recognition, emotion analysis, database connections,
        camera configuration, background threads, and internal states.
        """
        self.detector = cv2.FaceDetectorYN.create(DETECTOR_MODEL, "", (CAM_WIDTH, CAM_HEIGHT), 0.6, 0.3, 5000)
        self.recognizer = cv2.FaceRecognizerSF.create(RECOGNIZER_MODEL, "")
        self.emotion_net = load_model(EMOTION_MODEL)
        self.db = sqlite3.connect(DB_FILE, check_same_thread=False)
        self.init_db()
        self.db_names, self.db_vecs = self.load_users()
        self.picam2 = Picamera2()
        config = self.picam2.create_preview_configuration(main={"format": "RGB888", "size": (CAM_WIDTH, CAM_HEIGHT)})
        self.picam2.configure(config)
        self.picam2.start()

        self.last_feat = None
        self.is_saving = False
        self.hist = {}
        self.last_emo = {}
        self.f_count = 0
        self.locked_identity = "Unknown"
        self.locked_emotion = "Neutral"
        self.is_session_active = False
        self.face_lost_time = None
        self.id_buffer = deque(maxlen=7)
        self.face_visible = False
        self.double_blink = False
        self.bbox_cent = None
        self.mouth_angle = 0

        self.last_blink_time = 0
        self.blink_interval = 5.0
        self.is_blinking = False
        self.blink_start_time = 0
        self.just_did_double = False
        self.just_did_double = False
        self.last_mouth_signal = 0.0

        # maxlen=1 ensures that if the robot is busy animating, we discard older emotions
        # It will always react to the most recent one, preventing reaction lag or desync
        self.emotion_queue = deque(maxlen=1)

        self.is_animating = False

        # Threads for individual robot functionalities
        threading.Thread(target=self.move_eyes, daemon=True).start()
        threading.Thread(target=self.move_mouth, daemon=True).start()
        threading.Thread(target=self.emotion_worker, daemon=True).start()

    def init_db(self):
        """
        Initilizes the SQLite database.Creates the 'users' table for storing
        saved faces and their encodings if it doesn't already exist.
        """
        cur = self.db.cursor()
        cur.execute("""
                    CREATE TABLE IF NOT EXISTS users
                    (
                        id
                        INTEGER
                        PRIMARY
                        KEY
                        AUTOINCREMENT,
                        name
                        TEXT,
                        encoding
                        BLOB,
                        created_at
                        TIMESTAMP
                        DEFAULT
                        CURRENT_TIMESTAMP
                    )
                    """)
        self.db.commit()

    def cleanup_db(self):
        """ Cleans up the user database by deleting entries older than 7 days or
        trimming the oldest entries if the tottal record count exceeds 200"""
        cur = self.db.cursor()
        cur.execute("DELETE FROM users WHERE created_at <= datetime('now', '-7 days')")
        cur.execute("SELECT COUNT(*) FROM users")
        count = cur.fetchone()[0]
        if count > 200:
            limit = count - 200
            cur.execute(f"DELETE FROM users WHERE id IN (SELECT id FROM users ORDER BY created_at ASC LIMIT {limit})")
        self.db.commit()

    def load_users(self):
        """
        Retrieves all saved user names and their face encodings
        from the SQLite database into memory.
        """
        cur = self.db.cursor()
        cur.execute("SELECT name, encoding FROM users")
        rows = cur.fetchall()
        if not rows:
            return [], []
        names = [r[0] for r in rows]
        vecs = [pickle.loads(r[1]) for r in rows]
        return names, vecs

    # Robot eye blinking
    def eye_blink(self):
        """
        This function describe robot's blinking mechanism. Implements variable timing intervals
        and occasional double blinks to make the eye movements appear more natural.
        """
        current_time = time.time()
        if not self.is_blinking and (current_time - self.last_blink_time) > self.blink_interval:
            self.is_blinking = True
            self.blink_start_time = current_time
            set_servo_angle(12, 35)
            set_servo_angle(11, 75)
            set_servo_angle(15, 85)
            set_servo_angle(16, 30)
        if self.is_blinking and (current_time - self.blink_start_time) > 0.150:
            set_servo_angle(12, 110)
            set_servo_angle(11, 0)
            set_servo_angle(15, 25)
            set_servo_angle(16, 85)
            self.is_blinking = False
            self.last_blink_time = current_time

            if not self.just_did_double and random.random() < 0.50:
                self.blink_interval = 0.150
                self.just_did_double = True
            else:
                self.blink_interval = random.uniform(1.5, 5.0)
                self.just_did_double = False

    # Helper function for user eye tracking
    def move_eyes(self):
        """
        Background thread routine governing global eye movements.
        Tracks the user's face if visible, otherwise executes sequence
        side-eye, looking around, and coming back to base position.
        """
        last_time = time.time()
        state = 0
        position = [80, 55, 80, 105]
        side_eye_left = {14: 110, 16: 35, 15: 40, 20: 80, 19: 80, 18: 70, 17: 130, 12: 110, 11: 0}
        side_eye_right = {14: 50, 12: 75, 11: 35, 17: 85, 18: 110, 20: 30, 19: 150, 15: 25, 16: 85}
        base_pos = {14: 80, 16: 85, 15: 10, 20: 50, 19: 160, 18: 70, 12: 110, 11: 0}

        sleep = [1.5, 0.5, 0.5, 1.5, 1.0, 2.0, 0.5, 2.0, 1.0]

        while True:
            is_side_eye = state in [5, 7]
            if not is_side_eye:
                self.eye_blink()

            if self.face_visible:
                bbox = self.bbox_cent
                if bbox is not None:
                    track_face(bbox[0], bbox[1])
            else:
                current_time = time.time()
                set_servo_angle(13, 60)

                current_delay = 0 if state == -1 else sleep[state]

                if current_time - last_time > current_delay:
                    state = (state + 1) % len(sleep)

                    if state < 4:
                        set_servo_angle(14, position[state])

                    elif state == 4:
                        for servo_id, angle in base_pos.items():
                            set_servo_angle(servo_id, angle)

                    elif state == 5:
                        for servo_id, angle in side_eye_left.items():
                            set_servo_angle(servo_id, angle)

                    elif state == 6:
                        for servo_id, angle in base_pos.items():
                            set_servo_angle(servo_id, angle)

                    elif state == 7:
                        for servo_id, angle in side_eye_right.items():
                            set_servo_angle(servo_id, angle)

                    elif state == 8:
                        for servo_id, angle in base_pos.items():
                            set_servo_angle(servo_id, angle)

                    last_time = current_time

            time.sleep(0.07)

    # Mouth movement during speech

    def move_mouth(self):
        """
        The mouth servo angle is seted
        based on the latest speech audio signal.
        """
        last_angle = -1
        l10, u10 = 45.0, 80.0
        while True:
            angle = float(self.mouth_angle)
            angle = l10 + (u10 - l10) * angle

            if angle != last_angle:
                set_servo_angle(10, angle)
                last_angle = angle
            time.sleep(0.05)

    def emotion_worker(self):
        """
        The emotion queue and triggers
        corresponding facial animations.
        Pauses animation execution if the robot is currently speaking.
        """
        while True:
            try:
                if time.time() - self.last_mouth_signal < 0.5:
                    time.sleep(0.05)
                    continue

                if self.emotion_queue:
                    emotion = self.emotion_queue.popleft()

                    if emotion not in (None, "None"):
                        self.is_animating = True
                        self.animate_emotion(emotion)
                        self.is_animating = False

                time.sleep(0.05)
            except Exception as e:
                print(f"[emotion_worker] error: {e}", flush=True)
                self.is_animating = False
                time.sleep(0.1)

    def map_emotion(self, raw_emotion):
        """
        Maps detected emotions to a simpler emotions.
        The robot can imitate only 4 emotions that's why
        they are maped.
        """
        if raw_emotion == 'fear':
            return 'surprise'
        if raw_emotion in ('angry', 'disgust'):
            return 'sad'
        return raw_emotion

    def animate_emotion(self, raw_emotion):
        """
        Executes a sequence of synchronized servo movements to physically mimic
        the specified emotion on the robot's face.
        """
        emotion = self.map_emotion(raw_emotion)
        steps = face_emo.get(emotion)
        if not steps:
            return
        for step in steps:
            for servo_id, angle in step:
                set_servo_angle(servo_id, angle)
        time.sleep(0.04)

    def run_console_listener(self):
        """
        Listens for commands from the system console-. Typing 's'
        triggers the face-saving workflow to record a new user's identity.
        """
        print("Save face: Type 's' + Enter here")
        while True:
            cmd = sys.stdin.readline().strip().lower()
            if cmd == 's':
                if self.last_feat is not None:
                    self.cleanup_db()
                    self.is_saving = True
                    print("\nFace detected. Enter person's name:")
                    name = sys.stdin.readline().strip()
                    if name:
                        cur = self.db.cursor()
                        cur.execute("INSERT INTO users (name, encoding) VALUES (?, ?)",
                                    (name, pickle.dumps(self.last_feat)))
                        self.db.commit()
                        self.db_names, self.db_vecs = self.load_users()
                        print(f"Saved: {name}\n")
                    self.is_saving = False
                else:
                    print("No face detected in frame\n")

    def generate_frames(self):
        """
        The main vision loop. Captures camera frames, runs face detection,
        alignment, recognition, and emotion prediction. Broadcasts state to external
        APIs and yields a JPEG-encoded frame stream for web rendering.
        """
        last_tick = time.time()
        while True:
            frame = self.picam2.capture_array()
            frame = cv2.flip(frame, -1)
            now = time.time()
            fps = 1 / (now - last_tick) if (now - last_tick) > 0 else 0
            last_tick = now

            h, w = frame.shape[:2]
            self.detector.setInputSize((w, h))
            _, faces = self.detector.detect(frame)

            payload = {
                "face_visible": False,
                "identity": "Unknown",
                "emotion": "Neutral",
                "bbox_center": [0, 0]
            }

            if faces is not None:
                main_face = max(faces, key=lambda f: f[2] * f[3])
                coords = main_face[:4].astype(int)
                bbox_center = [int(coords[0] + coords[2] / 2), int(coords[1] + coords[3] / 2)]
                self.bbox_cent = bbox_center
                self.face_visible = True

                aligned = self.recognizer.alignCrop(frame, main_face)
                feat = self.recognizer.feature(aligned)

                raw_identity = "Unknown"
                best_score = -1.0
                best_name = None

                if len(self.db_vecs) > 0:
                    for idx, db_vec in enumerate(self.db_vecs):
                        score = self.recognizer.match(feat, db_vec, cv2.FaceRecognizerSF_FR_COSINE)
                        if score > best_score:
                            best_score = score
                            best_name = self.db_names[idx]

                if best_score >= MATCH_THRESHOLD and best_name is not None:
                    raw_identity = best_name

                print(f"[VISION] best_match={best_name} score={best_score:.3f} -> {raw_identity}")

                # We use a 7-frame buffer and pick the most common identity
                # This prevents UI flickering and jumping if the camera loses focus or misclassifies a face for a split second
                self.id_buffer.append(raw_identity)
                counts = Counter(self.id_buffer)
                current_identity = counts.most_common(1)[0][0]

                # We run the emotion prediction model only every 15 frames
                if not self.is_session_active or current_identity != self.locked_identity or (self.f_count % 15 == 0):
                    self.last_feat = feat

                    crop = frame[max(0, coords[1]):coords[1] + coords[3],
                    max(0, coords[0]):coords[0] + coords[2]]
                    curr_emo = "neutral"
                    if crop.size > 0:
                        res = cv2.resize(cv2.cvtColor(crop, cv2.COLOR_BGR2RGB), (224, 224))
                        tensor = np.expand_dims(res.astype('float32') / 255.0, 0)
                        preds = self.emotion_net({'input_layer_1': tensor}, training=False).numpy()
                        curr_emo = EMOTIONS[np.argmax(preds)]

                    self.locked_identity = current_identity
                    self.locked_emotion = curr_emo
                    self.is_session_active = True

                    if curr_emo not in (None, "None"):
                        self.emotion_queue.append(curr_emo)

                self.face_lost_time = None
                payload["face_visible"] = True
                payload["identity"] = self.locked_identity
                payload["emotion"] = self.locked_emotion
                payload["bbox_center"] = bbox_center

                color = (0, 165, 255) if self.locked_identity == "Unknown" else (0, 255, 0)
                cv2.rectangle(frame, (coords[0], coords[1]),
                              (coords[0] + coords[2], coords[1] + coords[3]), color, 2)
                label = f"{self.locked_identity} - {self.locked_emotion}"
                cv2.putText(frame, label, (coords[0], coords[1] - 10),
                            cv2.FONT_HERSHEY_SIMPLEX, 0.6, (255, 255, 255), 2)
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

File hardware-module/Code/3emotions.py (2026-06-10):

import time
import random
import board
import busio
from adafruit_pca9685 import PCA9685
from adafruit_motor import servo

# Inicjalizacja magistrali I2C i sterowników
i2c = busio.I2C(board.SCL, board.SDA)
driverSO = PCA9685(i2c, address=0x40)
driverR = PCA9685(i2c, address=0x41)

driverSO.frequency = 50
driverR.frequency = 50

# Zmienne dla mrugania
last_blink_time = 0
blink_interval = 2.0
is_blinking = False
blink_start_time = 0

# Konfiguracja serw (id: {sterownik, pin, min, max, wlaczone})
# sterownik: 0 = driverSO, 1 = driverR
servos_config = {
    0:  {'driver': 0, 'pin': 0,  'min': 0,  'max': 180, 'wlaczone': False}, # jezyk
    1:  {'driver': 0, 'pin': 1,  'min': 80, 'max': 125, 'wlaczone': False},  # szczeka max otwarta 80, zamknieta 125
    2:  {'driver': 0, 'pin': 2,  'min': 50, 'max': 65,  'wlaczone': True},  # prawy korner gorne
    3:  {'driver': 0, 'pin': 3,  'min': 20, 'max': 80,  'wlaczone': True},  # prawa warga gorna
    4:  {'driver': 0, 'pin': 4,  'min': 50, 'max': 70,  'wlaczone': True},  # prawy korner dolne
    5:  {'driver': 0, 'pin': 5,  'min': 25, 'max': 92,  'wlaczone': True},  # prawa warga dolna
    6:  {'driver': 0, 'pin': 6,  'min': 45, 'max': 110, 'wlaczone': True},  # lewa warga dolna
    7:  {'driver': 0, 'pin': 7,  'min': 40, 'max': 60,  'wlaczone': True},  # lewy korner dolne
    8:  {'driver': 0, 'pin': 8,  'min': 35, 'max': 85,  'wlaczone': True},  # lewa gorna warga
    9:  {'driver': 0, 'pin': 9,  'min': 10, 'max': 40,  'wlaczone': True},  # lewy korner gorne
    10: {'driver': 0, 'pin': 10, 'min': 45, 'max': 80,  'wlaczone': True},  # szczeka niezjarana
    
    11: {'driver': 1, 'pin': 0,  'min': 0,  'max': 80,  'wlaczone': True},  # prawe oko dolna powieka
    12: {'driver': 1, 'pin': 1,  'min': 30, 'max': 115, 'wlaczone': True},  # gorna powieka
    13: {'driver': 1, 'pin': 2,  'min': 40, 'max': 120, 'wlaczone': True},  # oczy gora-dol
    14: {'driver': 1, 'pin': 3,  'min': 50, 'max': 150, 'wlaczone': True},  # oczy prawo-lewo
    15: {'driver': 1, 'pin': 4,  'min': 20, 'max': 90,  'wlaczone': True},  # lewe oko gorna powieka
    16: {'driver': 1, 'pin': 5,  'min': 25, 'max': 90,  'wlaczone': True},  # lewe oko dolna powieka
    17: {'driver': 1, 'pin': 6,  'min': 70, 'max': 150, 'wlaczone': True},  # prawa brew zewnatrz
    18: {'driver': 1, 'pin': 7,  'min': 70, 'max': 160, 'wlaczone': True},  # prawa brew srodek
    19: {'driver': 1, 'pin': 8,  'min': 80, 'max': 170, 'wlaczone': True},  # lewa brew srodek
    20: {'driver': 1, 'pin': 9,  'min': 20, 'max': 100, 'wlaczone': True}   # lewa brew zewnatrz
}

# Utworzenie obiektów serw
servo_objects = {}
for servo_id, cfg in servos_config.items():
    drv = driverSO if cfg['driver'] == 0 else driverR
    servo_objects[servo_id] = servo.Servo(drv.channels[cfg['pin']], min_pulse=730, max_pulse=2930)

def set_servo_angle(num, angle, use_margin=False):
    """Główna funkcja ustawiająca kąt serwa z uwzględnieniem limitów i zabezpieczeń."""
    cfg = servos_config.get(num)
    if not cfg or not cfg['wlaczone']:
        return
    
    margin = 5 if use_margin else 0
    # Ustalenie faktycznego minimum i maksimum (zabezpieczenie gdy min > max w słowniku)
    limit_min = min(cfg['min'], cfg['max']) + margin
    limit_max = max(cfg['min'], cfg['max']) - margin
    
    # Ograniczenie kąta do dozwolonego zakresu
    safe_angle = max(limit_min, min(angle, limit_max))
    
    # Ustawienie kąta sprzętowo
    servo_objects[num].angle = safe_angle

def move_eye_servo(num, angle):
    """Funkcja pomocnicza zachowana dla animacji z marginesem 5 stopni."""
    set_servo_angle(num, angle, use_margin=True)

def handle_random_blink():
    global last_blink_time, is_blinking, blink_start_time, blink_interval
    current_time = time.time()

    if not is_blinking and (current_time - last_blink_time) > blink_interval:
        is_blinking = True
        blink_start_time = current_time
        
        move_eye_servo(12, 35)
        move_eye_servo(11, 75)
        move_eye_servo(15, 85)
        move_eye_servo(16, 30)

    if is_blinking and (current_time - blink_start_time) > 0.150:
        move_eye_servo(12, 110)
        move_eye_servo(11, 0)
        move_eye_servo(15, 25)
        move_eye_servo(16, 85)
        
        is_blinking = False
        last_blink_time = current_time
        blink_interval = random.uniform(1.5, 5.0)

def animate_eyes_complex():
    print("Start animacji: Skosy i mruganie... (Ctrl+C aby przerwać)")
    try:
        while True:
            handle_random_blink()
            move_eye_servo(14, 145); time.sleep(0.4)
            move_eye_servo(14, 55);  time.sleep(0.4)
            
            move_eye_servo(14, 55); move_eye_servo(13, 115); time.sleep(0.6)
            move_eye_servo(14, 145); move_eye_servo(13, 45); time.sleep(0.6)
            move_eye_servo(14, 145); move_eye_servo(13, 115); time.sleep(0.6)
            move_eye_servo(14, 55); move_eye_servo(13, 45); time.sleep(0.6)
            
            move_eye_servo(14, 100); move_eye_servo(13, 60)
    except KeyboardInterrupt:
        print("\nAnimacja zatrzymana.")

def animate_radosc():
    print("Start animacji radosc")
    moves = [
        [(14, 100), (13, 60)],
        [(11, 50), (12, 95), (15, 40), (16, 55)],
        [(10, 45)],
        [(19, 110), (18, 130)],
        [(20, 50), (17, 110)],
        [(3, 65), (8, 35), (5, 50), (6, 75)],
        [(2, 100), (4, 30), (7, 110), (9, 10)]
    ]
    for step in moves:
        for servo_id, angle in step:
            move_eye_servo(servo_id, angle)
        time.sleep(0.04)
    print("Koniec animacji radosc")

def animate_smutek():
    print("Start animacji smutek")
    moves = [
        [(14, 100), (13, 60)],
        [(11, 25), (12, 95), (15, 40), (16, 70)],
        [(10, 45)],
        [(19, 110), (18, 130)],
        [(20, 100), (17, 70)],
        [(3, 20), (8, 85), (5, 40), (6, 100)],
        [(2, 40), (4, 50), (7, 30), (9, 60)]
    ]
    for step in moves:
        for servo_id, angle in step:
            move_eye_servo(servo_id, angle)
        time.sleep(0.04)
    print("Koniec animacji smutek")

def animate_szok():
    print("Start animacji szok")
    moves = [
        [(14, 100), (13, 60)],
        [(11, 0), (12, 115), (15, 20), (16, 90)],
        [(10, 80)],
        [(19, 170), (18, 70)],
        [(20, 20), (17, 150)],
        [(3, 20), (8, 85), (5, 90), (6, 45)],
        [(2, 65), (4, 60), (7, 50), (9, 40)]
    ]
    for step in moves:
        for servo_id, angle in step:
            move_eye_servo(servo_id, angle)
        time.sleep(0.04)
    print("Koniec animacji szok")
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

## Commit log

2026-03-06 changed nozzle temp to 210°C, added all needed gcodes. NOTE: plate5 may need to be printed in TPU - print as last
2026-03-09 added devided and organized STL files
    [base.stl, baseClamp1.stl, baseClamp2.stl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]
2026-03-10 Create printing-progress.md
    File to mark printing progress.
2026-03-11 printed frontPlate
2026-03-12 Updated print checklist
2026-03-12 printing status update
2026-03-12 added gCode for Rise3D printer
2026-03-13 printing status update - skullFrame third failure
2026-03-14 frame extras and mouth parts printed + problems update
2026-03-15 remodeled and scaled eyes.stl
    [eyes.stl]
2026-03-16 succesfully printed TPU brows
2026-03-16 eyes gCode for rise3D printer
2026-03-16 eyes printing failure - new brim settings
2026-03-17 printing status update - eyes printed
2026-03-18 printing status update - printed lid(1-4), eyeCorePivotHolder
2026-03-19 printing update status - skullframe gcode v6
    [bambulab_skullFrame_v5.gcode.3mf]
2026-03-19 one MG90S servo is not working
2026-03-19 problem update - parts broken during assembly
    [bambulab_rampMount1.gcode.3mf, bambulab_topLidHorn1-4_nS_threeAngles.gcode.3mf, topLidHorn1.3mf]
2026-03-20 printing status upadte - skullFrame 6-th failure
2026-03-20 printing status update - skullFrame part succesfully repaired
    [skullFrame_cuttedHorns.gcode.3mf, skullFrame_horns.3mf]
2026-03-20 assembly and printing update
    [bambulab_eyeAdaptor3_ns.gcode.3mf, eyeAdaptor3.3mf]
2026-03-21 Added ResNet50 second training results and performance plots
    Updated training_details.tex with ResNet50 optimized two-stage training strategy (75.22% accuracy). Added confusion matrices and training history plots for ResNet50 and ResNet101 runs.
2026-03-21 Sucesfull test for servo controler
2026-03-23 printing status update - chechBone, centralServoHorn, eyeAdaptor parts reprinted
2026-03-23 Revert "Hardware module"
    [bambulab_eyeAdaptor3_ns.gcode.3mf, bambulab_rampMount1.gcode.3mf, bambulab_skullFrame_v5.gcode.3mf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]
2026-03-24 Uploaded raports and last code for steering all servos
2026-03-25 printing status update - topLidHorn1 and link2a printed, rearPlate failure
2026-03-25 jetson test files
2026-03-26 added current cost_estimate
2026-03-26 printing status update - printed rearPlate
2026-03-26 added a fixed model temperature
2026-03-27 Add head movement servo mapping iamge
2026-03-30 pipeline for jetson v2
2026-03-30 Fixing pipeline for jetson
2026-04-02 added camera diagnostic script for RPi 5 and Camera v2
2026-04-02 final stable diagnostic camera stream for RPi 5; Milestone 2 hardware validation
2026-04-08 nlp fix for jetson
2026-04-08 nlp for jetson fix
2026-04-08 measured top neck v1
    [top_neck_v1.stl]
2026-04-08 time profiling for jetson
2026-04-09 Photos of failed prints
    Added photos of failed prints.
2026-04-09 Photos of failed prints
    I've added more photos of the failed prints. We were never able to print this part completely successfully.
2026-04-09 nlp pipeline jetson fix
2026-04-09 new llm model for jetson
2026-04-09 removed gcode due to github file size restrictions
    [bambulab_eyeAdaptor3_ns.gcode.3mf, bambulab_rampMount1.gcode.3mf, bambulab_skullFrame_v5.gcode.3mf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]
2026-04-09 added 3D models of components
    [base.stl, baseClamp1.stl, baseClamp2.stl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]
2026-04-12 Photo generation stages sections added
    Added a new section in the technical documentation, added training results in the training_details documentation and organized the folders
2026-04-13 Created file with all servos tested limit angles.
2026-04-15 neck_bottom wider, more holes for heat inserts
    [neck_bottom.stl]
2026-04-15 Updated servos limit decription file
2026-04-16 base assembly
    [POS-150-C power supply.f3d]
2026-04-16 Update servos_limit_angles.txt
    Updated angles after nuts replacement.
2026-04-17 RPI cooling and temperature monitoring script
2026-04-17 Technical Documentation with Raspberry Pi 5 active cooling results
2026-04-20 mount holes for M5, Succesfully printed
    [neck-bottom_V3.stl, neck-upper_V3.stl, neck_bottom.stl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]
2026-04-20 Cleand up hardware module
    [base.stl, baseClamp1.stl, baseClamp2.stl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]
2026-04-20 base main and frame stl and sembly files added
    [base-frame.stl, base-main.stl]
2026-04-20 updated printing list
2026-04-24 printing update - printed base-main
2026-04-25 printing update - base-frame printing failure
2026-04-26 Update technical documentation with Jetson integration, technical challenges, and privacy sections
2026-04-27 printing status update: printed base-frame
2026-04-27 thinner base version
    [neck-upper_V3.stl, neck-upper_V4.stl]
2026-05-13 camera flip
2026-05-14 Added hardware assembly notes and magnets for artificial skin attachment
2026-05-15 added 14.05.26r. report, made to-reprint list, and uploaded cam-holder.stl
    [3.stl, 38.stl, cam_holder_V2.stl]
2026-05-16 printed succesfully, but needs a lot of sanding
2026-05-18 added microphone-wall 3d model
    [microphone-wall.stl]
2026-05-18 modified base-frame 3d model
    [base-frame.stl]
2026-05-18 updated base-assembly
2026-05-18 added normal-wall 3d model
    [normal-wall.stl]
2026-05-18 updated base assembly
    [Base Assembly.stl]
2026-05-18 printing list update
2026-05-18 added mirophone-sensor-wall 3D file
    [microphone-sensor-wall.stl]
2026-05-19 added sensor 3D model
    [sensor.stl]
2026-05-19 added short-wall 3D model and updated base-assembly
    [short-wall.stl]
2026-05-19 printing update: printed normall-wall x3 and microphone wall
2026-05-19 added wall-short-sensor-microphone 3d model
    [wall-short-sensor-mirophone.stl]
2026-05-23 update printing-progress: printed microphone-sensor-wall
2026-06-02 Fix emotion blocking for recognized users and add code comments
    [main_vision_network.py]
2026-06-05 modifed cam_holder 3D model - version 3
    [cam holder v3.stl, cam_holder_V2.stl]
2026-06-05 printing status update: printed cam-holder_v3
2026-06-05 mofied cam-holder-v3 3D model
    [cam holder v3.stl, cam-holder-v3.stl]
2026-06-06 modified base walls
    [normal-wall.stl, short-wall.stl, wall-normal_v2.stl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]
2026-06-10 fix fix fix fix
    [main_vision_network.py]
2026-06-10 changed name
    [base-frame.stl, base-main.stl, base.stl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]

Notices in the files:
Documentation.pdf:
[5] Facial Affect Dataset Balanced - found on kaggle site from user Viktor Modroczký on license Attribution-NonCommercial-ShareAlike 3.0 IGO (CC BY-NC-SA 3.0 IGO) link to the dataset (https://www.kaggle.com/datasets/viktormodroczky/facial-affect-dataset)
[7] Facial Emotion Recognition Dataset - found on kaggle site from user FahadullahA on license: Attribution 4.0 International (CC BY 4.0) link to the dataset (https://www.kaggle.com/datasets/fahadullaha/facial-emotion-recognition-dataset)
